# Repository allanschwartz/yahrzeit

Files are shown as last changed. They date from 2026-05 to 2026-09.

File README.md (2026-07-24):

# Yahrzeit Project Introduction

<a href="docs/images/yahrzeit-project-overview.png">
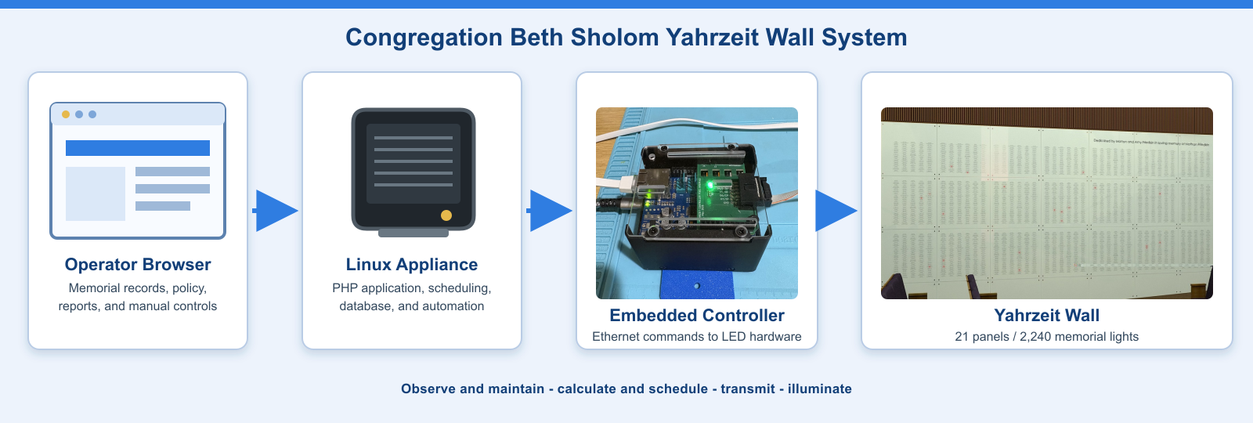
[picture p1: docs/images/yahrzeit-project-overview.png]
Congregation Beth Sholom Yahrzeit Wall system overview
  
</a>

*The operator interface and Linux appliance calculate and schedule memorial
lighting, while the embedded controller drives the physical Yahrzeit Wall.*

This repository contains the full Yahrzeit Wall system for Congregation Beth Sholom: the web appliance, scheduling logic, embedded controller firmware, LED hardware designs, and supporting documentation.

## What the project does

The system tracks memorial (Yahrzeit) records, determines when lights should be on, and sends commands to the physical wall so that the correct LEDs illuminate at the correct times.

## Repository layout

- `yahrzeit_site-v3/` — current PHP web application for viewing and editing memorial records, configuring synagogue policy, and running reports.
- `yahrzeit_site-v2/` — earlier web site implementation.
- `embedded/` — firmware and controller software for the embedded wall controller.
  - `yahrzeit_v1/` — original controller implementation.
  - `yahrzeit_v2/` — Arduino-based development work.
  - `yahrzeit_v3/` — newer controller and threading-based implementation.
- `Hardware/` — PCB and enclosure design files, schematics, and related hardware documentation.
- `panels/` — stored panel layouts and panel master assets used by the display system.
- `presentations/` — presentation materials and images related to the project.

## System overview

1. The web application stores memorial data and synagogue settings.
2. The scheduling/engine logic decides which names and panels should be lit.
3. The embedded controller receives commands and drives the LED wall.
4. The hardware layer defines the pixel boards, wiring, and panel geometry.

## Key concepts

- **Yahrzeit Wall** — the physical LED display.
- **Yahrzeit Appliance** — the software environment used by operators to manage the wall.
- **Embedded Controller** — the controller that talks to the LEDs.
- **Pixel Board / Light Engine** — the physical LED modules that make up the display.
- **Minhag / Lighting Policy** — synagogue-specific rules that determine when observances are active.

## Notes for contributors

- The current web application lives under [yahrzeit_site-v3](yahrzeit_site-v3).
- The embedded controller work is separate from the PHP appliance and should be treated as its own hardware/software subsystem.
- If you are updating documentation, prefer clear, project-level explanations that describe how the pieces fit together.

## See Also

- **Project**
  - [`./README.md`](README.md)
- **Server**
  - [`./yahrzeit_site-v3/README.md`](yahrzeit_site-v3/README.md)
  - [`./yahrzeit_site-v3/INSTALL.md`](yahrzeit_site-v3/INSTALL.md)
- **Controller**
  - [`./embedded/yahrzeit_v3/README.md`](embedded/yahrzeit_v3/README.md)
  - [`./embedded/yahrzeit_v3/INSTALL.md`](embedded/yahrzeit_v3/INSTALL.md)
- **Hardware**
  - [`./Hardware/README.md`](Hardware/README.md)

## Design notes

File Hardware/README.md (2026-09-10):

# Yahrzeit Wall Hardware

This directory contains the electrical and mechanical design files for the
Yahrzeit Wall controller, interface board, pixel boards, test fixtures, and
enclosures.

The current controller uses an Arduino Uno R4, an Arduino-compatible Ethernet
shield, and the Yahrzeit Controller Pixel Interface V3 board. The interface
board connects the controller stack to the installed chain of YYZ Pixel boards.

<a href="3D%20Printing/fixture_plate.jpg">
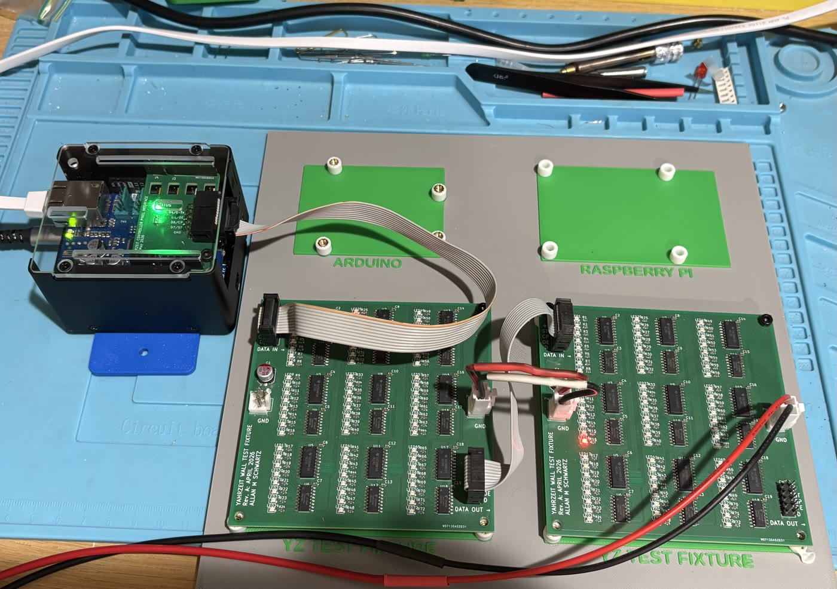
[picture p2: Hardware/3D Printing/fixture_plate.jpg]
Yahrzeit controller and YYZ Pixel bench-test fixture
  
</a>

*The bench-test fixture brings together the controller stack, Pixel Interface
board, and two nine-section YYZ Pixel boards.*

## 3D-Printed Parts

The files under [`3D Printing`](3D%20Printing/) may be browsed
online, with GitHub displaying the JPEG photographs and interactive previews of
the STL models.

### Commercial Controller Enclosure

- [arduino\_uno\_r4\_commercial\_enclosure\_vendor.jpg](3D%20Printing/arduino_uno_r4_commercial_enclosure_vendor.jpg)
  -- Vendor product photograph, saved from the Amazon listing, showing the
  commercial enclosure with an Arduino Uno R4 and an Ethernet-shield stack.

### Production Mounting Flange

The production controller uses a commercial enclosure with a custom
3D-printed flange that adapts its DIN-rail mounting feature for flat wall
mounting.

- [mount\_flange.scad](3D%20Printing/mount_flange.scad) -- Parametric OpenSCAD
  source.
- [mount\_flange.stl](3D%20Printing/mount_flange.stl) -- Printable mounting
  flange.

### Alternative Controller Enclosure

This enclosure was designed for the three-board controller stack. The
close-fitting commercial enclosure documented in the embedded-controller
installation notes is the preferred production enclosure, but this printable
design is retained as a replacement option and design reference.

- [yahrzeit\_controller\_case.scad](3D%20Printing/yahrzeit_controller_case.scad)
  -- Parametric OpenSCAD source.
- [yahrzeit\_controller\_case.stl](3D%20Printing/yahrzeit_controller_case.stl)
  -- Printable enclosure body.
- [yahrzeit\_controller\_case-cover.stl](3D%20Printing/yahrzeit_controller_case-cover.stl)
  -- enclosure cover.
- [yahrzeit\_controller\_case.jpg](3D%20Printing/yahrzeit_controller_case.jpg)
  -- Photograph of the printed enclosure body.

### Test-Fixture Plate

The fixture plate supports the small YYZ Pixel test assembly used during
controller development and bench testing.

- [fixture\_plate.scad](3D%20Printing/fixture_plate.scad) -- Parametric OpenSCAD
  source.
- [fixture\_plate.stl](3D%20Printing/fixture_plate.stl) -- Printable fixture
  plate.
- [fixture\_plate.jpg](3D%20Printing/fixture_plate.jpg) -- Photograph of the
  printed fixture plate.

## Yahrzeit Controller Pixel Interface V3

<a href="pixel_interface_v3/pixel_interface_v3-3D%20viewer.png">
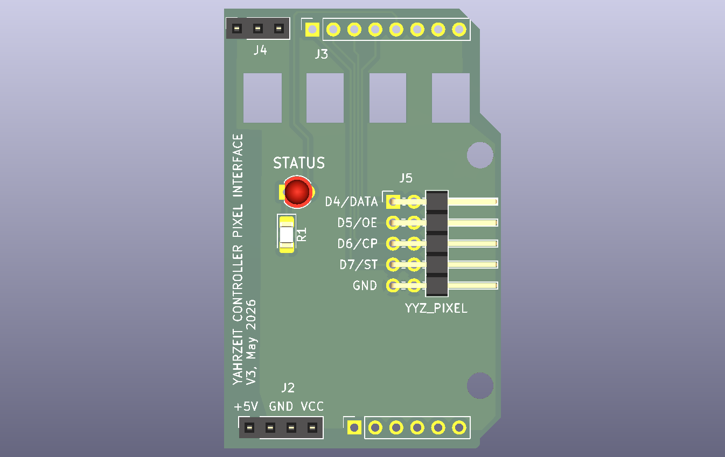
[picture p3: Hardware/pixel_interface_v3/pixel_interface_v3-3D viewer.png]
Yahrzeit Controller Pixel Interface V3 board
  
</a>

*KiCad rendering of the Yahrzeit Controller Pixel Interface V3 board.*

The current interface board adapts the Arduino controller stack to the
five-signal YYZ Pixel ribbon cable and provides the green ALIVE status LED.

- [pixel\_interface\_v3.kicad\_pro](pixel_interface_v3/pixel_interface_v3.kicad_pro)
  -- Open this project file in KiCad.
- [pixel\_interface\_v3.kicad\_sch](pixel_interface_v3/pixel_interface_v3.kicad_sch)
  -- KiCad schematic.
- [pixel\_interface\_v3.kicad\_pcb](pixel_interface_v3/pixel_interface_v3.kicad_pcb)
  -- KiCad PCB layout.
- [pixel\_interface\_v3-3D viewer.png](pixel_interface_v3/pixel_interface_v3-3D%20viewer.png)
  -- KiCad 3D rendering.
- [pixel\_interface\_v3-schematic.png](pixel_interface_v3/pixel_interface_v3-schematic.png)
  -- Schematic preview.
- [pixel\_interface\_v3\_D1\_polarity\_note.pdf](pixel_interface_v3/pixel_interface_v3_D1_polarity_note.pdf)
  -- Status-LED polarity and assembly note.

## Nine-Section YYZ Pixel Board

<a href="yahrzeit_pixel9/yahrzeit_pixel9.png">
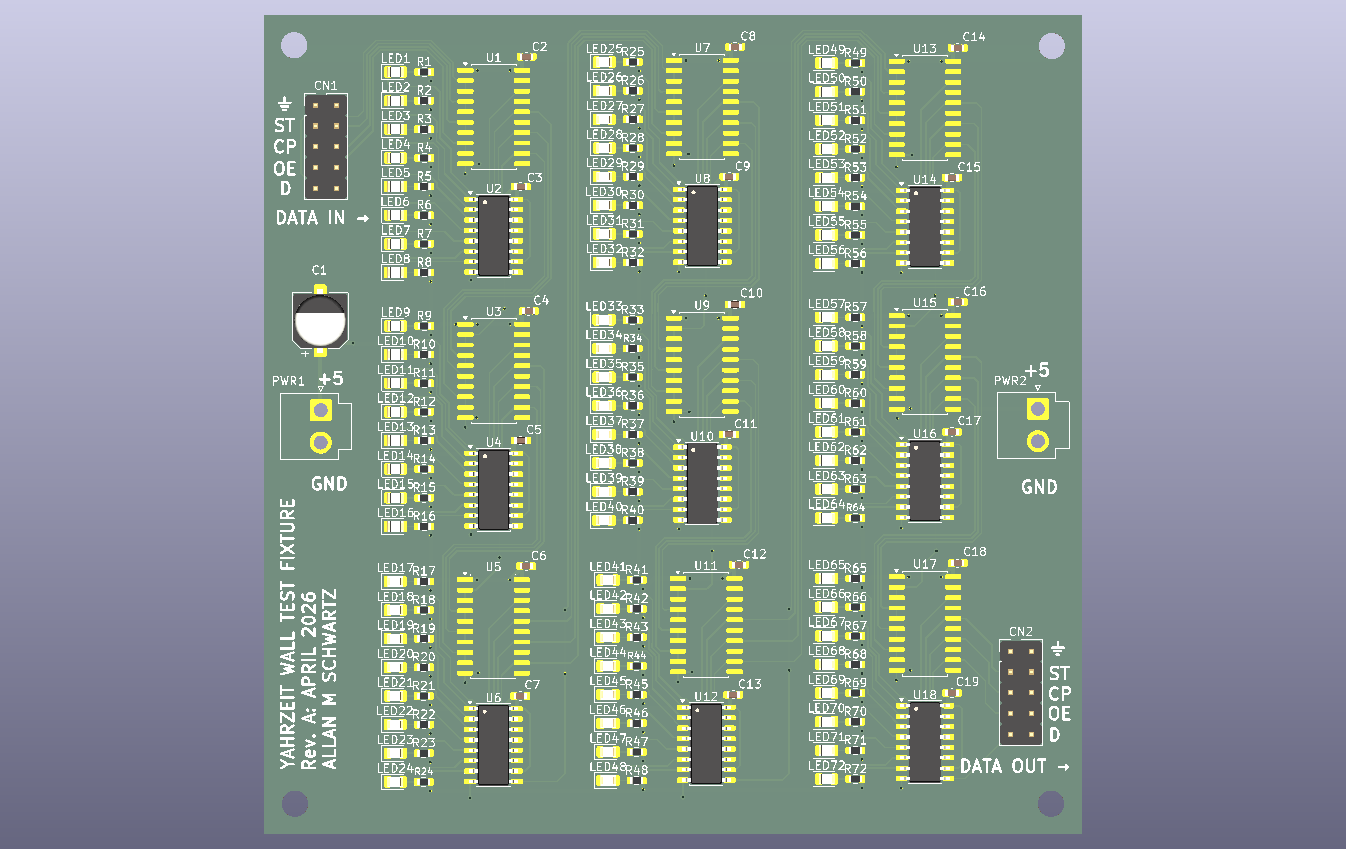
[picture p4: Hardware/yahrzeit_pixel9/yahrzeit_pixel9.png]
Nine-section YYZ Pixel board
  
</a>

*KiCad rendering of the nine-section YYZ Pixel board.*

The `yahrzeit_pixel9` board combines nine complete YYZ Pixel circuits on one PCB, using the same octal bus transceiver and 8-bit shift register as the individual boards installed in the wall. A single `yahrzeit_pixel9` behaves as one complete Yahrzeit Wall panel, allowing a desktop test fixture to be constructed. Two or more yahrzeit_pixel9 boards may be chained together to emulate multiple panels.

<a href="schematics/yyz_pixel_8_pixel_hierarchical_sheet.png">
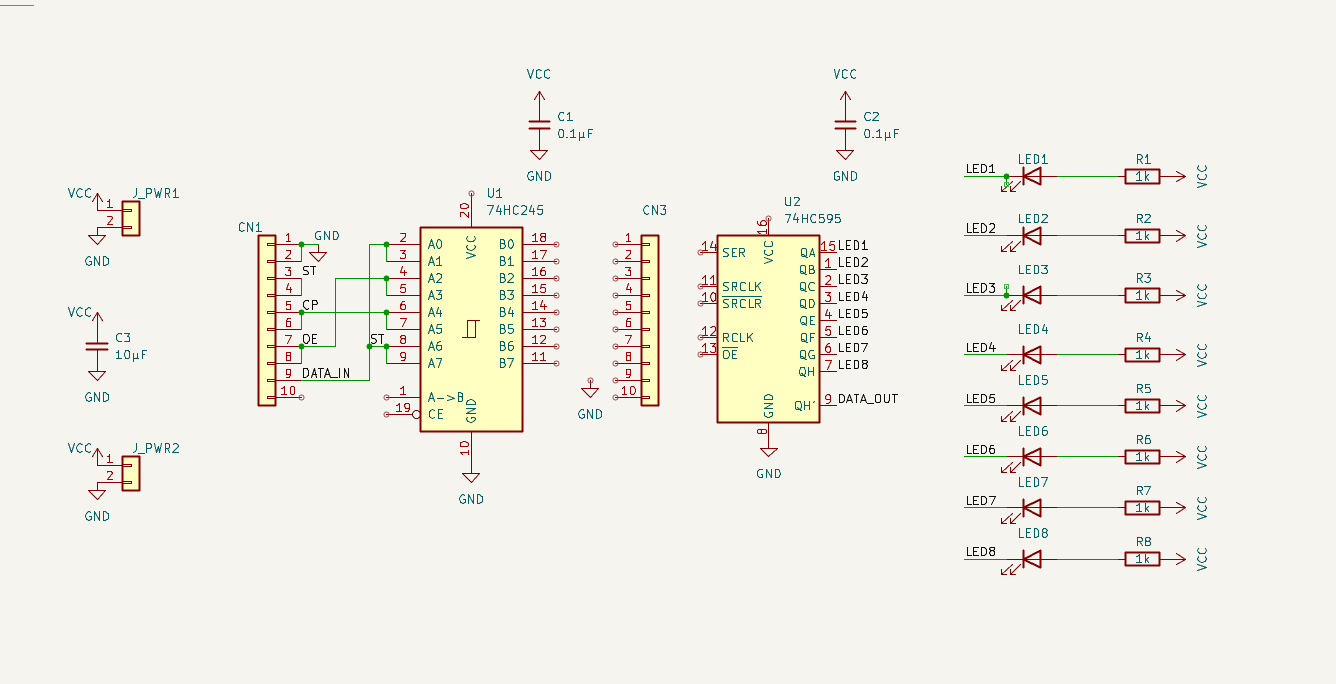
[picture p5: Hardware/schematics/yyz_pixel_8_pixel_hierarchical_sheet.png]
Reusable eight-pixel YYZ Pixel hierarchical sheet
  
</a>

*The reusable KiCad hierarchical sheet implements one eight-pixel YYZ Pixel
circuit. The `yahrzeit_pixel9` top-level schematic instantiates this sheet nine
times.*

- [yahrzeit\_pixel9.kicad\_pro](yahrzeit_pixel9/yahrzeit_pixel9.kicad_pro) --
  Open this project file in KiCad.
- [yahrzeit\_pixel9.kicad\_sch](yahrzeit_pixel9/yahrzeit_pixel9.kicad_sch) --
  KiCad top-level schematic.
- [pblock.kicad\_sch](yahrzeit_pixel9/pblock.kicad_sch) -- Reusable
  eight-pixel hierarchical sheet.
- [yahrzeit\_pixel9.kicad\_pcb](yahrzeit_pixel9/yahrzeit_pixel9.kicad_pcb) --
  KiCad PCB layout.
- [yahrzeit\_pixel9-schematic.pdf](yahrzeit_pixel9/yahrzeit_pixel9-schematic.pdf)
  -- multipage schematic.
- [yahrzeit\_pixel9.png](yahrzeit_pixel9/yahrzeit_pixel9.png) -- KiCad board
  rendering.

## YYZ Pixel Board V2

<a href="yahrzeit_yyz_pixel-v2/yyz_pixel-v2%20schematic.png">
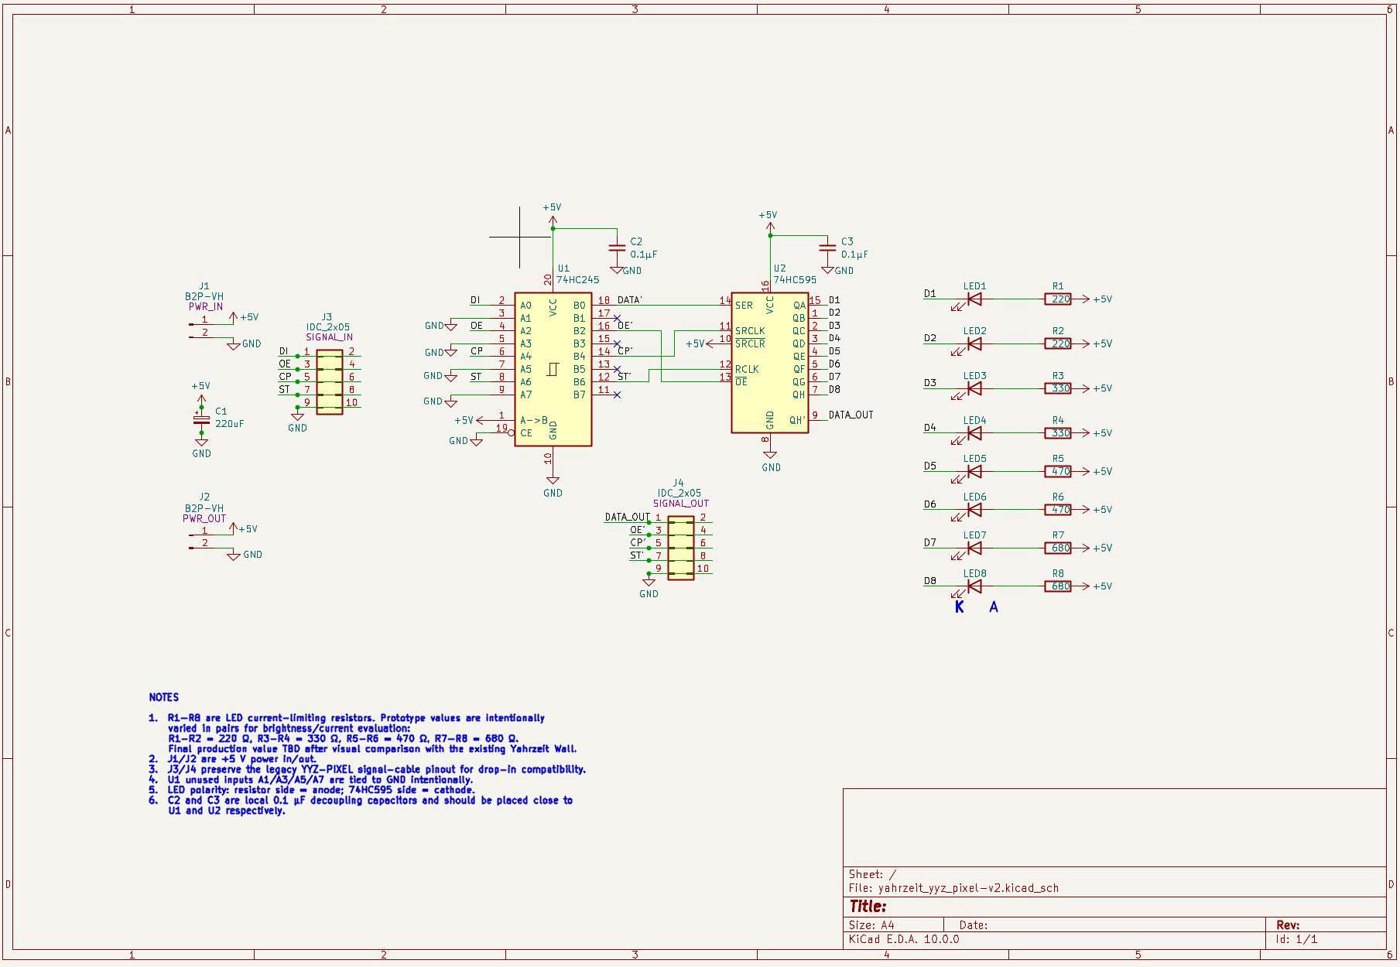
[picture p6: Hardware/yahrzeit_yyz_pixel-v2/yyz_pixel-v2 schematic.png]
YYZ Pixel Board V2 schematic
  
</a>

*Schematic of the preliminary YYZ Pixel Board V2 design.*

YYZ Pixel Board V2 is a proposed modern replacement for an individual
installed pixel board. It retains the legacy 74HC245 input buffer, 74HC595
shift register, 5 V power daisy chain, and 2x5 signal-cable interface so that
it can be evaluated with the existing wall and controller. The present
prototype provides eight LED channels. Its LED resistors intentionally use
four different values, in pairs, so brightness and current can be compared
with the original wall before a production value is selected.

This is design work in progress, not a released production board. Connector
part numbers, the final LED resistor value, cable construction, power margin,
and mechanical fit must be confirmed before fabrication or installation.

- [yahrzeit\_yyz\_pixel-v2.kicad\_pro](yahrzeit_yyz_pixel-v2/yahrzeit_yyz_pixel-v2.kicad_pro)
  -- Open this project file in KiCad.
- [yahrzeit\_yyz\_pixel-v2.kicad\_sch](yahrzeit_yyz_pixel-v2/yahrzeit_yyz_pixel-v2.kicad_sch)
  -- KiCad schematic.
- [yahrzeit\_yyz\_pixel-v2.kicad\_pcb](yahrzeit_yyz_pixel-v2/yahrzeit_yyz_pixel-v2.kicad_pcb)
  -- Preliminary KiCad PCB layout.
- [YYZ\_PIXEL\_V2\_CABLE\_AND\_POWER\_NOTES.md](YYZ_PIXEL_V2_CABLE_AND_POWER_NOTES.md)
  -- Field observations and deferred cable, signal-integrity, and power-design
  decisions.

## Column Power Distribution Board

<a href="yahrzeit_power_dist/yahrzeit_power_dist.png">
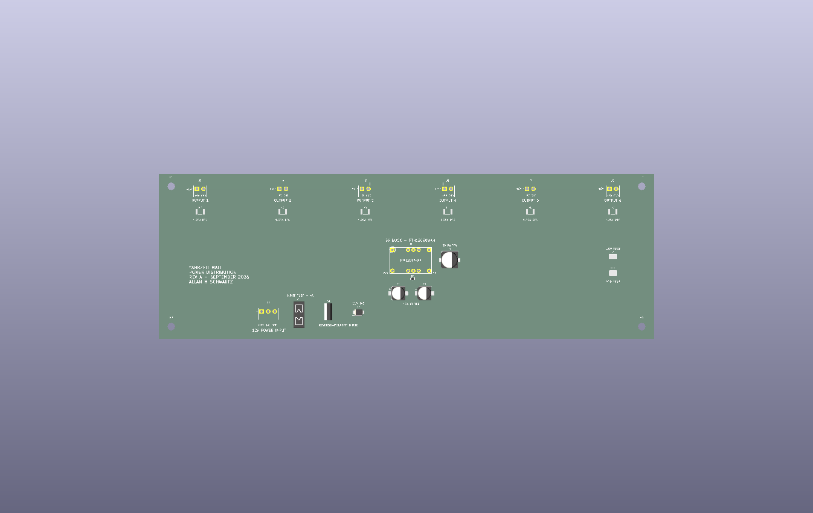
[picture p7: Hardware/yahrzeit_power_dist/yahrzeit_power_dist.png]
Yahrzeit Wall column power-distribution board
  
</a>

*Preliminary layout of the proposed column power-distribution board.*

The proposed power-distribution assembly replaces the direct 5 V supply and
wire-nut fan-out for one vertical panel column. One assembly serves six
56-LED branches. It accepts nominal 12 V input, uses a TI PTH12060WAH
through-hole module to produce regulated 5 V, and provides six individually
protected outputs. Input reverse-polarity and transient protection, local
filtering, clearly polarized connectors, and accessible 5 V/GND test points
make the assembly easier to diagnose and replace in the field.

The long-term concept uses one assembly for each of the wall's seven panel
columns, plus complete spare assemblies and purpose-built labeled cables. The
entire board-and-cable assembly is intended to be a field-replaceable unit.
The design remains preliminary: measured wall current, fuse ratings, thermal
performance, copper geometry, connector selections, cable lengths, and
installation clearances must be verified before production.

- [yahrzeit\_power\_dist.kicad\_pro](yahrzeit_power_dist/yahrzeit_power_dist.kicad_pro)
  -- Open this project file in KiCad.
- [yahrzeit\_power\_dist.kicad\_sch](yahrzeit_power_dist/yahrzeit_power_dist.kicad_sch)
  -- KiCad schematic.
- [yahrzeit\_power\_dist.kicad\_pcb](yahrzeit_power_dist/yahrzeit_power_dist.kicad_pcb)
  -- Preliminary PCB placement and routing.
- [power\_dist.schematic.pdf](yahrzeit_power_dist/power_dist.schematic.pdf) -- Current schematic
  PDF for review without KiCad.
- [yahrzeit\_power\_dist.png](yahrzeit_power_dist/yahrzeit_power_dist.png) --
  KiCad board rendering.
- [DESIGN\_TODO.md](yahrzeit_power_dist/DESIGN_TODO.md) -- Outstanding
  component-selection, indicator, layout, and pre-fabrication checks.

## Reference Schematics

Approximately 280 individual YYZ Pixel boards are installed behind the
Yahrzeit Wall's etched-glass memorial panels. Three variations support six,
eight, or ten memorial lights. Their common circuit is documented in:

- [Schematic\_yyz\_pixel.pdf](schematics/Schematic_yyz_pixel.pdf) -- Original
  installed YYZ Pixel board schematic.
- [YYZ\_PIXEL\_BOARD\_REPAIR.md](YYZ_PIXEL_BOARD_REPAIR.md) -- Customer procedure
  for replacing and verifying an installed pixel board using a tested spare.
- [YYZ\_PIXEL\_BOARD\_TESTING.md](YYZ_PIXEL_BOARD_TESTING.md) -- Optional
  engineering or electronics-technician procedure for bench-testing a removed
  board, including the special controller cable and Saleae logic-analyzer
  checks.
- [YYZ\_PIXEL\_V2\_CABLE\_AND\_POWER\_NOTES.md](YYZ_PIXEL_V2_CABLE_AND_POWER_NOTES.md)
  -- Deferred Version 2 design notes covering signal-cable construction,
  shielding and grounding alternatives, field cable-retention observations,
  and power-supply margin.
  
The nine-section board is electrically nine of these circuits condensed onto
one PCB. Both designs use the same 74HC245 octal bus transceiver and
74HC595 8-bit shift register:

- [74HC\_HCT245.pdf](schematics/74HC_HCT245.pdf) -- Bus-transceiver data sheet.
- [74HC\_HCT595.pdf](schematics/74HC_HCT595.pdf) -- Shift-register data sheet.

The [`schematics`](schematics/) directory also preserves the relevant Arduino
and Ethernet reference schematics.

## See Also

- **Project**
  - [`./README.md`](../README.md)
- **Server**
  - [`./yahrzeit_site-v3/README.md`](../yahrzeit_site-v3/README.md)
  - [`./yahrzeit_site-v3/INSTALL.md`](../yahrzeit_site-v3/INSTALL.md)
- **Controller**
  - [`./embedded/yahrzeit_v3/README.md`](../embedded/yahrzeit_v3/README.md)
  - [`./embedded/yahrzeit_v3/INSTALL.md`](../embedded/yahrzeit_v3/INSTALL.md)
- **Hardware**
  - [`./Hardware/README.md`](README.md)

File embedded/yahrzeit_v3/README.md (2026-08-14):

# Yahrzeit Embedded Controller

This directory contains the Arduino firmware for the third-generation
Yahrzeit Wall embedded controller.

This README is intended for future maintainers of the embedded controller.

The top-level repository README explains the full Yahrzeit project. The
`yahrzeit_site-v3` README explains the PHP/Linux appliance. This README is only
about the Arduino controller firmware in this directory. See `INSTALL.md` for
the production firmware build, upload, and verification procedure.

<p align="center">
  <a href="images/yahrzeit-controller-assembly.jpg">
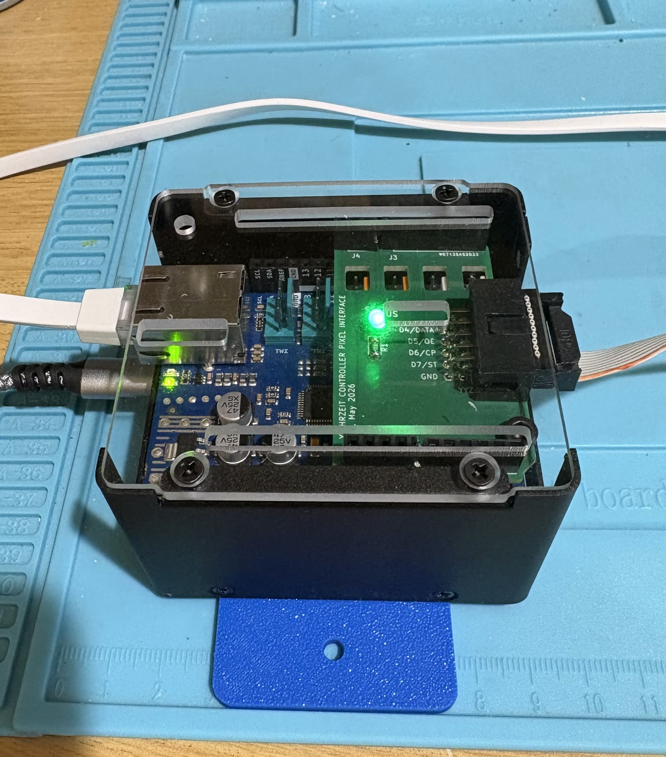
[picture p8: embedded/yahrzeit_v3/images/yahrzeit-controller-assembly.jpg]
Yahrzeit Embedded Controller V3 assembly
    
  </a>
</p>

*The assembled controller in its close-fitting enclosure. The illuminated
green LED on the Pixel Interface board is the ALIVE indicator.*

## What This Controller Does

The embedded controller:

- receives line-oriented ASCII commands over USB serial or Ethernet TCP,
- maintains the LED wall framebuffer,
- maps wall/panel coordinates to the physical pixel chain,
- refreshes the shift-register LED hardware,
- saves and loads display state through EEPROM,
- runs bring-up and self-test patterns,
- and reports status/version/network information for diagnostics.

The normal production control path is:

```text
PHP appliance bin/yahrzeit
  -> nc TCP connection
    -> Arduino Ethernet socket on port 2001
      -> socket_thread.ino
        -> CmdProc
          -> LedWall
            -> YyzPixel
```

The command line interface is normally accessed through a TCP connection,
and received in `socket_thread.ino`.  
However, USB serial uses the same command processor through `serial_thread.ino`.

## Hardware Stack

The V3 controller stack is:

```text
Arduino Uno R4 Minima
  -> Arduino Ethernet Shield 2 or compatible W5100/W5500 shield
    -> Yahrzeit Controller Pixel Interface board
      -> ribbon cable to YYZ Pixel board chain
```

### Ethernet Shield

The Ethernet shield uses the Arduino SPI interface; D10 is the chip select:

```text
D10     CS      Chip select
D11     MOSI    Master out, slave in  (aka COPI)
D12     MISO    Master in, slave out  (aka CIPO)
D13     SCK     Serial clock
```

## Pin Assignments

Pin definitions live in `yahrzeit_v3.ino`.

Names `DI`, `OE`, `CP`, `ST` match the pixel interface board silkscreen, and likewise the YYZ PIXEL boards silkscreen:

```text
STATUS LED  D3
DI          D4    data input (input to the PIXEL board)
OE          D5    output enable, active low
CP          D6    clock pulse
ST          D7    store/latch pulse
```

Do not change these casually; the shield/interface wiring depends on them.

## Source Files

- `yahrzeit_v3.ino` - setup, main loop, startup sequence, network defaults,
  pin definitions, global objects, status LED, panic handling.
- `yahrzeit_v3.h` - project-wide constants, active geometry selection,
  configuration structs, externs, assertion macros, shared declarations.
- `socket_thread.ino/.h` - Ethernet initialization and TCP command input.
- `serial_thread.ino/.h` - USB serial command input.
- `CmdProc.cpp/.h` - ASCII command parser and dispatcher.
- `LedWall.cpp/.h` - logical wall/panel abstraction and coordinate mapping.
- `YyzPixel.cpp/.h` - packed framebuffer and low-level shift-register driver.
- `selftest.ino/.h` - self-test patterns.

## Active Geometry

Select exactly one geometry in `yahrzeit_v3.h`:

```cpp
// #define CBS_56x40_WALL    1
#define TEST_FIXTURE    1
```

Current geometry definitions in `LedWall.cpp`:

```text
CBS_56x40_WALL:
  56 rows x 40 columns
  21 logical panels

TEST_FIXTURE:
  24 rows x 6 columns
  2 logical panels
  each fixture panel is 24 rows x 3 columns
```

For production installation, enable `CBS_56x40_WALL` and disable
`TEST_FIXTURE`.

## Network Defaults

Network defaults are in `yahrzeit_v3.ino`.

Production/CBS wall defaults:

```cpp
NetworkConfig networkConfig = {
    .mac = { 0x02, 0x19, 0x55, 0x11, 0x00, 0x09 },
        // Values used at Congregation Beth Sholom
        .ipAddr = IPAddress(192, 168, 13, 9),
        .dnsAddr = IPAddress(8, 8, 8, 8),
        .gateway = IPAddress(192, 168, 13, 8),
        .subnet = IPAddress(255, 255, 255, 0),
};

static constexpr uint16_t SOCKET_LISTEN_PORT = 2001;
```

There are also defaults for Allan's home-lab:

```text
IP       192.168.86.240
Gateway  192.168.86.1
Subnet   255.255.255.0
Port     2001
```

The PHP appliance reads the controller hostname/address and TCP port from
`bin/yahrzeit-controller.conf`. During installation, it offers the previously
recorded controller host as the default. The resulting appliance host and port
must match the values installed in the controller firmware.

## Ethernet Notes

`socket_thread.ino` supports W5100/W5200/W5500-class Ethernet hardware through the Arduino Ethernet library.

Startup serial output reports the detected Ethernet chip and local IP address.

The code treats only an explicit `LinkOFF` as unavailable. This matters because
some W5100-class hardware may not report link status as `LinkON` even when
socket communication works.

The `status` command reports the Arduino board model, selected display
configuration, dimensions, current brightness, configured network addresses
and TCP port, detected Ethernet hardware, link state, and whether a TCP client
is currently connected. It can be issued through USB Serial Monitor even when
TCP communication is not working, making it the primary tool for diagnosing
network problems.

The `version` command reports the Git-derived firmware release identifier and
the date and time at which the firmware was compiled. The release identifier
is generated as part of the build procedure documented in `INSTALL.md`.

## Serial Console

USB serial is initialized at:

```text
115200 baud
```

The serial path and socket path both feed the same command processor.

## Command Protocol

Commands are ASCII, line-oriented, and may usually be abbreviated to the first
two letters.

### Commands Used by the PHP Appliance

```text
All  on|off [<panel>]
BRightness <n> (1:bright, 254:dim)
PIxel on|off <row> <col> [<panel>]
REfresh
SAve
```

### Additional Controller Commands

```text
DAta <row> <col> <binary data>
LOad
```

### Maintenance and Diagnostic Commands

```text
DUmp [<panel>]
GEometry <rows> [<cols>]
HElp
STatus
TEst <testnumber> [<panel>]
TIming on|off
VErsion
```

`PANEL0` / panel `0` means the whole active display. Panels `1` through
`displayConfig.nPanels` address individual logical panels.

### Runtime test geometry

Use the `GEOMETRY` command to temporarily redefine the active display as one
continuous logical panel. The column count defaults to one:

```text
geometry 6
geometry 8
geometry 10
geometry 24 6
```

The configuration is cleared and remains active until the controller is
reset. Reset restores the geometry selected at compile time. Confirm the
runtime setting with `status`, then use the standard tests:

```text
test 2
test 3
test 4
test 5
```

For a single YYZ_PIXEL board, select its physical pixel count as the row count
and retain the default single column. The abbreviated command form, such as
`ge 8` and `te 5`, is also accepted.

## Self Tests

The `TEST` command supports:

```text
TEst 1 [<panel>]  -- 4 corners ON
TEst 2 [<panel>]  -- all pixels ON
TEst 3 [<panel>]  -- all pixels OFF
TEst 4 [<panel>]  -- checkerboard test
TEst 5 [<panel>]  -- marching row pattern
TEst 6 [<panel>]  -- marching column pattern
```

Use `*` in place of the optional panel number to repeat a test separately for
every physical panel, in panel-number order:

```text
test 1 *
test 5 *
```

An omitted panel still means the whole active display. For example, `test 1`
turns on the four corners of the complete wall, while `test 1 *` turns on the
four corners of each individual panel.

## Startup Behavior

On startup, `setup()`:

1. enables the status LED,
2. starts USB serial,
3. initializes Ethernet,
4. starts the command socket if Ethernet is available,
5. initializes the pixel driver and wall abstraction,
6. prints the version string,
7. runs a short light-test sequence,
8. loads the last saved framebuffer from EEPROM,
9. refreshes the display.

## Safe Bench Tests

Serial console:

```text
?
status
version
timing on
refresh
test 1
test 2
test 3
test 4
```

TCP socket from a machine on the same network:

```sh
nc <controller-ip> 2001
```

Then type the same line-oriented commands.

This is the direct test of TCP communication between the appliance and the
embedded controller. In particular, enter:

```text
version
status
```

For complete appliance-to-controller verification, follow the build, upload,
and commissioning procedure in [INSTALL.md](INSTALL.md).

## Building and Installing

See [INSTALL.md](INSTALL.md) for the known-working Arduino toolchain,
production geometry and network configuration, Git-derived release identifier,
firmware compilation and upload, verification tests, and installation record.

## Maintenance Warnings

- Do not change the command protocol unless the PHP appliance and embedded controller are updated at the same time.
- Do not change panel geometry without checking `LedWall.cpp` and PHP-side panel mapping.
- Do not leave home-lab IP addresses or `TEST_FIXTURE` enabled for production.
- Be careful with display refresh timing and framebuffer layout.
- Do not run live wall commands unless the physical wall can safely change state.

## See Also

- **Project**
  - [`./README.md`](../../README.md)
- **Server**
  - [`./yahrzeit_site-v3/README.md`](../../yahrzeit_site-v3/README.md)
  - [`./yahrzeit_site-v3/INSTALL.md`](../../yahrzeit_site-v3/INSTALL.md)
- **Controller**
  - [`./embedded/yahrzeit_v3/README.md`](README.md)
  - [`./embedded/yahrzeit_v3/INSTALL.md`](INSTALL.md)
- **Hardware**
  - [`./Hardware/README.md`](../../Hardware/README.md)

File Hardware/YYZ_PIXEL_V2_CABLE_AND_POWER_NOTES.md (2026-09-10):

# YYZ Pixel V2 Cable and Power Notes

**Status:** Deferred design work
**Recorded:** August 22, 2026

These notes preserve field observations and design alternatives to revisit
before releasing the YYZ Pixel V2 boards and cable assemblies for production.
They are not yet production requirements.

## Existing Wall Installation

The existing 10-conductor signal ribbon cables are routed flat and straight
against the rear of the continuous aluminum chassis. They are presently held
in place with ordinary blue painter's tape.

During the August 2026 service visit, one signal cable was found hanging loose
rather than adhered to the chassis. It was secured again. The loose cable may
have contributed to the observed intermittent signal or clock problems, but
this was not proven conclusively.

Keeping the ribbon cable flat against the aluminum may reduce movement, loop
area, and coupling from nearby wiring. Painter's tape is useful for temporary
field work, but its adhesive should not be treated as a long-term production
cable-retention method. Consider durable cable clips, tie mounts, or another
serviceable mechanical restraint for the Version 2 installation.

## Shielded Ribbon-Cable Options

Shielded cable compatible with 0.050-inch-pitch IDC mass termination is
commercially available. Candidate product families include:

- [3M 90204 Series](https://www.3m.com/3M/en_US/p/d/b00039655/) - flat,
  pleated-copper-foil shielded cable; 28 AWG; available with 10 conductors;
  intended for IDC mass termination.
- [3M 3659 Series](https://www.3m.com/3M/en_US/p/d/b00039391/) - round,
  shielded and jacketed flat cable with periodic flat sections for IDC
  termination; potentially useful for the approximately 2.8-meter long run.
- [3M 1785 Series](https://www.3m.com/3M/en_US/p/d/b00039714/) - shielded,
  twisted-pair flat cable; available as 10 conductors/five pairs; 28 AWG on
  0.050-inch centers.
- [3M HF017 Series](https://www.3m.com/3M/en_US/p/d/b10098196/) - shielded,
  IDC-compatible, low-smoke/zero-halogen cable that may be appropriate for a
  permanent installation in a public building.

A standard plastic 2x5 IDC socket does not terminate the cable shield.
Any shielded-cable specification must therefore define:

- how the shield or drain conductor exits the jacket;
- where it connects to chassis or circuit ground;
- whether it is connected at one end or both ends;
- strain relief at each jacket-to-ribbon transition; and
- the permitted length of unshielded ribbon at each connector.

Shielding alone may not correct the underlying signal-integrity problem.
Pairing each important signal, especially `CP`, with a ground conductor may be
more useful than retaining the legacy arrangement of duplicated adjacent
signals. Before completing CBL-05 and CBL-06, reconsider the signal pinout,
ground allocation, connector polarization, and whether the new system must
remain directly compatible with every legacy cable.

Current cable definitions are in [`cables/`](cables/):

- `CBL-05-idc-100mm.yml` - short board-to-board signal jumper.
- `CBL-06-idc-2800mm.yml` - provisional long signal interconnect.

Their rendered WireViz PDF drawings are working documents. Cable and connector
manufacturer part numbers still need to be selected before production.

## Power-Supply Margin

The installed supplies are nominally **5 V, 5 A**. At least one supply was
found to be bad during the August 2026 service work. The remaining design also
appears to operate close to the supplies' current limit when all LEDs are on.

The installed YYZ Pixel boards use **220-ohm LED current-limiting resistors**.
One supply powers approximately six columns by 56 rows, or 336 LEDs. Assuming
an LED forward voltage between 1.8 V and 2.2 V:

```text
Current per LED = (5 V - Vf) / 220 ohms

Vf = 1.8 V:  14.5 mA per LED; 336 LEDs = 4.89 A
Vf = 2.0 V:  13.6 mA per LED; 336 LEDs = 4.58 A
Vf = 2.2 V:  12.7 mA per LED; 336 LEDs = 4.28 A
```

This estimate covers LED current only. It leaves little or no allowance for:

- logic and controller current;
- voltage loss in connectors, cables, and distribution wiring;
- component tolerances;
- power-supply derating and aging; or
- transient behavior when the display changes.

Field testing showed that the affected sections behaved correctly with all
LEDs commanded on when output-enable PWM reduced average brightness/current.
That observation is consistent with inadequate power margin, although voltage
and current should be measured before selecting replacement supplies.

Before releasing the Version 2 design:

1. Measure actual current and voltage at the supply and at the farthest board
   with representative LEDs fully on.
2. Select the final Version 2 LED resistor value from visual and electrical
   testing.
3. Establish a continuous-current design target with suitable engineering
   margin rather than sizing the supply at the calculated maximum load.
4. Review connector, wire, fuse, and distribution-board ratings against that
   target.

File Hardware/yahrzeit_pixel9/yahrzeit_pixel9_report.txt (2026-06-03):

PCB statistics report
=====================
- Date: Wednesday, April 08, 2026 at 01:18:32 PM
- Project: yahrzeit_pixel
- Board name: yahrzeit_pixel

Board
-----
- Width: 100.0000 mm
- Height: 100.0000 mm
- Area: 10000.00 mm²
- Front copper area: 7231.295 mm²
- Back copper area: 8935.98 mm²
- Min track clearance: 0.2000 mm
- Min track width: 0.2000 mm
- Min drill diameter: 0.3000 mm
- Board stackup thickness: 1.6000 mm

- Front footprint area: 3174.604 mm²
- Back footprint area: 135.09 mm²
- Front component density: 31.75 %
- Back component density: 1.35 %
Pads
----
- Through hole: 24
- SMD: 650
- Connector: 0
- NPTH: 4
- Castellated: 0
- Press-fit: 0

Vias
----
- Through vias: 208
- Blind vias: 0
- Buried vias: 0
- Micro vias: 0

Components
----------

| | Front Side | Back Side | Total |
|---|---|---|---|
|THT: | 4 | 0 | 4 |
|SMD: | 181 | 0 | 181 |
|Unspecified:  | 4 | 0 | 4 |
|Total: | 189 | 0 | 189 |

Drill holes
-----------

| Count | Shape | X Size | Y Size | Plated | Via/Pad | Start Layer | Stop Layer |
|---|---|---|---|---|---|---|---|
| 208 | Round | 0.3000 mm | 0.3000 mm | PTH | Via | F.Cu | B.Cu |
| 20 | Round | 1.0000 mm | 1.0000 mm | PTH | Pad | F.Cu | B.Cu |
| 4 | Round | 1.7000 mm | 1.7000 mm | PTH | Pad | F.Cu | B.Cu |
| 4 | Round | 3.2000 mm | 3.2000 mm | NPTH | Pad | F.Cu | B.Cu |

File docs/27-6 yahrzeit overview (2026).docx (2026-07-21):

### 27-6 Yahrzeit Wall Overview

The Yahrzeit Panels are etched glass panels with an automated lighting mechanism. These panels memorialize the names and dates of death of members of the congregation or their families.

In observance of individual Yahrzeit and Yizkor dates, memorial LEDs are lit and extinguished according to programmed synagogue policy, typically at the start of the Shabbat preceding the Yahrzeit. Yahrzeit and Yizkor dates may be based on either the Jewish or the secular (Gregorian) calendar. The memorial LED lighting time may be scheduled automatically, triggered manually, based on sunset, or set to a fixed time.

Manufacturer: On-Site Systems Inc. http://www.on-sitesystems.com (http://osshome.com/)

Yyz Systems Inc http://www.yyzsystems.com
Allan Schwartz (server and controller)

Model Number: custom installation

Maintenance: Clean the glass monthly, with Windex wipes or equivalent

Service: Glass – On-Site Systems

Electronics – Yyz Systems

Software – Allan Schwartz

Repair/reprint panels of glass – On-Site Systems

Location: Sanctuary west wall

Installers: On-Site Systems Inc. http://www.on-sitesystems.com (http://osshome.com/)

Gary Taylor gary@on-sitesystems.com 800-838-7778

Yyz Systems Inc http://www.yyzsystems.com

Marko Hajdinovic marko@yyzsystems.com 905-795-8500

Allan Schwartz allanschwartz@sbcglobal.net 669-350-7296

## Physical Wall Overview

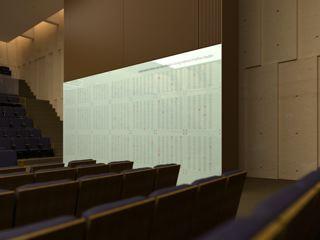
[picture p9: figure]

The Yahrzeit Wall comprises the Glass Panels (see section 27-7 Yahrzeit Panels), the embedded electronics in the wall, and the Yahrzeit Server software running on the Yahrzeit appliance or server (see section 27-8 Yahrzeit Server).

This document doesn’t discuss how the software operates, or is layered, or how the end-user interfaces with this software. See section 27-8 Yahrzeit Server.

This document doesn’t discuss the glass, or how to create or modify the panels. See section 27-7 Yahrzeit Panels.

### Purpose of the System

The Yahrzeit System provides a browser-based interface for maintaining memorial records, configuring synagogue lighting policy, checking wall status, and operating the calendar-based Yahrzeit and Yizkor lighting schedule. The user interface is a set of browser pages, such as:

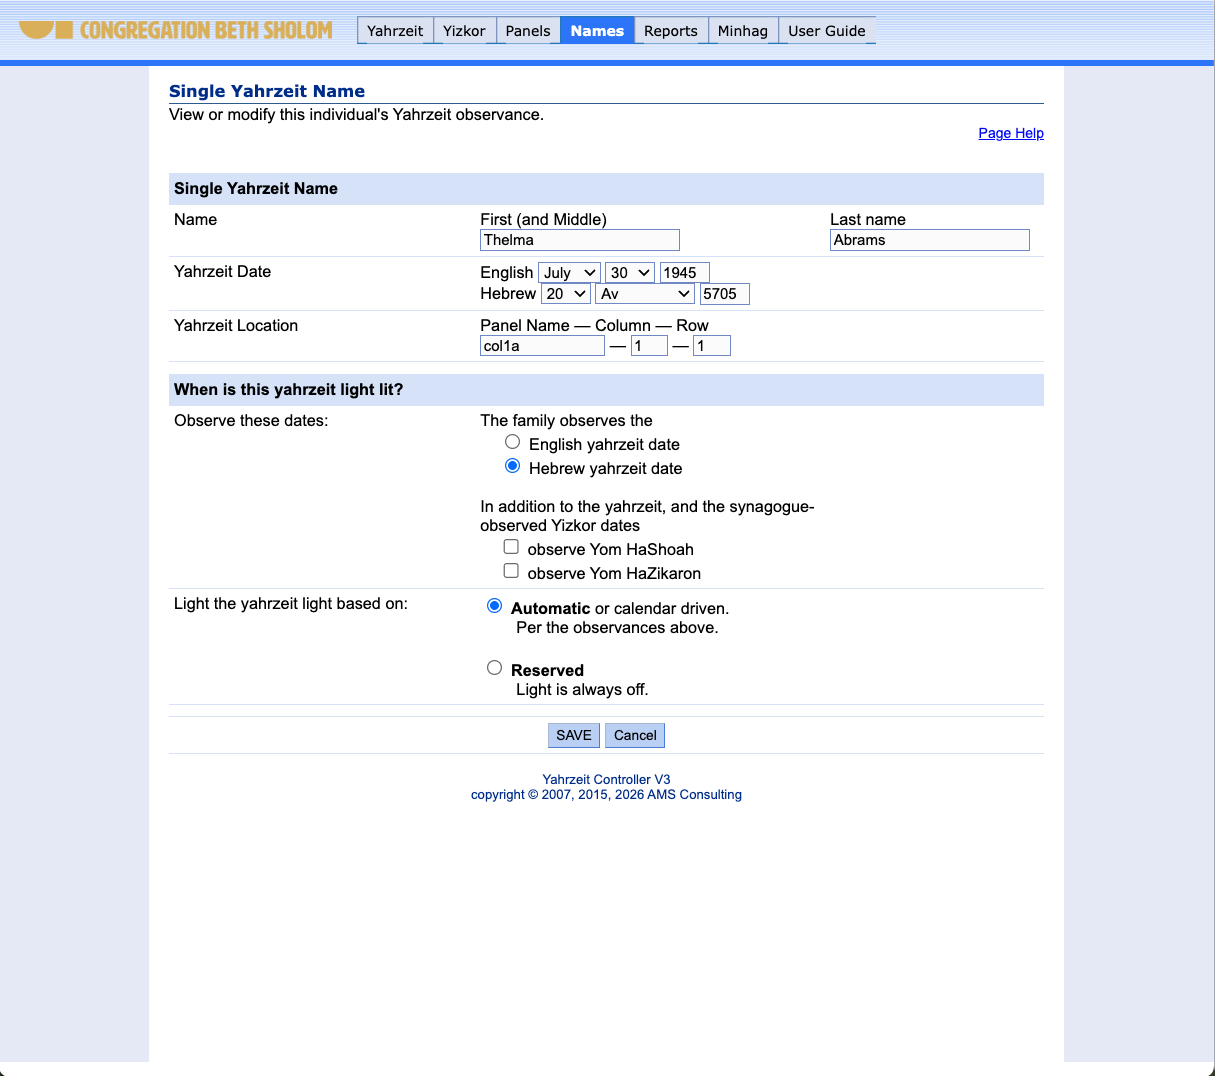
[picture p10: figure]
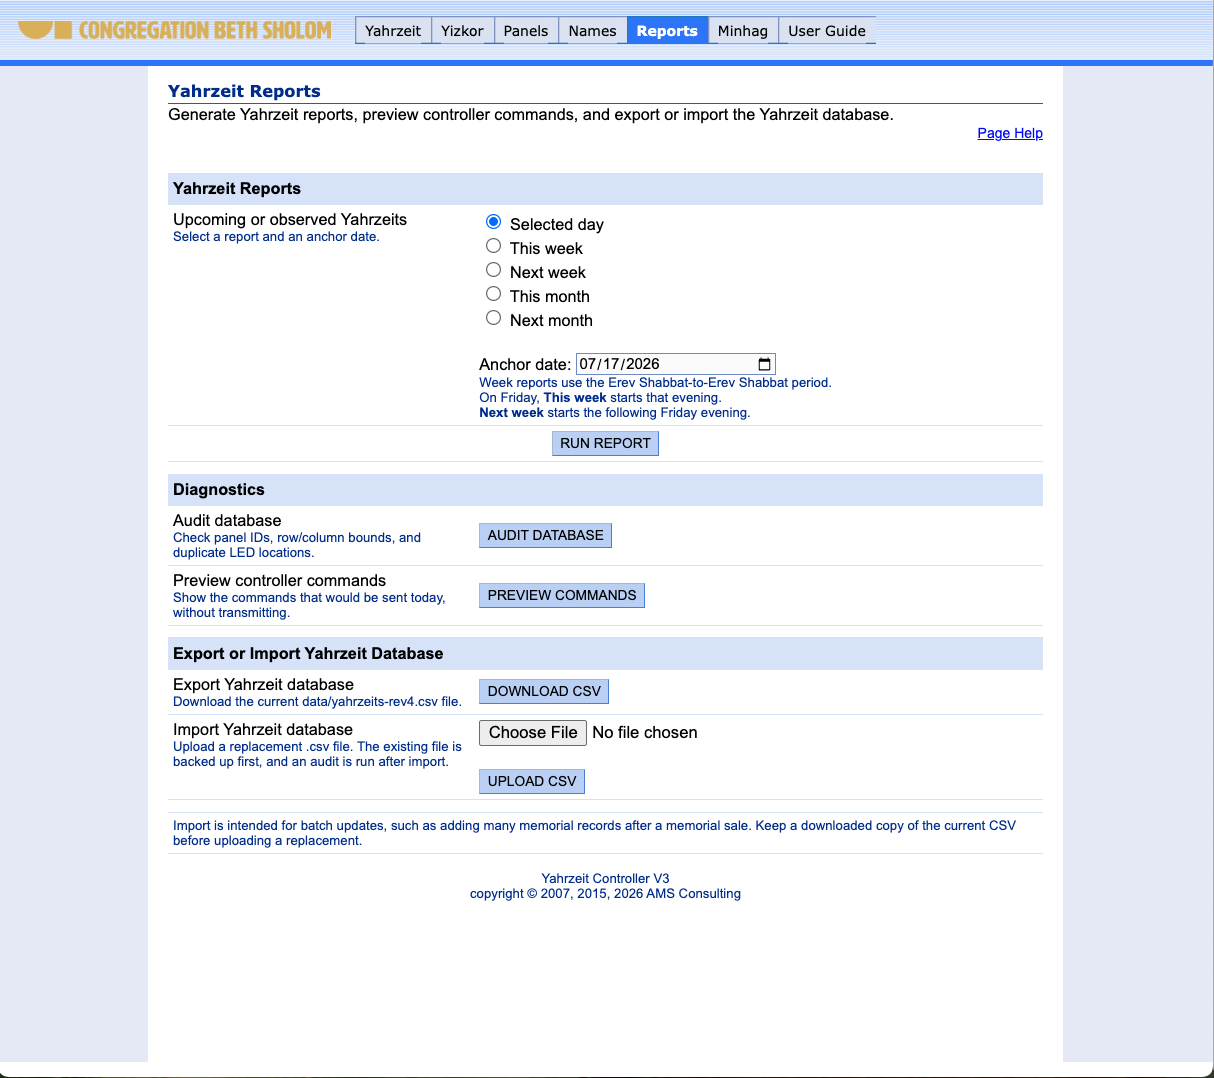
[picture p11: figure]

### The Yahrzeit Wall Structure

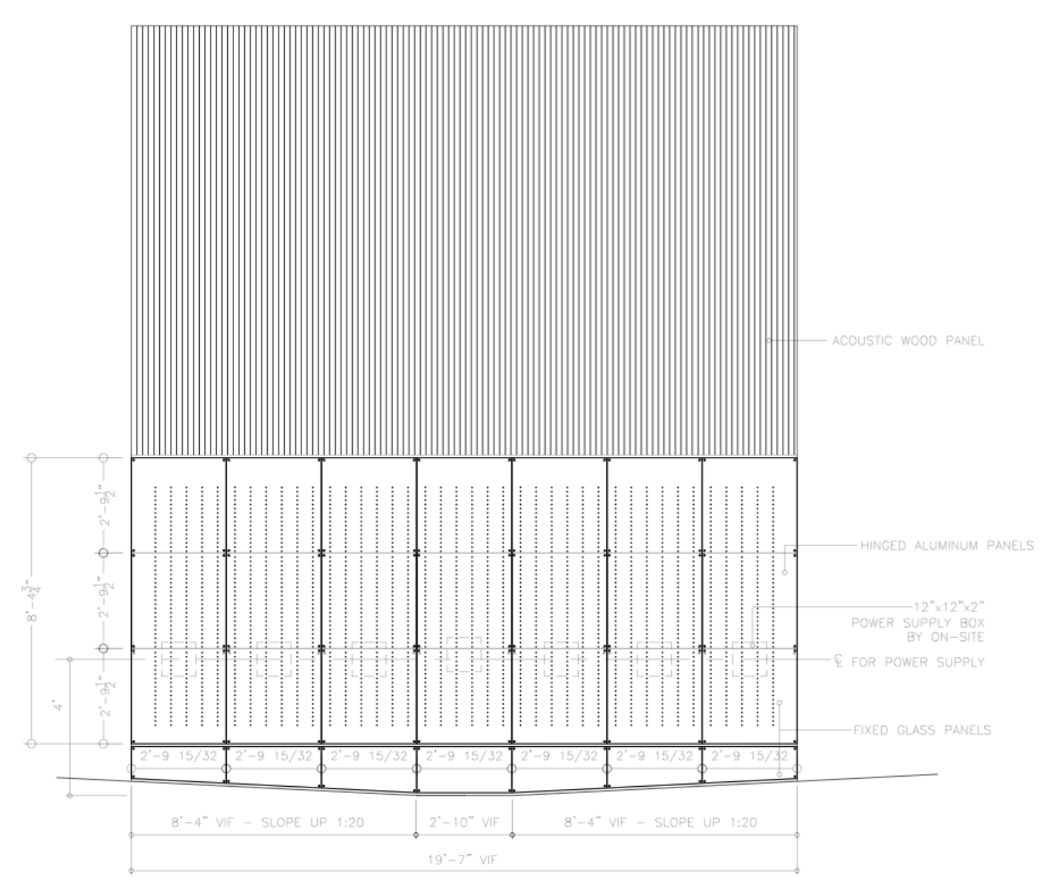
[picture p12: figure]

The Yahrzeit Wall Structure consists of seven large aluminum panels hinged at the top. Each aluminum panel supports three glass panels and has drilled openings through which the LEDs are visible. Circuit boards containing LEDs and supporting circuitry are mounted to the inside of the aluminum panels. Power supplies mounted inside the wall feed the LED circuitry.

The Yahrzeit Controller is an embedded microprocessor controller located behind the first large aluminum panel. It interfaces with the Yahrzeit LED Array and controls which memorial LEDs are lit.

The Yahrzeit Server resides in the synagogue office. It provides the browser-based user interface and runs the background processes that automate the Yahrzeit panels.

## Yahrzeit Wall Components

This section briefly defines the components that make up the integrated Yahrzeit Wall.

Yahrzeit Panels –The twenty-one etched glass panels provide space for up to 2,240 names to be remembered.

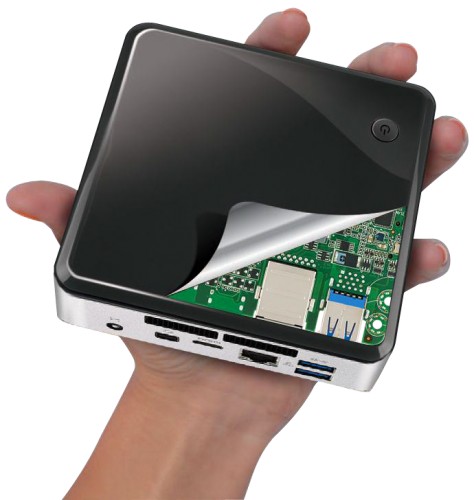
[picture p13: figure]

Yahrzeit Server – A Linux-based appliance that presents the browser user interface, runs the background processes that perform Yahrzeit and Yizkor automation, and signals the Yahrzeit Controller to change the LED display..

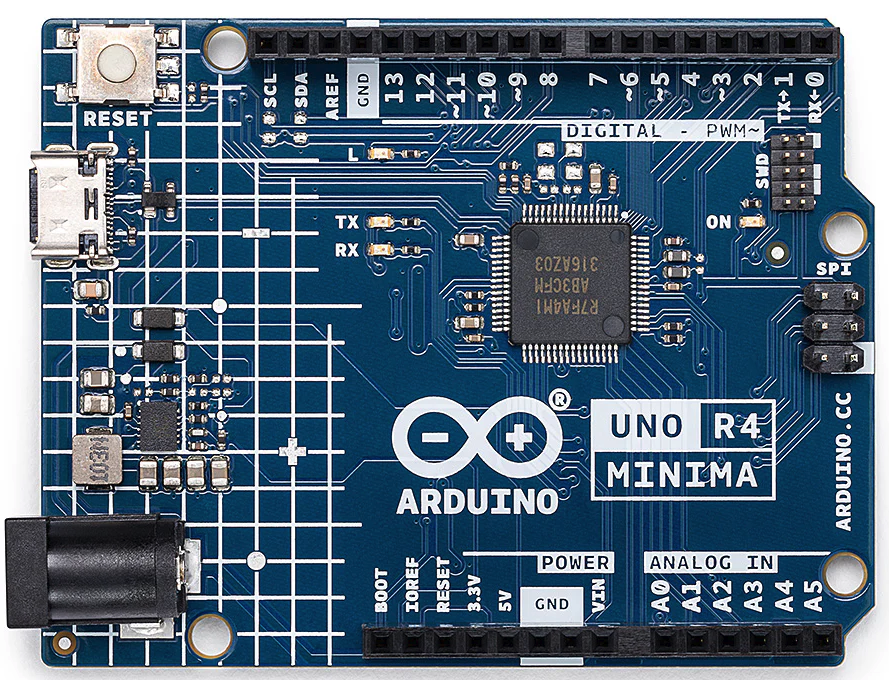
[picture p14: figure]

Yahrzeit Controller – The Arduino-based embedded controller installed behind the Yahrzeit Wall. It receives commands from the Yahrzeit Server and drives the Yahrzeit LED Array by refreshing the pixel boards with the current LED state.

Yahrzeit LED Array – The 56-row by 40-column LED array, for a total of 2,240 individual memorial LEDs.

Yahrzeit Pixel board (YPX) – The YPX board is a small number (6 or 8 or 10) of pixels or LEDs on a single printed circuit board. A string of 7 YPX boards comprise each column of 56 LEDs and 40 columns – a total of 280 YPX boards – are connected forming the entire LED array.

Interconnect cables – The Yahrzeit Pixel boards are interconnected in strings of seven YPX boards for each 56-LED column. Separate power interconnects distribute power to the pixel boards.

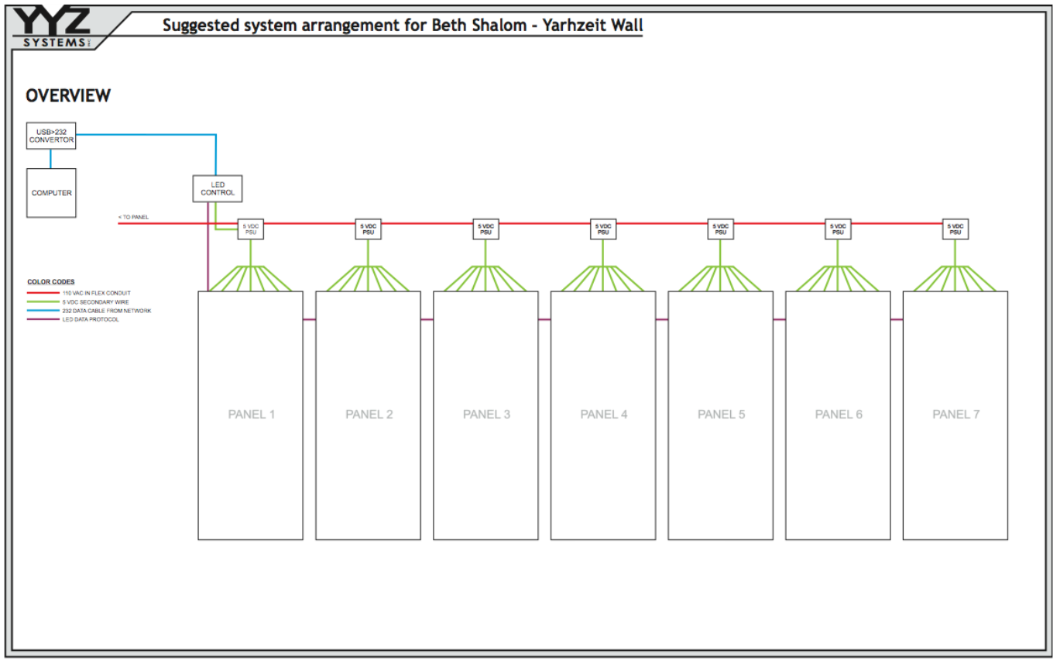
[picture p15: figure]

## Yahrzeit Controller

The current Yahrzeit Controller is an Arduino Uno R4 Minima stack with an Ethernet shield and a custom pixel-interface shield. It replaces the original v1 8051-based controller, the separate serial-to-Ethernet bridge used in the original installation, and the v2 Arduino Mega controller used in the 2015 refresh.

The Yahrzeit Server communicates with the controller over Ethernet using a simple text command protocol. The controller maintains the LED wall state, maps logical wall/panel positions to the physical pixel chain, and refreshes the LED array behind the glass panels.

During normal operation, synagogue staff do not need to interact with the controller directly. Controller diagnostics and firmware maintenance are engineering/service tasks.

## Yahrzeit Server / Appliance System

There are three layers of Yahrzeit software:

- The browser-based management software, used by synagogue staff to maintain memorial records, configure synagogue policy, view status, and run reports. This runs on the Yahrzeit Server / Appliance and is based on the standard Linux/Apache/PHP web application stack.
- The background automation software, which runs scheduled Yahrzeit and Yizkor operations and sends the required display commands to the controller. This software runs automatically during normal operation.
- The embedded controller firmware, which runs on the Arduino-based Yahrzeit Controller. This firmware maintains the LED wall state and drives the LED array at the hardware level.

The current Yahrzeit Server / Appliance is a dedicated Linux-based computer located in the synagogue office or other designated equipment location. See section 27-8 Yahrzeit Server, for the appliance address, login/service notes, backups, scheduled operation, and maintenance procedures.

### The Yahrzeit Server’s Browser User Interface

Normal operation of the Yahrzeit Server is through its browser-based user interface. Synagogue staff use these pages to view wall status, maintain memorial records, configure synagogue policy, and run reports or controlled wall operations.

The complete user interface is described in section 27-8 Yahrzeit Server. The installed browser address should be recorded there after the server/appliance is configured on the synagogue network.

The sample pages below show the wall status/controller page and the Minhag configuration page.

- Yahrzeit Controller: This page summarizes the current state of the Yahrzeit Wall and provides links to related status, configuration, and maintenance pages.

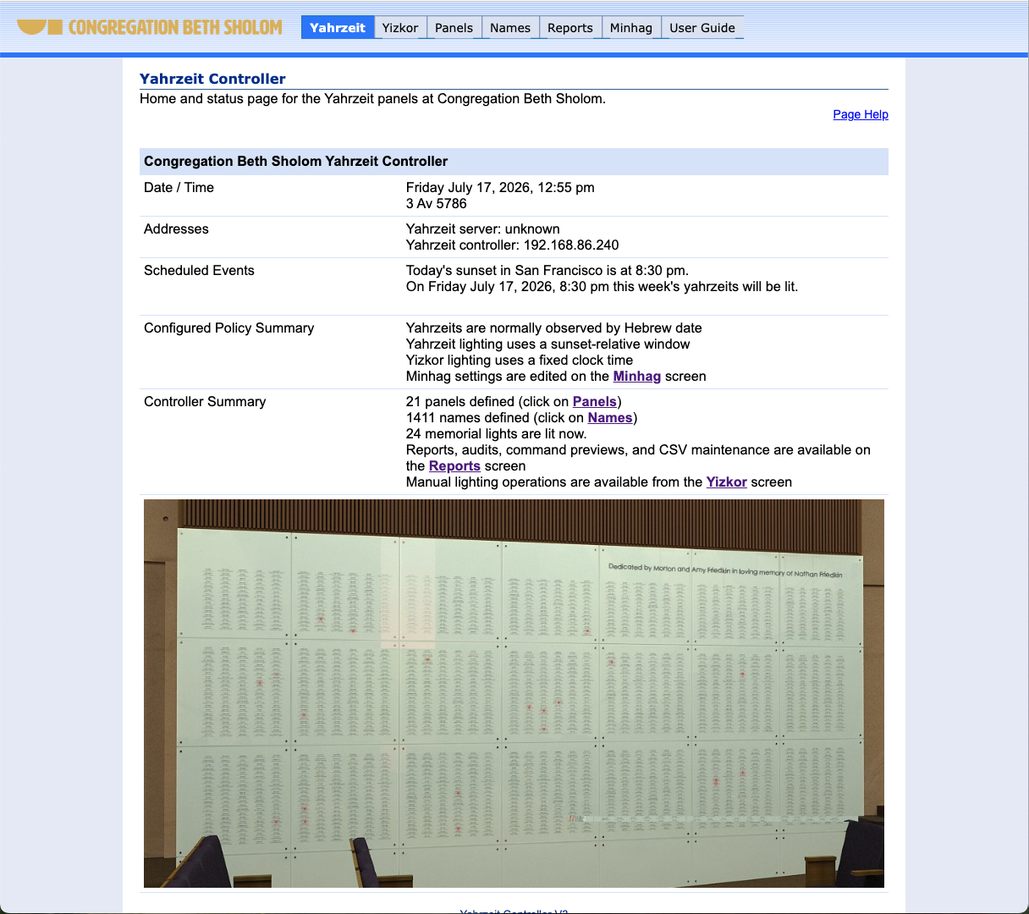
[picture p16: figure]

- Minhag: This page configures the synagogue-specific customs and observances used by the Yahrzeit and Yizkor lighting schedule.

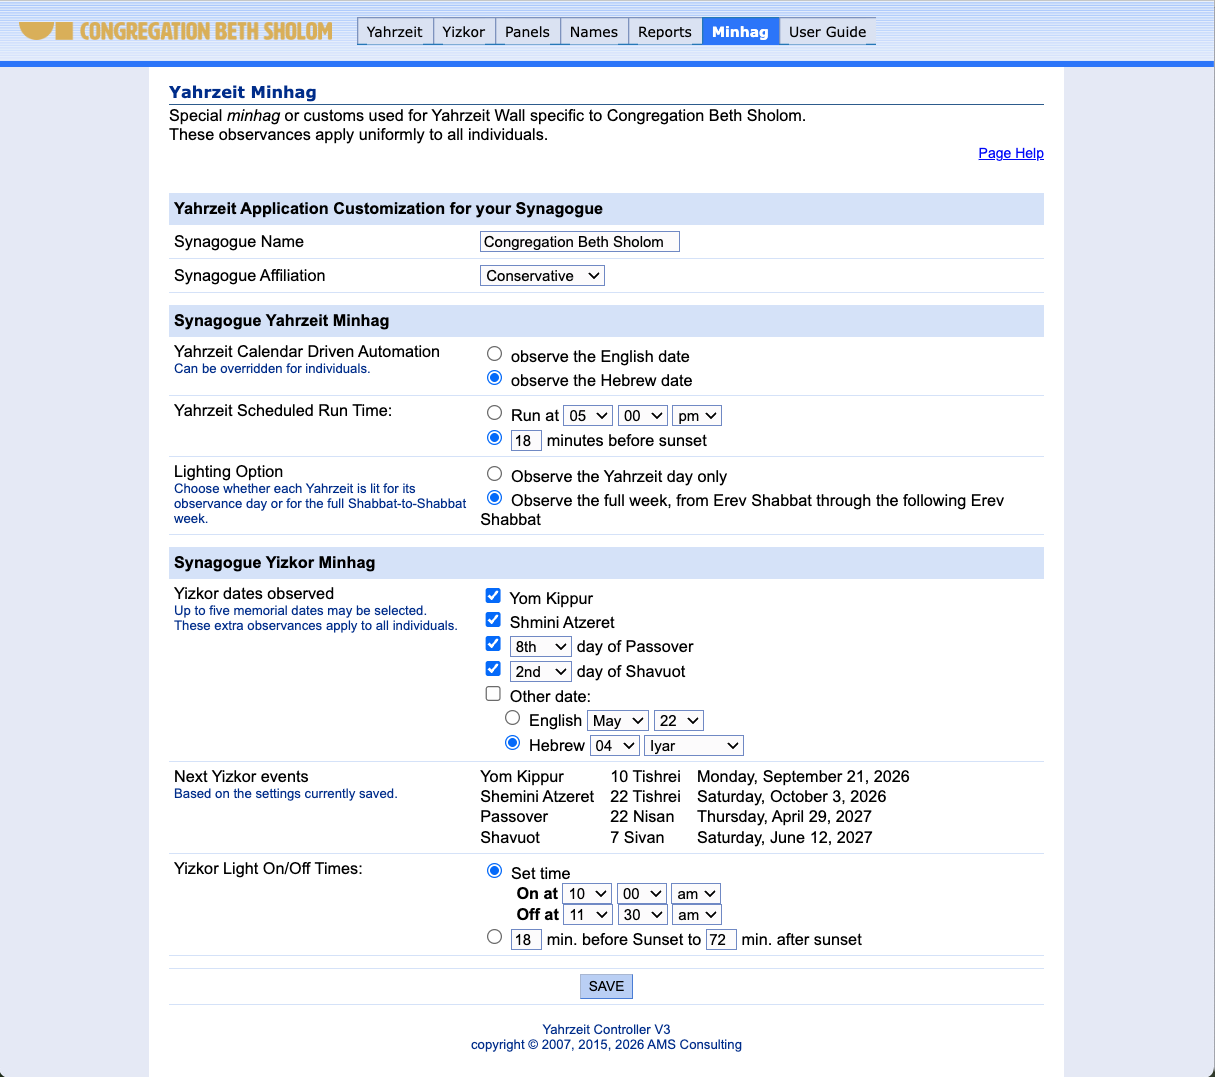
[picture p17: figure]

## Related Documentation

This overview describes the purpose and major components of the Yahrzeit Wall. More detailed information is maintained in the following House Manual sections:

- 27-7 Yahrzeit Panels – glass panels, panel layout, physical panel maintenance, and panel repair/reprint information.
- 27-8 Yahrzeit Server – server/appliance operation, browser access, scheduled operation, backups, network addresses, and maintenance procedures.
- 27-3 Low Voltage Room – building electronics location and infrastructure, where applicable.
- 27-4 Networking – building network information, where applicable.

Engineering source files, firmware, hardware drawings, and appliance software are maintained in the public Yahrzeit source repository on GitHub. The installed appliance normally contains a sparse checkout under /home/allan/src/yahrzeit, with the web appliance in /home/allan/src/yahrzeit/yahrzeit_site-v3. The full project tree is available from the public GitHub repository referenced by that checkout. These files are intended for service, repair, refresh, and future engineering work, not for normal synagogue staff operation.

27-6 Yahrzeit Wall Overview (2026) Page of

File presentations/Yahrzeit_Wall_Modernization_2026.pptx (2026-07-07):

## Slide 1

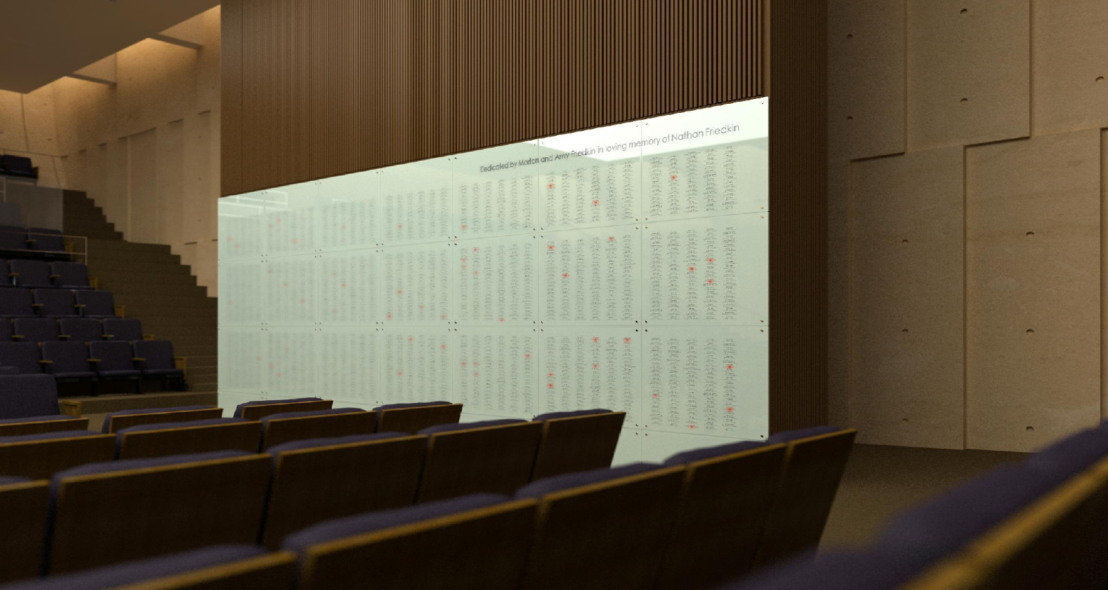
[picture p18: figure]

Yahrzeit Wall
Modernization & Maintenance Plan

Congregation Beth Sholom • 2026

Allan Schwartz

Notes: Open personally and briefly. This is a stewardship presentation, not a technical deep dive. Emphasize continuity: the wall has served the congregation, and the goal is to keep it reliable and maintainable.

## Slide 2

What the wall does

A ritual object supported by a technical system

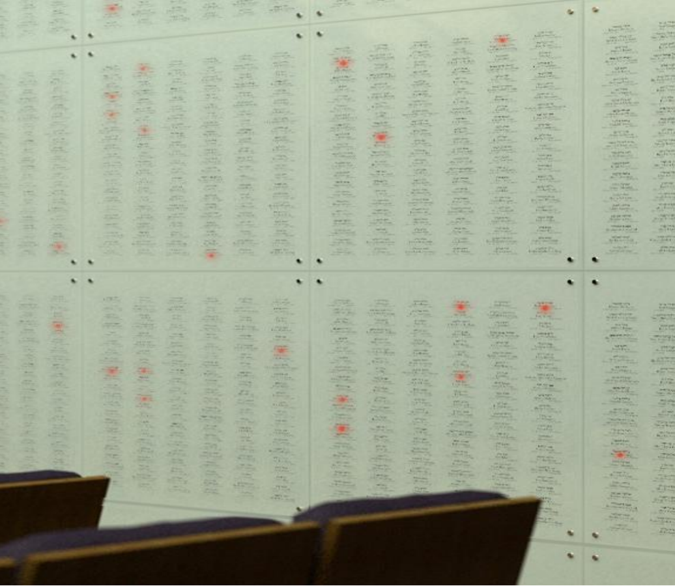
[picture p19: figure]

- Honors loved ones through etched names and lights
- Lights memorials during the appropriate Yahrzeit week
- Illuminates the wall for Yizkor observances
- Combines glass, lighting electronics, database, and automation

Congregation Beth Sholom • Yahrzeit Wall modernization

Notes: Keep this accessible. The wall is not just hardware; it is a ritual and memorial system. Avoid excess technical detail here.

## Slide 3

Why attention is needed now

The system served well; now it needs a maintainable future

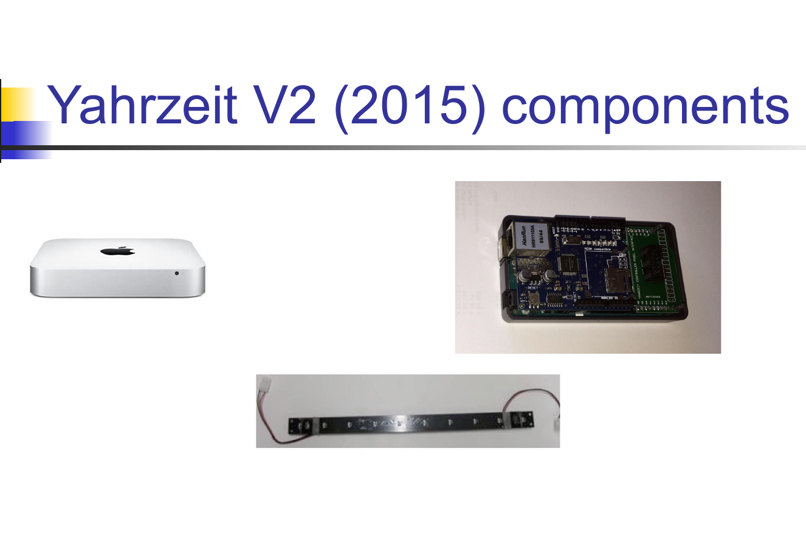
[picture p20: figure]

- Server/appliance environment and
Institutional knowledge is fragile
- Maintenance needs a small, repeatable path
- The goal is renewal, not redesign

2015: Mac Mini + Arduino-era controller + legacy PHP

Congregation Beth Sholom • Yahrzeit Wall modernization

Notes: Use careful tone: do not say the old system is bad. Say it has served the synagogue and deserves a supportable maintenance path.

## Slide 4

Design goals still hold

The 2015 goals remain the right north star

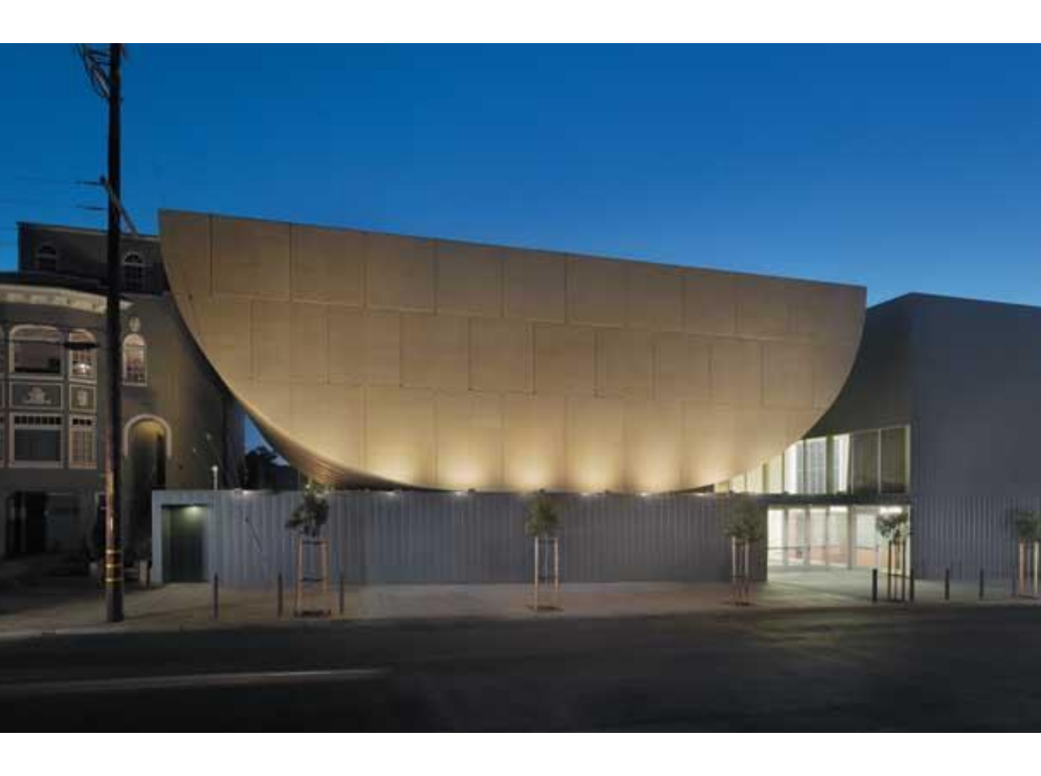
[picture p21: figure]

Simplicity, elegance, ease of use, database integration, automation — and a system that can be maintained.

- Preserve the architectural and ritual intent
- Make operation clearer for staff and facilities
- Keep technical complexity behind the scenes
- Document for future maintainers

Congregation Beth Sholom • Yahrzeit Wall modernization

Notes: Reference the 2015 deck briefly. The message: the original goals were sound; the 2026 project is to restore and protect those goals.

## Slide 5

What has already been done

Recent preparation has moved from idea to working prototype

- Reviewed and modernized server-side PHP screens
- Added shared lighting-policy logic used by UI and engine
- Improved dashboard and panel-level status visibility
- Built a Linux Ubuntu appliance install path
- Bench-tested replacement controller/interface pieces

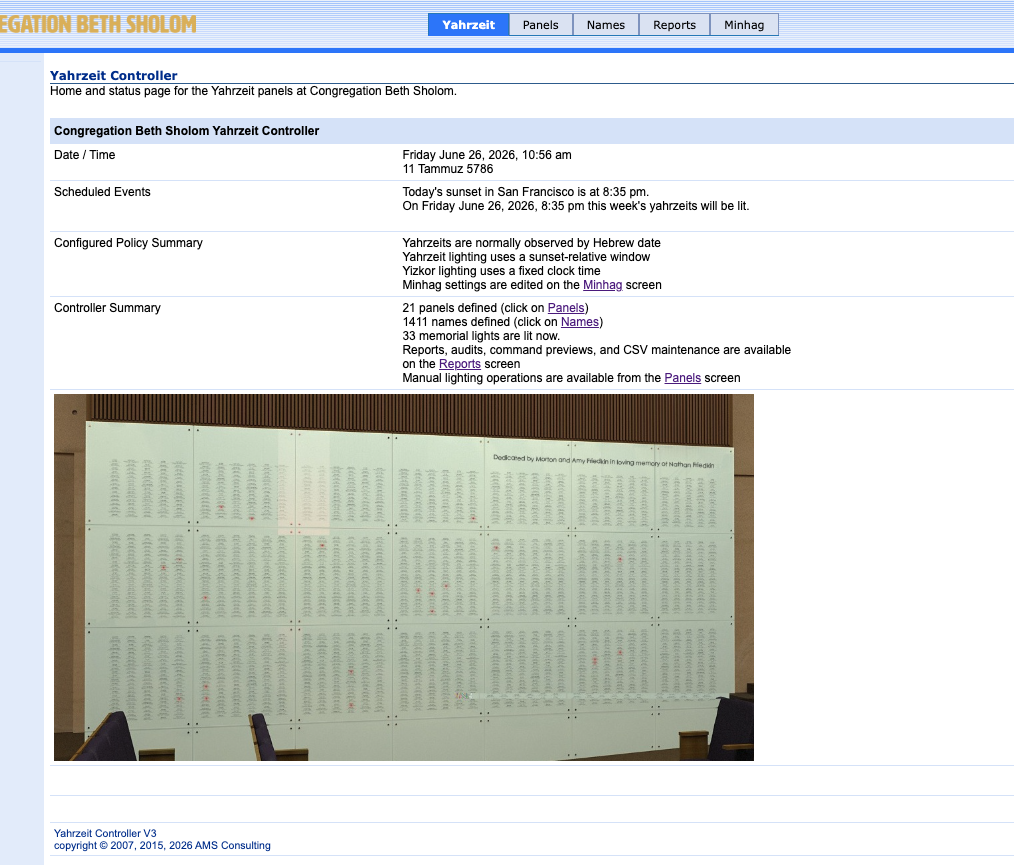
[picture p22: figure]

Congregation Beth Sholom • Yahrzeit Wall modernization

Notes: This slide is credibility. Do not dwell on code names unless asked. Mention that the work is already in a repository and tested locally.

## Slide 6

Visible improvement: wall-level view

The panel overview now gives operational context

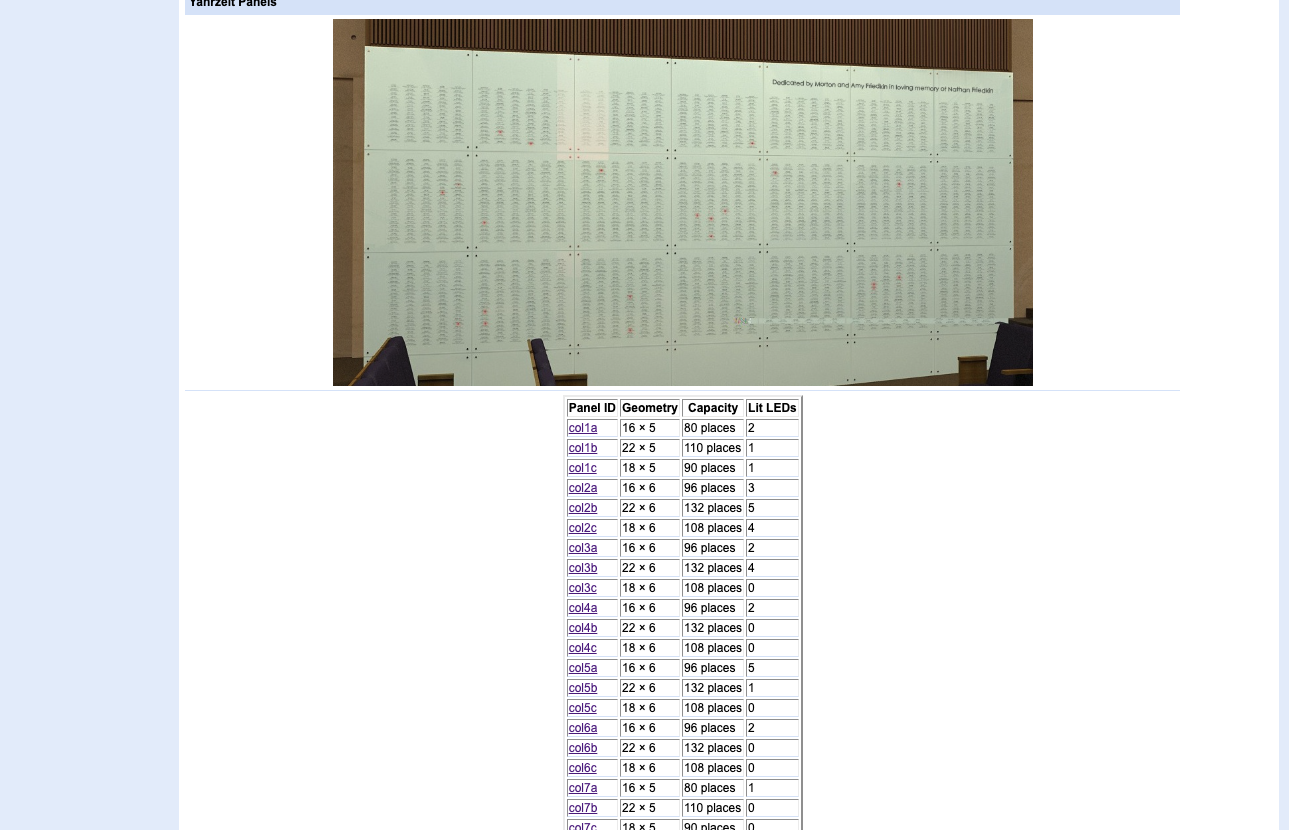
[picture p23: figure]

- Panel geometry and capacity are visible
- Lit-light counts appear by physical panel
- Manual operations are grouped and labeled
- A maintainer can orient themselves quickly

Congregation Beth Sholom • Yahrzeit Wall modernization

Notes: Preface the single-panel screen with this one. It shows the wall as a whole and introduces lit-light counts.
“This gives staff and maintainers a wall-level view, including panel-geometry and lit-light counts”

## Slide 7

Visible improvement: single-panel view

A maintainer can see which memorial lights should be lit now

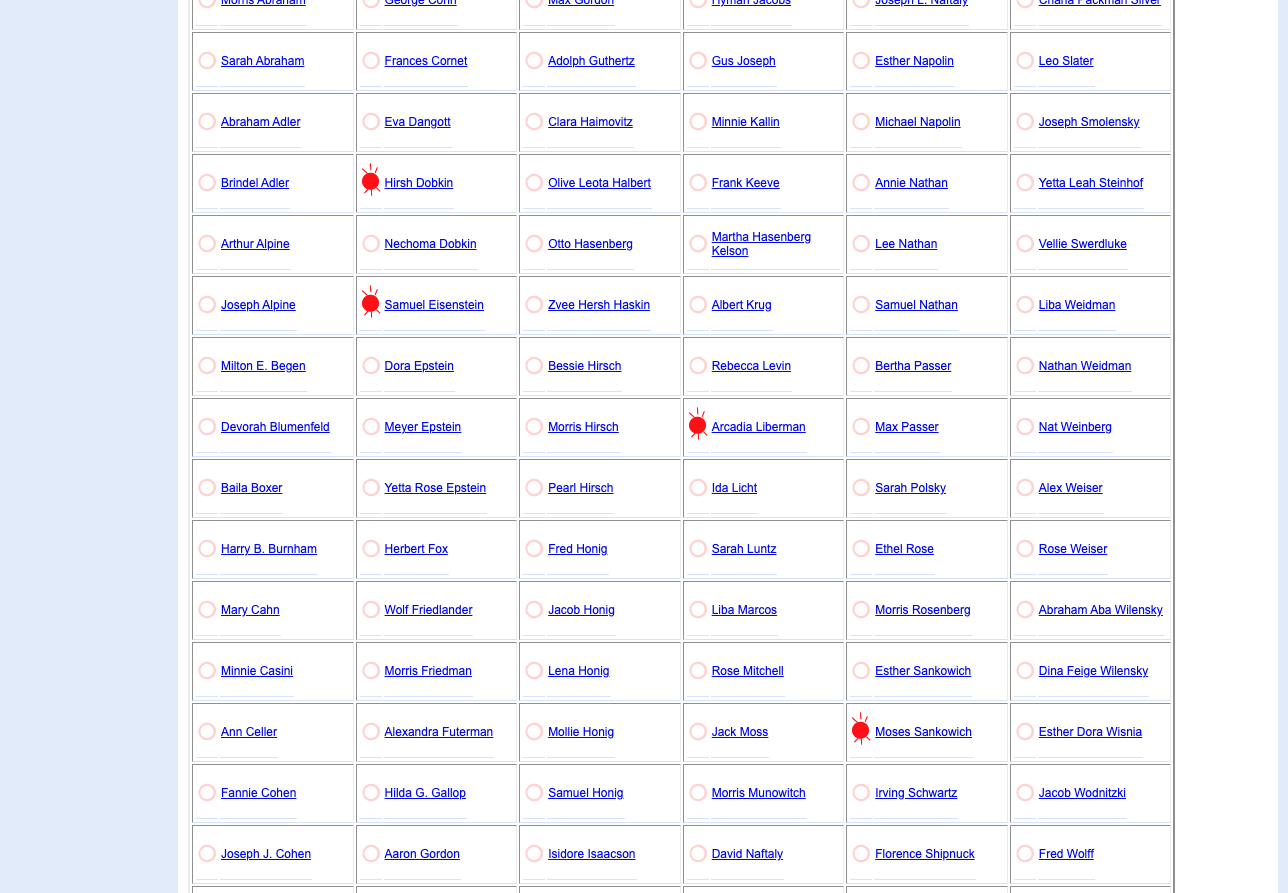
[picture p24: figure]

Congregation Beth Sholom • Yahrzeit Wall modernization

Example: col5a

- Names remain clickable
- LED icon marks a calculated lit memorial
- Summary line: “5 memorial lights should be lit now on this panel”

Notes: This is the strongest concrete example for nontechnical people. Say: This now shows exactly which memory lights should be lit today. it turns the wall from a black box into something staff and maintainers can inspect.

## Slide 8

Proposed modernization path

A staged, low-risk maintenance project

Prepare

Finalize appliance and docs

1

Assess onsite

Confirm current server, wiring, access

2

Bench test

Validate controller path safely

3

Cut over

Scheduled install with rollback

4

Handoff

Document operation and support

5

Principle: preserve the current wall; do not disturb it until the replacement path is tested.

Congregation Beth Sholom • Yahrzeit Wall modernization

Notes: This is the plan slide. Make it clear the project is staged and reversible. Facilities and leadership should hear: no surprises, no casual tinkering with the wall.

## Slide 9

Small working team

The project needs coordination, not a large committee

Engineering lead

Allan: historical knowledge, software, controller path

Engineering helper

Second technical person for review and onsite work

Facilities lead

Access, scheduling, physical installation coordination

CBS technical contact

Local knowledge of current server, IP network & passwords

Clergy / office stakeholder

Ritual policy and operational acceptance

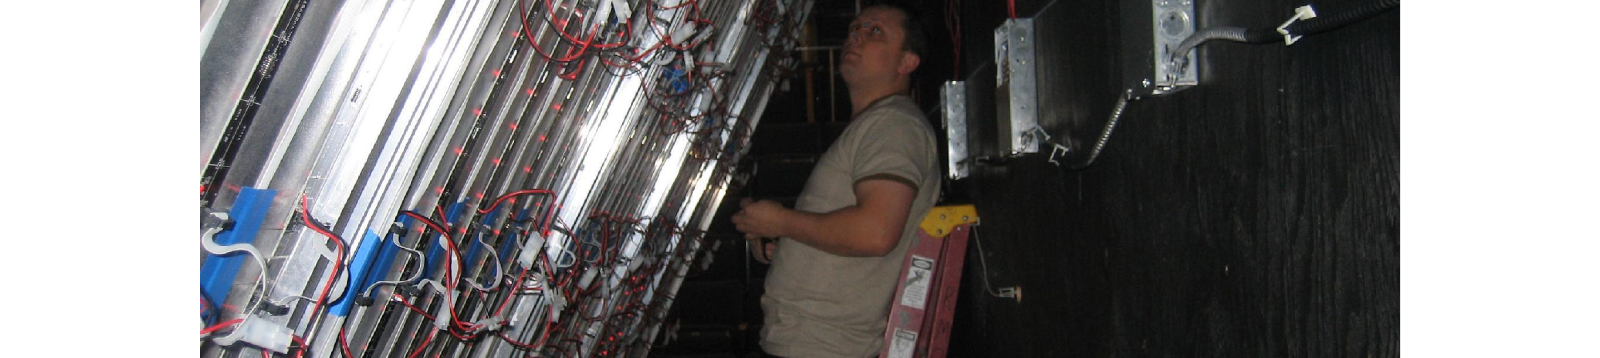
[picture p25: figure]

Congregation Beth Sholom • Yahrzeit Wall modernization

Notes: Say that the engineering work can be pro bono, but the site work needs CBS coordination.

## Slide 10

What I am asking CBS to do next

A focused first step

- Identify the current CBS point people: facilities, office, clergy, and technical contact
- Authorize this working group
- Provide access to inspect the current server, network path, and controller wiring
- Schedule a planning meeting, then a controlled onsite work window


Goal: preserve the Yahrzeit Wall as a reliable, maintainable memorial system for the congregation.

Congregation Beth Sholom • Yahrzeit Wall modernization

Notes: End the main deck with a clear ask. Avoid drifting into technical appendix unless the audience wants it.

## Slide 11


Technical Appendix

Architecture • controller • appliance • screens • deployment

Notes: Transition: the next slides are for the technical/facilities audience. They can be skipped or used as backup.

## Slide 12

System architecture

The wall is physical, electronic, and software

APPENDIX

Glass panels

Etched names + LEDs

Pixel chain

DATA • CLOCK • LATCH • OE

Controller

Arduino-class embedded logic

Appliance

Apache/PHP + database + scheduler

- The UI and reports show calculated policy state
- The controller sends only lighting commands to the wall
- The project preserves the wall and renews maintainability

Technical appendix

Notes: Use this to orient facilities and technical people. Important distinction: UI calculated status is not the same as querying the live controller.

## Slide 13

Embedded controller upgrade path

Modern controller, same hard-wired reliability principle

APPENDIX


2026 replacement path

- Ubuntu server LTS
- Arduino UNO R4 Minima -- modern, 32-bit ARM controller
- Roughly an order-of-magnitude more capable platform
- New Ethernet hardware and improved connection behavior
- New pixel interface shield and case
- Exact same “PIXEL” board interface

2015 controller path

Arduino Mega-era design
Legacy Ethernet stack
Field-proven but aging

Technical appendix

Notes: Say “roughly order of magnitude” rather than promising 12x unless someone asks. If technical audience asks, explain 16 MHz to 48 MHz plus architecture improvement as a rough estimate.

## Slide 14

Replacement appliance path

Fresh, documented, repeatable

- Fresh Ubuntu NUC appliance instead of an aging Mac Mini
- Apache + PHP runtime with documented installer
- Public source repository and project instructions
- No live controller transmission during install tests
- Cron phases documented rather than hidden

APPENDIX


Example: fresh NUC booted to Ubuntu with SSH enabled

Technical appendix

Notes: This is about deployment hygiene. Emphasize reproducibility and supportability, not just newer hardware.

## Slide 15

UI screen tour

Cleaner screens make the system easier to operate and maintain

APPENDIX


Dashboard


Names


Minhag policy

Dashboard: current policy and calculated lit count
Names: searchable, read-only memorial database view
Minhag: documented ritual policy settings

Technical appendix

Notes: Screen-by-screen tour should be short. The important point: the app now explains itself better.

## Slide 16

Reports and scheduling

Verify behavior before touching hardware

APPENDIX


- Reports show today, this week, next week, Yizkor, audits, and command previews
- Scheduler model remains simple: cron invokes short phases; no daemon or long sleeps
- Yizkor policy is explicit and testable inside the app

Technical appendix

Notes: This slide is about confidence. Reports and command previews let the team verify expected behavior before live wall operations.

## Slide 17

Safer memorial database maintenance

Single-record changes without rewriting the whole CSV

APPENDIX


- Edit path is intended for correction, especially date-of-death issues
- Only one physical CSV line is replaced
- Original line identity is checked before save
- Backup/audit path reduces maintenance risk

Technical appendix

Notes: This may be too technical for the main audience but important for engineering credibility. It addresses the risk of staff or maintainers corrupting the database.

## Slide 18

Testing and rollback plan

No live wall change until the replacement path is proven

APPENDIX


- Bench-test replacement controller and interface
- Run non-transmit server tests (--dry-run) and command previews
- Inspect current onsite server and wiring before cutover
- Preserve current working system until replacement is validated
- Maintain a cold-spare appliance/server

Technical appendix

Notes: Stress that testing precedes installation. The test fixture work is a confidence-builder, not a distraction.

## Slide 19

Known risks and mitigations

Acknowledge uncertainty; reduce it with process

APPENDIX

Single-record editing + backup/audit

Onsite assessment before changes

Risk

Mitigation

Unknown current onsite state

Fresh appliance plus documented install

Aging server or OS

Bench test + onsite non-destructive validation

Controller/network mismatch

Database maintenance error

Repository, docs, support handoff

Future loss of knowledge

Technical appendix

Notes: This is the trust slide for leadership. Be honest that onsite unknowns exist, and then show that every risk has a mitigation.

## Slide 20

A maintainable future
for a memorial wall

Next step: name the working group and schedule the onsite assessment.

Thank you

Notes: Close by returning to purpose. This is not about technology for its own sake. It is about preserving a memorial system for CBS.

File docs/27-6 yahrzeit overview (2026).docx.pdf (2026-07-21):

## 27-6 Yahrzeit Wall Overview

### The Yahrzeit Panels are etched glass panels with an automated lighting mechanism. These panels memorialize the names and dates of death of members of the congregation or their

families.

### In observance of individual Yahrzeit and Yizkor dates, memorial LEDs are lit and

extinguished according to programmed synagogue policy, typically at the start of the Shabbat preceding the Yahrzeit. Yahrzeit and Yizkor dates may be based on either the Jewish or the

### secular (Gregorian) calendar. The memorial LED lighting time may be scheduled

automatically, triggered manually, based on sunset, or set to a fixed time.

Manufacturer: | On-Site Systems Inc. | http://www.on-sitesystems.com (http://osshome.com/)
Yyz Systems Inc | http://www.yyzsystems.com
Allan Schwartz | (server and controller)
Model Number: | custom installation
Maintenance: | Clean the glass monthly, with Windex wipes or equivalent
Service: | Glass – On-Site Systems
Electronics – Yyz Systems
Software – Allan Schwartz
Repair/reprint panels of glass – On-Site Systems
Location: | Sanctuary west wall
Installers: | On-Site Systems Inc. | http://www.on-sitesystems.com (http://osshome.com/)
Gary Taylor | gary@on-sitesystems.com | 800-838-7778
Yyz Systems Inc | http://www.yyzsystems.com
Marko Hajdinovic | marko@yyzsystems.com | 905-795-8500
Allan Schwartz | allanschwartz@sbcglobal.net | 669-350-7296
27-6 Yahrzeit Wall Overview (2026) | Page 1 of 11

## Physical Wall Overview


The Yahrzeit Wall comprises the Glass Panels (see section 27-7 Yahrzeit Panels), the embedded electronics in the wall, and the Yahrzeit Server software running on the Yahrzeit appliance or server (see section 27-8 Yahrzeit Server).

This document doesn’t discuss how the software operates, or is layered, or how the end-user interfaces with this software. See section 27-8 Yahrzeit Server.

This document doesn’t discuss the glass, or how to create or modify the panels. See section 27-7 Yahrzeit Panels.

## Purpose of the System

The Yahrzeit System provides a browser-based interface for maintaining memorial records, configuring synagogue lighting policy, checking wall status, and operating the calendar-based Yahrzeit and Yizkor lighting schedule. The user interface is a set of browser pages, such as:



## The Yahrzeit Wall Structure


The Yahrzeit Wall Structure consists of seven large aluminum panels hinged at the top. Each aluminum panel supports three glass panels and has drilled openings through which the LEDs are visible. Circuit boards containing LEDs and supporting circuitry are mounted to the inside of the aluminum panels. Power supplies mounted inside the wall feed the LED circuitry.

The Yahrzeit Controller is an embedded microprocessor controller located behind the first large aluminum panel. It interfaces with the Yahrzeit LED Array and controls which memorial LEDs are lit.

The Yahrzeit Server resides in the synagogue office. It provides the browser-based user interface and runs the background processes that automate the Yahrzeit panels.

## Yahrzeit Wall Components

This section briefly defines the components that make up the integrated Yahrzeit Wall.

Yahrzeit Panels –The twenty-one etched glass panels provide space for up to 2,240 names to be remembered.


### Yahrzeit Server – A Linux-based appliance that presents the browser user interface, runs the background processes that perform Yahrzeit and Yizkor automation, and signals the Yahrzeit Controller to change the LED

display..


### Yahrzeit Controller – The Arduino-based embedded controller installed behind the Yahrzeit Wall. It receives commands from the Yahrzeit Server and drives the Yahrzeit LED Array by refreshing the pixel boards

with the current LED state.

### Yahrzeit LED Array – The 56-row by 40-column LED array, for a total of 2,240 individual


memorial LEDs.

### Yahrzeit Pixel board (YPX) – The YPX board is a small number (6 or 8 or 10) of pixels or LEDs on a single printed circuit board. A string of 7 YPX boards comprise each column of 56 LEDs and 40 columns – a total of 280 YPX boards – are connected forming the entire

LED array.

Interconnect cables – The Yahrzeit Pixel boards are interconnected in strings of seven YPX

### boards for each 56-LED column. Separate power interconnects distribute power to the pixel

boards.

## Yahrzeit Controller

The current Yahrzeit Controller is an Arduino Uno R4 Minima stack with an Ethernet shield and a custom pixel-interface shield. It replaces the original v1 8051-based controller, the separate serial-to-Ethernet bridge used in the original installation, and the v2 Arduino Mega controller used in the 2015 refresh.

The Yahrzeit Server communicates with the controller over Ethernet using a simple text command protocol. The controller maintains the LED wall state, maps logical wall/panel positions to the physical pixel chain, and refreshes the LED array behind the glass panels.

During normal operation, synagogue staff do not need to interact with the controller directly. Controller diagnostics and firmware maintenance are engineering/service tasks.

## Yahrzeit Server / Appliance System

### There are three layers of Yahrzeit software:

### - The browser-based management software, used by synagogue staff to maintain memorial records, configure synagogue policy, view status, and run reports. This runs on the Yahrzeit Server / Appliance and is based on the standard Linux/Apache/PHP

web application stack.

### - The background automation software, which runs scheduled Yahrzeit and Yizkor operations and sends the required display commands to the controller. This software

runs automatically during normal operation.

### - The embedded controller firmware, which runs on the Arduino-based Yahrzeit Controller. This firmware maintains the LED wall state and drives the LED array at

the hardware level.

The current Yahrzeit Server / Appliance is a dedicated Linux-based computer located in the synagogue office or other designated equipment location. See section 27-8 Yahrzeit Server,

### for the appliance address, login/service notes, backups, scheduled operation, and

maintenance procedures.

## The Yahrzeit Server’s Browser User Interface

Normal operation of the Yahrzeit Server is through its browser-based user interface. Synagogue staff use these pages to view wall status, maintain memorial records, configure synagogue policy, and run reports or controlled wall operations.

The complete user interface is described in section 27-8 Yahrzeit Server. The installed browser address should be recorded there after the server/appliance is configured on the synagogue network.

The sample pages below show the wall status/controller page and the Minhag configuration page.

- Yahrzeit Controller: This page summarizes the current state of the Yahrzeit Wall and provides links to related status, configuration, and maintenance pages.


- Minhag: This page configures the synagogue-specific customs and observances used by the Yahrzeit and Yizkor lighting schedule.


## Related Documentation

This overview describes the purpose and major components of the Yahrzeit Wall. More detailed information is maintained in the following House Manual sections:

- 27-7 Yahrzeit Panels – glass panels, panel layout, physical panel maintenance, and panel repair/reprint information.
- 27-8 Yahrzeit Server – server/appliance operation, browser access, scheduled operation, backups, network addresses, and maintenance procedures.
- 27-3 Low Voltage Room – building electronics location and infrastructure, where applicable.
- 27-4 Networking – building network information, where applicable.

Engineering source files, firmware, hardware drawings, and appliance software are maintained in the public Yahrzeit source repository on GitHub. The installed appliance normally contains a sparse checkout under /home/allan/src/yahrzeit, with the web

## appliance in /home/allan/src/yahrzeit/yahrzeit_site-v3. The full project tree is

available from the public GitHub repository referenced by that checkout. These files are intended for service, repair, refresh, and future engineering work, not for normal synagogue staff operation.

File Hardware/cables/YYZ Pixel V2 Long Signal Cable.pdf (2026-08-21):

# YYZ Pixel V2 Long Signal Cable

## Diagram

Provisional 2800 mm straight-through 10-conductor IDC ribbon cable for the Yahrzeit Wall signal interconnect. Keyed 2x5 IDC connectors on both ends. Final length must be confirmed by field measurement.

J1
IDC keyed 2x5 female 10-pin
DI | 1
DI | 2
OE | 3
OE | 4
CP | 5
CP | 6
ST | 7
ST | 8
GND | 9
GND | 10
SIGNAL END A

W1
10x | 28 AWG | 2800.0 mm
J1:1:DI | 1:RD | J2:1:DI
J1:2:DI | 2:WH | J2:2:DI
J1:3:OE | 3:WH | J2:3:OE
J1:4:OE | 4:WH | J2:4:OE
J1:5:CP | 5:WH | J2:5:CP
J1:6:CP | 6:WH | J2:6:CP
J1:7:ST | 7:WH | J2:7:ST
J1:8:ST | 8:WH | J2:8:ST
J1:9:GND | 9:WH | J2:9:GND
J1:10:GND | 10:WH | J2:10:GND

PROVISIONAL FINISHED LENGTH: 2800 mm.

- Final cable length must be confirmed by field measurement before production release.
- Red stripe = conductor 1 = pin 1.
- Straight-through assembly.
- Connector polarization key orientation shall follow the selected connector manufacturer's pin-1 definition.
- Test for continuity and correct pin-to-pin wiring.

J2
IDC keyed 2x5 female 10-pin
1 | DI
2 | DI
3 | OE
4 | OE
5 | CP
6 | CP
7 | ST
8 | ST
9 | GND
10 | GND
SIGNAL END B

## Bill of Materials

Id | Description | Qty | Unit | Designators
1 | Cable, 10 x 28 AWG | 2800 | mm | W1
2 | Connector, IDC, keyed 2x5 female, 10 pins | 2 | | J1, J2
8/20/26, 5:53 PM | YYZ Pixel V2 Long Signal Cable
file:///Users/allan/Desktop/GitHub/yahrzeit/Hardware/cables/CBL-06-idc-2800mm.html | 1/1

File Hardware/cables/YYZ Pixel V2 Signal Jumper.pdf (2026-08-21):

## YYZ Pixel V2 Signal Jumper

### Diagram

100 mm straight-through 10-conductor IDC ribbon cable for adjacent YYZ_PIXEL_V2 boards. Unkeyed 2x5 IDC connectors on both ends. Red stripe identifies conductor 1 and connector pin 1.

J1
IDC unkeyed 2x5 female 10-pin
DI | 1
DI | 2
OE | 3
OE | 4
CP | 5
CP | 6
ST | 7
ST | 8
GND | 9
GND | 10
YYZ_PIXEL_V2 END

W1
10x | 28 AWG | 100.0 mm
J1:1:DI | 1:RD | J2:1:DI
J1:2:DI | 2:WH | J2:2:DI
J1:3:OE | 3:WH | J2:3:OE
J1:4:OE | 4:WH | J2:4:OE
J1:5:CP | 5:WH | J2:5:CP
J1:6:CP | 6:WH | J2:6:CP
J1:7:ST | 7:WH | J2:7:ST
J1:8:ST | 8:WH | J2:8:ST
J1:9:GND | 9:WH | J2:9:GND
J1:10:GND | 10:WH | J2:10:GND

FINISHED LENGTH: 100 mm +/- 5 mm.
- Red stripe = conductor 1 = pin 1.
- Straight-through assembly.
- Test for continuity and correct pin-to-pin wiring.

J2
IDC unkeyed 2x5 female 10-pin
1 | DI
2 | DI
3 | OE
4 | OE
5 | CP
6 | CP
7 | ST
8 | ST
9 | GND
10 | GND
YYZ_PIXEL_V2 END

### Bill of Materials

Id | Description | Qty | Unit | Designators
1 | Cable, 10 x 28 AWG | 100 | mm | W1
2 | Connector, IDC, unkeyed 2x5 female, 10 pins | 2 | | J1, J2
8/20/26, 5:53 PM | YYZ Pixel V2 Signal Jumper
file:///Users/allan/Desktop/GitHub/yahrzeit/Hardware/cables/CBL-05-idc-100mm.html | 1/1

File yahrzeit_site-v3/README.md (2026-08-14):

# Yahrzeit Server Appliance — Operation and Maintenance
This directory contains the PHP web application, scheduler, command-line
engine, and installer for the Congregation Beth Sholom Yahrzeit Wall
appliance.

This README is intended for future maintainers of the appliance, including
people who did not build the original system.

<p align="center">
  <a href="images/yahrzeit-server-appliance.jpg">
    Yahrzeit Server Appliance Intel NUC
  </a>
</p>

*The Intel NUC Yahrzeit Server Appliance. Its external label records the
hostname, operating system, hardware capacity, and network information needed
for installation and recovery.*

The top-level repository README explains the whole Yahrzeit project: embedded
firmware, hardware, panel assets, and historical versions. This README is only
about the `yahrzeit_site-v3` appliance software.

## What This Appliance Does

The appliance is responsible for:

- displaying the current Yahrzeit wall status,
- rendering memorial/name views and reports,
- maintaining the memorial CSV database,
- applying synagogue lighting policy from `data/minhag.ini`,
- running scheduled Yahrzeit and Yizkor phases,
- generating controller command streams,
- and transmitting those commands to the Arduino-based wall controller.

## System Shape

The usual control path is:

```text
cron
  -> bin/yahrzeit_scheduler
    -> bin/yahrzeit
      -> bin/yahrzeit_engine.php
        -> include/yahrzeit_policy.inc.php
          -> controller command stream
          -> nc TCP connection
            -> Arduino controller
```

The web screens use the same underlying code where possible. Reports, audits,
and command previews are intended to be safe; live wall operations call
`bin/yahrzeit` and may transmit to the controller.

## Directory Layout

- `bin/` - command-line tools, scheduler, engine, and installer.
- `include/` - shared PHP helpers for dates, names, panels, LED mapping,
  lighting policy, and page layout.
- `data/` - live CSV data, `minhag.ini`, backups, and the automation log.
- `help/` - help pages shown by the web UI.
- `docs/` - project notes and generated/internal documentation.
- `css/`, `images/`, `js/` - legacy browser-side assets used by the screen
  templates.

## Important Files

- `data/yahrzeits-rev4.csv` - memorial database.
- `data/minhag.ini` - synagogue lighting policy and display settings.
- `bin/yahrzeit-controller.conf` - controller hostname/address and TCP port.
- `bin/yahrzeit` - shared scheduler/web execution stage and controller transport.
- `bin/yahrzeit_engine.php` - decides what should be lit or reported.
- `bin/yahrzeit_scheduler` - cron-facing scheduled phase runner.
- `bin/fix-up-crontab` - installs the policy-derived managed cron block.
- `include/yahrzeit_policy.inc.php` - shared day/week lighting decisions.
- `include/panels.inc.php` - static wall/panel geometry.
- `include/leds.inc.php` - maps panel/person locations to controller commands.

## Installation and Updates

The complete fresh-installation and replacement procedure is in
[`INSTALL.md`](INSTALL.md). The installer can also be rerun to update an
existing appliance:

```sh
curl -fsSL https://raw.githubusercontent.com/allanschwartz/yahrzeit/master/yahrzeit_site-v3/bin/install-yahrzeit.sh -o /tmp/install-yahrzeit.sh
bash /tmp/install-yahrzeit.sh
```

The appliance checkout is deployed code, not a development worktree. During
an update, the installer preserves `data/minhag.ini` and
`data/yahrzeits-rev4.csv`, replaces the remaining site files with the selected
remote version, and restores the live data. Source-code edits made directly on
the appliance are intentionally discarded.

## Network Configuration

There are two fixed-address concerns:

- the appliance/server address, used by operators browsing to the web UI,
- the Arduino controller address, used by `bin/yahrzeit` when transmitting
  commands.

The installer does not configure a static appliance/server IP address. On a
fresh Ubuntu appliance, configure that on-site using the local network policy,
usually in `/etc/netplan/*.yaml`.

Do not commit site-specific `/etc/netplan/*.yaml` files to this repository.

## Controller Address

The controller connection is stored as shell assignments in:

```text
bin/yahrzeit-controller.conf
```

`bin/yahrzeit` sources this file before parsing its command-line options. It
contains the controller host and port, the brightness used for normal Yahrzeit
lighting, and the brightness used for full-wall operations. Brightness values
run from 1 (brightest) through 254 (dimmest).

The installer remembers the previously recorded host and brightness values
before updating the checkout, installs the current tracked configuration, and
asks whether to keep the host or enter a replacement. The configuration file
itself is not preserved. The fixed port and transport defaults update with the
software. The Arduino controller firmware must use the matching address and
port.

For a one-command diagnostic override, use environment variables:

```sh
CONTROLLER_BRIGHTNESS=160 bin/yahrzeit --yizkor
```

## Safe Validation

From this directory, syntax-check the PHP and shell files with:

```sh
for f in $(find . -name '*.php') bin/yahrzeit_scheduler bin/fix-up-crontab; do
    php -l "$f"
done

for f in bin/yahrzeit bin/install-yahrzeit.sh; do
    bash -n "$f"
done
```

Run data/audit checks that do not transmit:

```sh
bin/yahrzeit --audit
bin/yahrzeit --dry-run
php tests/yahrzeit_engine_policy_test.php
```

## Live Controller Operations

Only run these when the controller IP is correct and it is safe to talk to the
wall:

```sh
bin/yahrzeit
bin/yahrzeit --all-off
bin/yahrzeit --all-on
bin/yahrzeit --yizkor
```

The default command applies normal Yahrzeit lighting. Use all four commands
carefully: without `--dry-run`, each transmits to the controller and changes
the wall.

## Scheduled Operation

`bin/fix-up-crontab` reads `data/minhag.ini` and manages only the marked
Yahrzeit block in the installation account's crontab. It preserves unrelated
cron jobs. Normal Yahrzeit lighting is reapplied every evening; the saved
day-only or weekly observance determines which memorial lights are selected.
Fixed times remain stable, while sunset-based times are recalculated for that
evening automatically. Yizkor on/off phases are installed only for the next
civil date of each enabled observance; the managed block is regenerated every
morning at 12:05 AM.

Every managed cron invocation appends to `data/automation.log`. Each run records
its phase, decision or action, controller transport summary, cron-repair
result, final status, and duration. Normal scheduled runs do not record the
complete controller command stream. The installer configures `logrotate` to
retain 13 compressed weekly logs without sending routine cron email.

```sh
tail -100 data/automation.log
ls -lh data/automation.log*
```

```sh
bin/fix-up-crontab --dry-run
sudo bin/fix-up-crontab
```

The installer records the intended cron account in
`/etc/yahrzeit-cron-user` and authorizes the Minhag page to invoke only this
repair helper. Rerun the installer, or the helper directly, after an operating
system upgrade or appliance migration if scheduled operation needs repair.

On hardened Ubuntu releases, Apache runs with the home directory mounted
read-only in its private service namespace and with sudoers configuration
hidden. The installer adds a systemd drop-in that makes only this site's
`data/` directory writable and permits sudo to read the single-command
authorization used by the cron-repair wrapper. The remaining Apache
filesystem protections stay enabled.

## Data Backup And Restore

The two appliance-specific live data files are:

```text
data/yahrzeits-rev4.csv
data/minhag.ini
```

The web Reports page can export and import this CSV. The upload path creates a
backup under `data/backups/` and runs an audit afterward.

Before replacing the appliance or doing major maintenance, copy:

```text
data/yahrzeits-rev4.csv
data/minhag.ini
data/backups/
bin/yahrzeit-controller.conf
```

The controller configuration is replaceable software configuration rather
than memorial data, but retaining it records the controller address selected
for that appliance.

## What Not To Change Casually

- Do not change the CSV schema without a migration plan.
- Do not change controller protocol commands unless the embedded firmware is
  updated at the same time.
- Do not edit panel geometry without running audits and checking reports.
- Do not depend on lab IP addresses in production.

## See Also

- **Project**
  - [`./README.md`](../README.md)
- **Server**
  - [`./yahrzeit_site-v3/README.md`](README.md)
  - [`./yahrzeit_site-v3/INSTALL.md`](INSTALL.md)
- **Controller**
  - [`./embedded/yahrzeit_v3/README.md`](../embedded/yahrzeit_v3/README.md)
  - [`./embedded/yahrzeit_v3/INSTALL.md`](../embedded/yahrzeit_v3/INSTALL.md)
- **Hardware**
  - [`./Hardware/README.md`](../Hardware/README.md)

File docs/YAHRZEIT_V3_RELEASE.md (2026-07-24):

# Yahrzeit Wall V3 Release Notes

**Release:** V3  
**Date:** July 2026  
**Status:** Released

<p align="center">
  <a href="images/yahrzeit-wall-in-use.jpg">
    Congregation Beth Sholom Yahrzeit Wall in the sanctuary
  </a>
</p>

*The Congregation Beth Sholom Yahrzeit Wall in the sanctuary. V3 retains the
physical memorial wall while replacing and modernizing the server appliance,
operator interface, automation, and embedded controller.*

## Overview

Yahrzeit Wall V3 modernizes the system that has served Congregation Beth
Sholom for many years. It retains the existing memorial database, panel
layout, and physical wall while replacing and improving the server appliance,
operator interface, automation, and embedded controller software.

The principal goal of V3 is dependable, unattended operation. Routine
Yahrzeit and Yizkor lighting is calculated from the memorial records and the
synagogue's saved practices, scheduled automatically, sent to the wall, and
recorded in an operational log.

## Major Improvements

### Operator Interface

- A clearer home page summarizes the appliance, controller, current lighting,
  configured practices, upcoming automation, and the next Yizkor dates.
- A dedicated Yizkor page presents the upcoming Yizkor services and provides
  the wall-wide lighting controls in a form that is also practical on a
  mobile phone.
- The Panels pages show the physical wall, panel locations, and the memorial
  lights expected to be lit.
- The Names page provides flexible searching by name, date, memorial option,
  and panel location. Existing memorial records may be reviewed and corrected
  individually.
- The Reports page produces day, week, and month reports. It also provides
  database auditing, a preview of controller commands, and CSV export and
  import for backup and batch maintenance.
- The Minhag page provides one place to configure Yahrzeit observance,
  lighting time, and Yizkor dates.

### Scheduling and Automation

- Yahrzeit lighting may be observed on the Yahrzeit date alone or for the
  full Erev Shabbat-to-Erev Shabbat week.
- Lighting may be scheduled at a fixed clock time or relative to sunset.
- The four annual Yizkor services are scheduled from their Hebrew dates. An
  optional additional full-wall memorial date may also be configured.
- The appliance creates and maintains its own managed cron schedule from the
  saved Minhag settings. Sunset-based times are refreshed automatically as
  sunset changes through the year.
- Week reports and automated weekly lighting use the same date-selection
  policy.

### Operational Reliability

- Each scheduled operation records its start, decision, action, controller
  result, completion status, and duration in `data/automation.log`.
- Controller connection failures and rejected commands are reported clearly;
  successful individual commands do not overwhelm the log.
- Standard log rotation retains a useful operating history without allowing
  the automation log to grow indefinitely.
- Dry-run, command-preview, and database-audit facilities allow important
  behavior to be checked without changing the wall.
- Updates preserve the live memorial database and congregation settings.

### Controller

- The updated controller software runs on the current Arduino-based controller
  and accepts its command language through either Ethernet or USB serial.
- It maintains the wall image in memory, refreshes the physical display,
  preserves saved state, and returns a result for each command.
- Built-in status, network, timing, and self-test facilities support bench
  testing and troubleshooting.
- Production panel geometry and network settings are selected when the
  controller is prepared for installation.

### Installation and Recovery

- A repeatable installer builds or updates the Ubuntu-based Yahrzeit
  appliance, installs the required services, configures the web server and
  automation, and asks for the controller address.
- The controller address is kept in a simple site configuration file and may
  be an IP address or a locally resolvable host name.
- The installer can be run again when repairing or replacing the appliance.
  Existing memorial and Minhag data is retained during a normal update.
- The server application has been modernized for PHP 8.

### Documentation

- Every operator page has page-specific online help.
- A complete online User Guide covers routine operation, reports, memorial
  database maintenance, backup, restoration, maintenance, and
  troubleshooting.
- The User Guide is also supplied as a PDF for inclusion in the Congregation
  Beth Sholom House Manual.
- Installer notes support future technical maintenance and recovery.

## Compatibility and Upgrade Notes

- V3 continues to use the existing `yahrzeits-rev4.csv` memorial database and
  the established panel identifiers and locations.
- A database audit should be run after importing or substantially editing the
  memorial database and before relying on scheduled lighting.
- Before installation at Congregation Beth Sholom, confirm the controller
  network address and load the production wall geometry into the controller.
- The web interface is intended for use on the synagogue's protected internal
  network. Any remote access or additional authentication must be supplied by
  the synagogue's network environment.

## Verification

V3 includes automated policy tests which compare the names selected for weekly
reports with the names selected for weekly lighting. The current regression
run performs 50,796 such comparisons across the memorial database and a range
of calendar dates. Explicit regression cases also cover leap years, the civil
December 31/January 1 boundary, and the Hebrew 29 Elul/1 Tishri boundary.

Installation, Minhag updates, managed cron replacement, logging, controller
communication, CSV preservation, and repeated installation have also been
tested on Intel NUC appliance hardware.

## See Also

- **Project**
  - [`./README.md`](../README.md)
- **Server**
  - [`./yahrzeit_site-v3/README.md`](../yahrzeit_site-v3/README.md)
  - [`./yahrzeit_site-v3/INSTALL.md`](../yahrzeit_site-v3/INSTALL.md)
- **Controller**
  - [`./embedded/yahrzeit_v3/README.md`](../embedded/yahrzeit_v3/README.md)
  - [`./embedded/yahrzeit_v3/INSTALL.md`](../embedded/yahrzeit_v3/INSTALL.md)
- **Hardware**
  - [`./Hardware/README.md`](../Hardware/README.md)

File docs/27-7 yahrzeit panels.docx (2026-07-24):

27-7 Yahrzeit Panels

The Yahrzeit Panels are etched glass panels with an automated lighting mechanism. These panels memorialize the names and dates of death of members of the congregation or their families.

Manufacturer: On-Site Systems Inc. http://www.on-sitesystems.com (http://osshome.com/)

Yyz Systems Inc http://www.yyzsystems.com

Model Number: custom

Maintenance: Clean the glass monthly, with Windex wipes or equivalent

Service: Glass – On-Site Systems

Electronics – Yyz Systems

Software – Allan Schwartz

Repair/reprint panels of glass – On-Site Systems

Location: Sanctuary west wall

Installers: On-Site Systems Inc. http://www.on-sitesystems.com (http://osshome.com/)

Gary Taylor gary@on-sitesystems.com 800-838-7778

Yyz Systems Inc http://www.yyzsystems.com

Marko Hajdinovic marko@yyzsystems.com 905-795-8500

Allan Schwartz allanschwartz@sbcglobal.net 408-829-8046


This document doesn’t discuss the software, see section 27-8 Yahrzeit Server. A broader overview of the Yahrzeit Wall can be found in section 27-6 Yahrzeit Wall Overview.

PROCEDURE: How-To Create and/or Modify A Yahrzeit Panel

It is advisable to create and/or modify one, two or three panels at one time – because we own three spare panels, and we have a shipping crate that holds exactly three panels.

Step 1: Advertise. via email or mailings to the congregation 4 months prior to the target installation, timed for a particular Yizkor observance, in order to capture the needed information in an efficient and timely manner.

It is most efficient to batch entries, additions and any necessary changes or corrections. This process has proven to be complex. In an effort to streamline this process, follow these recommendations:

Step 2: Sales. Collect ACCURATE and CENTRALIZED data for new additions (names of decreased, Hebrew and English date(s) of death, etc) and any changes or corrections to existing entries. Information should be collected on a form, then transferred to a spreadsheet with the following columns:


Step 3: Based on the number of the additional names, the designer will decide where the changes will go and which panel(s) will be modified.

Step 4: Record.
Update the spreadsheet with the purchased names, then sort (each panel is alphabetized) and add the panel locations. This is column K in the above illustration, blank at time Step 2 is done, utilized at this time.

Step 5: Update Illustrator files

Step 6: Review process involving congregants

Send email to each congregant who has purchased a name. The email should show a view of the panel and reflect the new addition or any changes. The most effective way to do this is to take a Screen Snapshot with Illustrator running, then crop so it so that a relatively small .PNG file is saved. Email just that small .PNG file to the congregant. For example:

Mailing the multi-megabyte .PDF file seemed to be problematic with more than half of the last set of congregants, but everyone should be able to receive an embedded .PNG image in an email. Allow each congregant to reply back with satisfaction or corrections, but impose a deadline. Sometimes, the congregant may have come into the office to view the paper copy, or show you a photo of the gravestone.

Print a proof copy of the finished panel (on 33.5” x 33.5” sheet of paper or vellum), and proof the corrections carefully. Tape this sheet up over the actual glass panel to be reprinted. Notify the congregation that on the upcoming Shabbat all may view a proof of the panel.

Corrections should be captured on another form, and previous documentation, i.e., the form, email, or photos of gravestones should be attached. Source documents such as these forms, emails, etc. should be carefully organized in a binder.

Step 7 / Step 8 / Step 9 / Step 10

Repeat “Record” and “Review Process” two additional times and proofread every single entry.

Step 11: Ship spare pieces of glass to On-Site

Our 3 spare pieces of glass are already packed in a crate, and the crate is currently in the large closet in Koret Hall.

Step 12: Production. Finalize files including vectorize all text, and produce PDF. Email PDF and illustrator files to On-Site .

Step 13: The yahrzeit database which the Yahrzeit Server uses needs to be updated to include all the new records. Test the yahrzeit server lights behind the new names in both yahrzeit-mode and yizkor-mode.

Step 14: On-Site Systems has their own production schedule for printing the glass. This takes approximately three weeks.

Step 15: On-Site Systems will ship the crate with the three new pieces of glass back to CBS.

Step 16: Installation. Receive new glass panels from OnSite

They will come back in the same crate. Install new pieces of glass. Call in a vendor (Allan Schwartz or someone with glass-handling experience) to swap the old panels of glass with the newly-printed panels of glass.

The old panels of glass then become our spare pieces and should be packed for shipment in the crate. The crate is stored in the Koret Hall closet, ready for the next cycle.

Step 17: Completion.

Announce the new Yahrzeit Panels in HaRuach and/or HaLuach; email all congregants who purchased a name. Re-test the yahrzeit server lights behind the new names in both yahrzeit-mode and yizkor-mode.

How long does this process take and how do we plan for the next cycle?

Duration Aug/2008 Pesach next H.H.

ADVERTISE: 1 wk May 16 jan May & June

SALES: 8 wks june&july now–Feb 17 May & June

Collect 8 wks june 1–july 31 now–feb 13 May & June

final data to designer 4 days aug 1–aug 4 feb 16–17 june 25–30

REVIEW: 4 wks Aug. Feb. July

1st draft create artwork 4 days aug 4-8 feb 17–20 july 1–3

1st review process 5 days aug 8-13 feb 20–24 july 3–8

2nd draft create artwork 2 days aug 14-15 feb 24–25 july 9–10

2nd review process 5 days aug 15-20 feb 26–mar 2 july 10–15

3rd draft create artwork 2 days aug 21-22 not needed not needed

3rd review 5 days aug 22-27

final draft create artwork 2 days aug 28-29 Mar 2–3 july 16–17

final review 5 days aug 29-sep 3 mar 4–9 july 17–24

PRODUCTION: 4 wks Sep. Mar. Aug.

finalize files, to OSS 1 days sep 4 mar 9 aug 3

fix yahrzeit database 1 wk sep 4-11 mar 9–16 aug 3–10

OSS production schedule 3 wk sep 4-19 mar 9–27 aug 3–21

ship glass back to cbs 1 wk sep 19-23 mar 30 aug 24–28

INSTALLATION: 2 days

receive & install glass 1 day Sep 23 Apr 6 mon aug 31

announce glass is up 1 day Sep 24 Apr 7 tue sep 1

test yahrzeit server 1 day Sep 24 Apr 7 tue sep 1

Although Pesach is a little tough for this year – from the standpoint of creating substantial sales then executing on-time – Shavout (May 30, 2009), is achievable:

Advertise: now

Sales: Feb & Mar

Review: Apr

Production: May

Installation wed. May 27

What are the resource requirements for a staffer and Allan Schwartz to do this work?

The following tables predicts an increase of efficiency over the first (June 2008-Sept 2008) cycle by a factor of 50%. We can do the same work in 50% of the staff time. It also assumes that between 40 and 80 names are either sold or need to be revised.

Duration Aug/2008 Pesach staff Allan

40-80 names

ADVERTISE: 1 wk May 16 jan

SALES: 8 wks june&july now–Feb 17

Collect 8 wks june 1–july 31 now–feb 13 20hr 4hr

final data to designer 4 days aug 1–aug 4 feb 16–17 4hr 4hr

REVIEW: 4 wks Aug. Feb. July

1st draft create artwork 4 days aug 4-8 feb 17–20 2hr 4hr

1st review process 5 days aug 8-13 feb 20–24 8hr

2nd draft create artwork 2 days aug 14-15 feb 24–25 2hr 4hr

2nd review process 5 days aug 15-20 feb 26–mar 2 8hr

3rd draft create artwork 2 days aug 21-22 not needed not needed

3rd review 5 days aug 22-27

final draft create artwork 2 days aug 28-29 Mar 2–3 2hr 4hr

final review 5 days aug 29-sep 3 mar 4–9 8hr 4hr

PRODUCTION: 4 wks Sep. Mar. Aug.

finalize files, to OSS 1 days sep 4 mar 9 4hr

fix yahrzeit database 1 wk sep 4-11 mar 9–16 8hr

OSS production schedule 3 wk sep 4-19 mar 9–27 2hr 4hr

ship glass back to cbs 1 wk sep 19-23 mar 30

INSTALLATION: 2 days

receive & install glass 1 day Sep 23 Apr 6 1hr 4hr

announce glass is up 1 day Sep 24 Apr 7 4hr

test yahrzeit server 1 day Sep 24 Apr 7 4hr

10 days 6 days

27-7 Yahrzeit Panels Page 5 of 5

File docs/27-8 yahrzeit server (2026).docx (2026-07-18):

### 27-8 Yahrzeit Server

The Yahrzeit Wall is an etched-glass memorial display with individually controlled LEDs. A dedicated server calculates Yahrzeit and Yizkor observances according to synagogue policy and sends the required lighting pattern to the wall controller.

Synagogue staff normally review and maintain the system through its browser interface. Lighting operates automatically, with manual controls available when needed.

Manufacturer: On-Site Systems Inc., Yyz Systems Inc, & Allan Schwartz

Model Number: custom installation

Maintenance: See the Maintenance section in the User Guide.

Service: Electronics – Yyz Systems

Software – Allan Schwartz

Repair/reprint panels of glass – On-Site Systems

Location: Sanctuary west wall

Installers: On-Site Systems Inc. http://www.on-sitesystems.com (http://osshome.com/)

Gary Taylor gary@on-sitesystems.com 800-838-7778

Yyz Systems Inc http://www.yyzsystems.com

Marko Hajdinovic marko@yyzsystems.com 905-795-8500

Allan Schwartz allanschwartz@sbcglobal.net 669-350-7296


This section describes the Yahrzeit Server and its operator interface. See section 27-6, Yahrzeit Overview, for the complete system and section 27-7, Yahrzeit Panels, for the etched-glass panels.

The Yahrzeit system has three software components:

- Web interface — maintains memorial records and synagogue policy, displays status, and runs reports.
- Automation software — schedules Yahrzeit and Yizkor operations and sends lighting commands to the controller.
- Controller firmware — receives those commands and drives the Wall’s LED array.

A dedicated Linux appliance in the synagogue office hosts the web interface and automation software. It communicates with the Arduino-based Yahrzeit Controller over the synagogue Ethernet network.

### Accessing the Yahrzeit Server’s User Interface

Synagogue staff and the Rabbi use the browser interface for routine operation. In any current web browser, open:

http://192.168.2.148/yahrzeit

Complete operating instructions are maintained in the online User Guide, available through the User Guide button in the Yahrzeit Wall interface.

Note: If the address above no longer works, contact the person responsible for the synagogue network or consult section 27-4, Networking. Record any permanent address change in this manual.

### Logging in to the Yahrzeit Server via SSH

Routine operation is performed through the browser interface. SSH access is reserved for a technical administrator performing installation, recovery, or diagnostic work.

From a terminal, enter:

ssh <administrator>@<Yahrzeit-server-address>

Use the appliance administrator’s login name and the same server address used for the browser interface. Administrator credentials and recovery information should be kept in the synagogue’s secured technical records. Do not record a password in this House Manual.

### Installing the Yahrzeit Software or Replacing the Yahrzeit Server

Replacing the Yahrzeit Server is a technical maintenance operation for a person familiar with Linux, networking, and command-line administration. The source code, installer, and current technical documentation are maintained at:

https://github.com/allanschwartz/yahrzeit

Begin with an Intel NUC or similar computer running a current Ubuntu Server LTS release. Connect it to the wired network and enable OpenSSH during Ubuntu installation.

Log in as the appliance administrator and run:

curl -fsSL \

https://raw.githubusercontent.com/allanschwartz/yahrzeit/master/yahrzeit_site-v3/bin/install-yahrzeit.sh \

-o /tmp/install-yahrzeit.sh

bash /tmp/install-yahrzeit.sh

The installer installs the required Linux packages, downloads the Yahrzeit application, configures Apache and PHP, enables SSH, and performs non-transmitting software checks. By default, it installs the application at:

~/src/yahrzeit/yahrzeit_site-v3

and makes the browser interface available at:

http://<appliance-address>/yahrzeit/

After installation, the technical administrator must:

1. Restore or verify data/yahrzeits-rev4.csv.
2. Open the Minhag page, verify the synagogue settings, and save them.
3. Verify the Yahrzeit Controller address recorded by the installer.
4. Run the database audit and command preview.
5. Verify the browser interface before performing a live lighting test.

From the application directory, the initial checks are:

bin/yahrzeit --audit

bin/yahrzeit --dry-run

Do not perform a live lighting operation until the controller address and the generated lighting pattern have been verified.

Additional technical instructions are located in:

yahrzeit_site-v3/README.md

yahrzeit_site-v3/docs/yahrzeit-installer-notes.txt

### Online User Guide

The online User Guide is reproduced after this section. The current version is also available through the User Guide button in the Yahrzeit Wall web interface.

27-8 Yahrzeit Server Page of

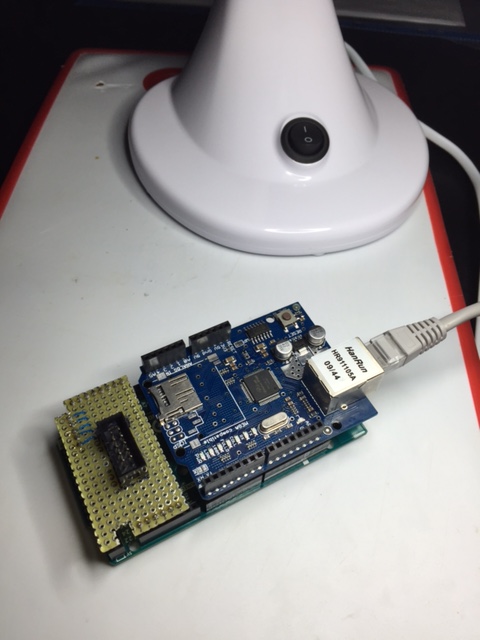
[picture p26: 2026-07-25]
Hardware/YYZ_SHIELD_v2/prototype assm1.jpg

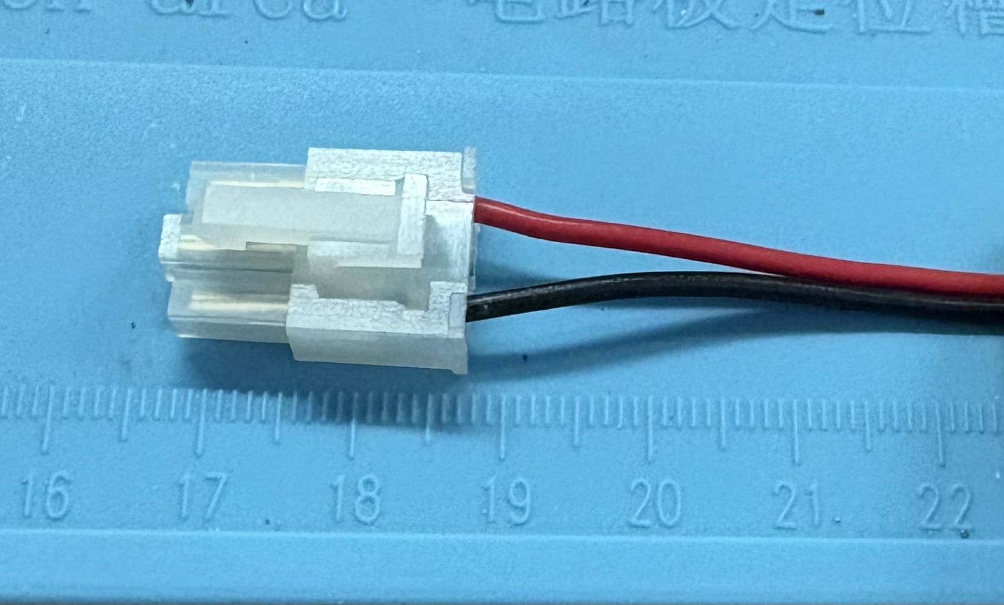
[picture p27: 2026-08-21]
Hardware/cables/molex_5557-03R.JPG

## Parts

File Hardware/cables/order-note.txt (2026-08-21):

That looks like a sensible first production request.

The quantities line up well with the installation strategy:

   • CBL-01: 25         (adapter molex-r)
   • CBL-02: 25         (adapter molex-p)
   • CBL-03: 280        (jst-vh 100mm)
   • CBL-04: 40         (jst-vh 600mm)
   • CBL-05: 280        (ribbon 100mm)
   • CBL-06: 7          (ribbon 2800mm)

For the RFQ, I’d ask for **one sample of each cable first**, then separate pricing for those production quantities. For CBL-06, I’d explicitly mark the 2800 mm length as provisional and say final production release depends on field measurement.

That gives you a clean vendor workflow: approve six first articles, then release the bulk order. Good stopping point for today.

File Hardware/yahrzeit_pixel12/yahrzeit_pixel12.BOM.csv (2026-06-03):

Reference | Qty | Value | Footprint | supplier and part number | Description
C1 | 1 | 100µF | Capacitor_SMD:CP_Elec_6.3x7.7 | KEMET A768EB107M1ELAS036 | CAP ALUM POLY 100UF 20% 25V SMD
C2,C3,C4,C5,C6,C7,C8,C9,C10,C11,C12,C13,C14,C15,C16,C17,C18,C19 | 18 | 0.1µF | Capacitor_SMD:C_0603_1608Metric | NextGen 0603B104K250SD | CAP,SMD,0603,X7R,0.1UF,10%,25V
CN1,CN2 | 2 | Conn_02x05 | Connector_PinHeader_2.54mm:PinHeader_2x05_P2.54mm_Vertical | digikey 1849-1002-ND | CONN HEADER VERT 10POS (2x5) 2.54MM
LED1,LED2,LED3,LED4,LED5,LED6,LED7,LED8,LED9,LED10,LED11,LED12,LED13,LED14,LED15,LED16,LED17,LED18,LED19,LED20,LED21,LED22,LED23,LED24,LED25,LED26,LED27,LED28,LED29,LED30,LED31,LED32,LED33,LED34,LED35,LED36,LED37,LED38,LED39,LED40,LED41,LED42,LED43,LED44,LED45,LED46,LED47,LED48,LED49,LED50,LED51,LED52,LED53,LED54,LED55,LED56,LED57,LED58,LED59,LED60,LED61,LED62,LED63,LED64,LED65,LED66,LED67,LED68,LED69,LED70,LED71,LED72 | 72 | LED | LED_SMD:LED_0805_2012Metric | YY0805RE-NN3S0-T3AR4 | LED RED CLEAR 0805 SMD
PWR1,PWR2 | 2 | JST B2P-VH | Connector_JST:JST_VH_B2P-VH_1x02_P3.96mm_Vertical | JST B2P-VH | CONN HEADER VERT 2POS 3.96MM, JST VH
R1,R2,R3,R4,R5,R6,R7,R8,R9,R10,R11,R12,R13,R14,R15,R16,R17,R18,R19,R20,R21,R22,R23,R24,R25,R26,R27,R28,R29,R30,R31,R32,R33,R34,R35,R36,R37,R38,R39,R40,R41,R42,R43,R44,R45,R46,R47,R48,R49,R50,R51,R52,R53,R54,R55,R56,R57,R58,R59,R60,R61,R62,R63,R64,R65,R66,R67,R68,R69,R70,R71,R72 | 72 | 1k | Resistor_SMD:R_0603_1608Metric | RM06F1001CT | RES 1K OHM 1% 1/16W 0603
U1,U3,U5,U7,U9,U11,U13,U15,U17 | 9 | 74HC245 | Package_SO:SO-20_5.3x12.6mm_P1.27mm | TI SN74HC245NST | IC TXRX NON-INVERT 6V 20-SO
U2,U4,U6,U8,U10,U12,U14,U16,U18 | 9 | 74HC595 | Package_SO:JEITA_SOIC-16_3.9x9.9mm_P1.27mm | Toshiba 74HC595D | IC SR TRI-STATE 8BIT 16-SOIC

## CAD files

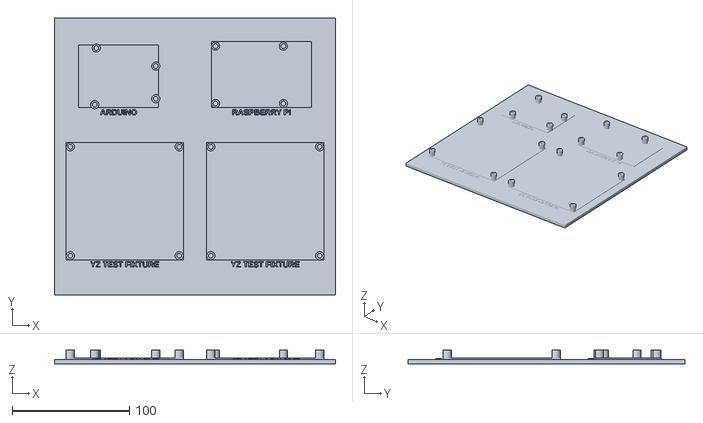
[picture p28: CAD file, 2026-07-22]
Hardware/3D Printing/fixture_plate.stl
240.0 x 236.5 x 12.0

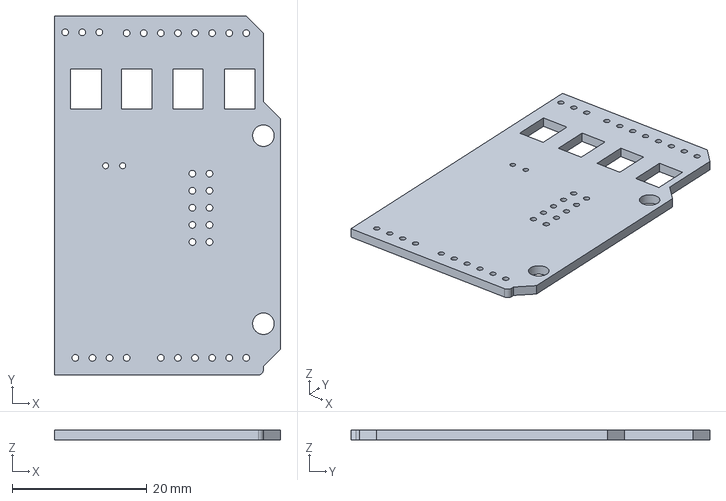
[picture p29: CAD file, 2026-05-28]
pixel_interface/test_shield/test_shield.step
33.6 x 53.3 x 1.51 mm

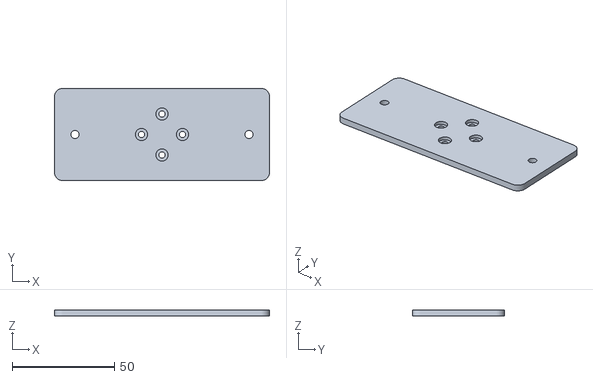
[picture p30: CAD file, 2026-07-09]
Hardware/3D Printing/mount_flange.stl
105.0 x 45.0 x 3.00

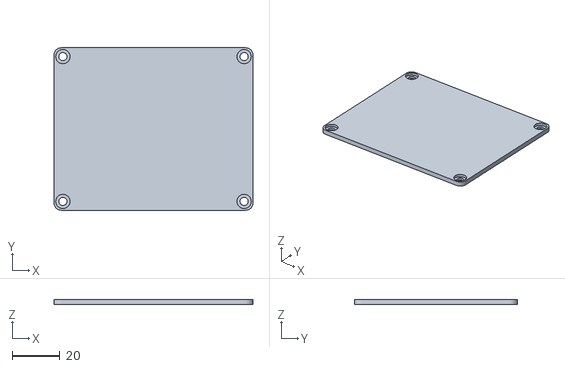
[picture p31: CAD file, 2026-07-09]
Hardware/3D Printing/yahrzeit_controller_case-cover.stl
83.0 x 67.8 x 2.20

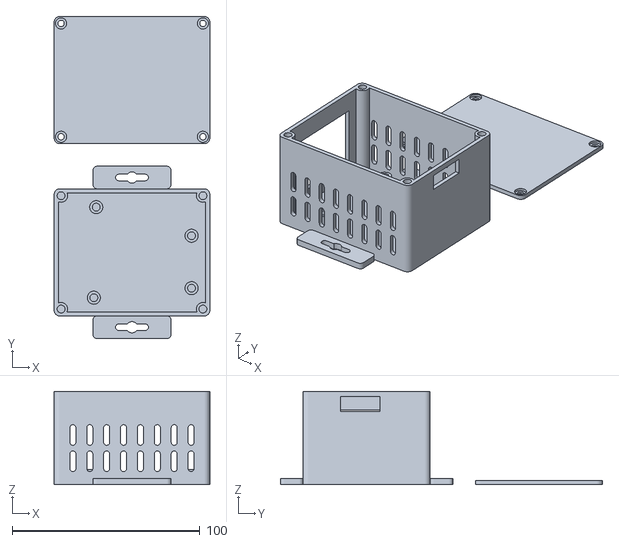
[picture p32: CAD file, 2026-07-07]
Hardware/3D Printing/yahrzeit_controller_case.stl
83.0 x 171.6 x 49.8

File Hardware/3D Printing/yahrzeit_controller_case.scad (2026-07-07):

// Arduino Uno R4 + Ethernet shield + small shield case
// Intended for a wall-mounted enclosure with keyholes and M3 brass inserts
//
// Coordinate convention:
// - Origin at the bottom of the Uno board (zero plane)
// - +Z is upward
// - "power side" is the side with barrel jack, USB-C power, and reset button
//
// This is a starting parametric model. Dimensions are chosen conservatively
// and can be refined after measuring the real hardware.

/* [Board stack] */
uno_length = 68.6;
uno_width = 53.4;
pcb_thickness = 1.6;

/* [General] */
case_wall_thickness = 2.2;
case_bottom_thickness = 2.2;
case_top_thickness = 2.2;
// Free space between the board stack footprint and the inside wall.
// 5 mm leaves room for M3 cover-insert posts merged into the case corners.
board_side_clearance = 5.0;
case_length = uno_length + 2 * board_side_clearance + 2 * case_wall_thickness;
case_width = uno_width + 2 * board_side_clearance + 2 * case_wall_thickness;


ethernet_pcb_bottom_above_uno_bottom = 17.0;
pixel_if_pcb_bottom_above_ethernet_bottom = 15.0;
top_clearance_above_stack = 8.0;

/* [Mounting hardware] */
standoff_od = 7.0;
insert_hole_d = 4.2;     // pilot hole for M3 heat-set insert; copied from fixture_plate.scad
standoff_height = 6.0;

/* [Wall mounting] */
flange_width = 12.0;
flange_corner_radius = 2;
flange_thickness = case_bottom_thickness + 1.0;
flange_length = case_length / 2;
keyhole_slot_width = 3.5;
keyhole_slot_length = 14.0;
keyhole_head_diam = 6.0;
keyhole_center_x = case_length / 2;

/* [front panel] */
front_panel_width = 42;
front_panel_height = 30;
front_panel_y0 = 13;
front_panel_z0 = case_bottom_thickness + standoff_height + pcb_thickness;

/* [rear panels] */
rear_panel_width = 21;
rear_panel_height = 8;
rear_panel_y0 = 20;
rear_panel_z0 = 39;

/* [Ventilation] */
vent_slot_width = 3.2;
vent_slot_height = 11.0;
vent_pitch_x = 9.0;
vent_pitch_z = 14.0;
vent_margin_x = 10.0;
vent_margin_z = 7.0;

/* [Cover attachment] */
cover_post_od = 7.0;
cover_post_wall_overlap = 2.0;
cover_screw_hole_diam = 3.4;
cover_screw_recess_diam = 6.0;
cover_screw_recess_depth = 1.2;

/* [Derived] */

uno_bottom_z = case_bottom_thickness + standoff_height;
ethernet_bottom_z = uno_bottom_z + ethernet_pcb_bottom_above_uno_bottom;
pixel_if_bottom_z = ethernet_bottom_z + pixel_if_pcb_bottom_above_ethernet_bottom;
stack_top_z = pixel_if_bottom_z + pcb_thickness;
case_height = max(stack_top_z + top_clearance_above_stack, 30);
cover_post_z0 = 0;
cover_post_height = case_height;
board_origin_x = case_wall_thickness + board_side_clearance;
board_origin_y = case_wall_thickness + board_side_clearance;
cover_post_offset = case_wall_thickness + cover_post_od / 2 - cover_post_wall_overlap;


// Arduino Uno R4 Minima mounting hole coordinates from ABX00080 mechanical drawing.
// Origin is lower-left of the board outline.
arduino_mount_holes = [
    [13.97,  2.54],
    [66.04,  7.62],
    [66.04, 35.56],
    [15.24, 50.80]
];

cover_screw_points = [
    [cover_post_offset, cover_post_offset],
    [case_length - cover_post_offset, cover_post_offset],
    [cover_post_offset, case_width - cover_post_offset],
    [case_length - cover_post_offset, case_width - cover_post_offset]
];

module rounded_rect(size, r) {
    hull() {
        translate([r, r, 0]) cylinder(h=size[2], r=r, $fn=48);
        translate([size[0]-r, r, 0]) cylinder(h=size[2], r=r, $fn=48);
        translate([r, size[1]-r, 0]) cylinder(h=size[2], r=r, $fn=48);
        translate([size[0]-r, size[1]-r, 0]) cylinder(h=size[2], r=r, $fn=48);
    }
}

module standoff(x, y, z0) {
    translate([x, y, z0]) {
        difference() {
            cylinder(h = standoff_height, d = standoff_od, $fn=48);
            translate([0,0,-0.1]) cylinder(h = standoff_height + 0.2, d = insert_hole_d, $fn=48);
        }
    }
}

module cover_post(x, y) {
    translate([x, y, cover_post_z0])
        cylinder(h = cover_post_height, d = cover_post_od, $fn=48);
}

module cover_insert_hole(x, y) {
    translate([x, y, case_height - standoff_height - 0.1])
        cylinder(h = standoff_height + 0.2, d = insert_hole_d, $fn=48);
}

module flange(y0) {
    translate([(case_length - flange_length) / 2, y0, 0])
        rounded_rect([flange_length, flange_width, flange_thickness], r=flange_corner_radius);
}

module keyhole_cutout(x, y) {
    translate([x, y, -1]) {
        hull() {
            translate([-keyhole_slot_length / 2, 0, 0])
                cylinder(h = flange_thickness + 2, d = keyhole_slot_width, $fn=48);
            translate([keyhole_slot_length / 2, 0, 0])
                cylinder(h = flange_thickness + 2, d = keyhole_slot_width, $fn=48);
        }

        cylinder(h = flange_thickness + 2, d = keyhole_head_diam, $fn=48);
    }
}

module side_vent_pattern() {
    for (x = [vent_margin_x : vent_pitch_x : case_length - vent_margin_x]) {
        for (z = [vent_margin_z + vent_slot_height / 2
                : vent_pitch_z
                : case_height - vent_margin_z - vent_slot_height / 2]) {
            // South/north wall ventilation. Each cutout is a rounded vertical
            // slot extruded through the wall in Y.
            vent_slot_y_wall(x, case_wall_thickness + 1, z);
            vent_slot_y_wall(x, case_width + 1, z);
        }
    }
}

module vent_slot_y_wall(x, y, z) {
    hull() {
        translate([x, y, z - vent_slot_height / 2 + vent_slot_width / 2])
            rotate([90, 0, 0])
                cylinder(h = case_wall_thickness + 2, d = vent_slot_width, $fn=24);
        translate([x, y, z + vent_slot_height / 2 - vent_slot_width / 2])
            rotate([90, 0, 0])
                cylinder(h = case_wall_thickness + 2, d = vent_slot_width, $fn=24);
    }
}

// The front panel is for the power and Ethernet connectors
module front_panel_opening() {
    translate([-1,
               front_panel_y0,
               front_panel_z0])
        cube([case_wall_thickness + 2,
              front_panel_width,
              front_panel_height]);
}

// the rear panel is for the data cable.
module rear_panel_opening() {
    translate([case_length - case_wall_thickness - 1,
               rear_panel_y0,
               rear_panel_z0])
        cube([case_wall_thickness + 2,
              rear_panel_width,
              rear_panel_height]);
}

module main_case() {
    difference() {
        union() {
            difference() {
                union() {
                    // Outer shell
                    rounded_rect([case_length, case_width, case_height], r=3);

                    // Opposing wall-mount flanges, on the north/south sides.
                    flange(-flange_width);
                    flange(case_width);
                }

                // Hollow interior
                translate([case_wall_thickness, case_wall_thickness, case_bottom_thickness])
                    rounded_rect([case_length - 2*case_wall_thickness, case_width - 2*case_wall_thickness, case_height], r=2);

                // panel openings
                front_panel_opening();
                rear_panel_opening();

                // Ventilation holes on the side walls
                side_vent_pattern();

                // Keyhole openings in the north/south flanges.
                for (y = [-flange_width / 2, case_width + flange_width / 2]) {
                    keyhole_cutout(keyhole_center_x, y);
                }
            }

            // Cover screw posts, merged into the upper half of the case.
            for (p = cover_screw_points) {
                cover_post(p[0], p[1]);
            }
        }

        // Drill the insert holes after the posts are merged into the case body.
        for (p = cover_screw_points) {
            cover_insert_hole(p[0], p[1]);
        }

    }

    // Standoffs inside the bottom shell, aligned to the Arduino Uno holes.
    for (p = arduino_mount_holes) {
        standoff(board_origin_x + p[0],
                 board_origin_y + p[1],
                 case_bottom_thickness);
    }
}

module top_cover() {
    difference() {
        rounded_rect([case_length, case_width, case_top_thickness], r=3);

        // Four mounting holes for M3 screws into the cover-post inserts.
        for (p = cover_screw_points) {
            translate([p[0], p[1], -1]) cylinder(h = case_top_thickness + 2, d = cover_screw_hole_diam, $fn=24);
            translate([p[0], p[1], case_top_thickness - cover_screw_recess_depth]) cylinder(h = cover_screw_recess_depth + 1, d = cover_screw_recess_diam, $fn=24);
        }
    }
}

main_case();
// Separate, flat-printable cover preview.
translate([0, case_width + flange_width + 12, 0])
    top_cover();

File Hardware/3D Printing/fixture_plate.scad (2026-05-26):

// Yahrzeit Wall Test Fixture Plate
// Units: mm

// -----------------------------------------------------------------------------
// Global parameters
// -----------------------------------------------------------------------------

plate_w = 240;
plate_thickness = 4.0;

edge_gap = 20;
row_gap = 20;

platform_h = 1.0;       // its easy to change filament on mm boundaries
standoff_h = 7.0;       // the screw sizes I have on hand influence this height

standoff_od = 7;
insert_hole_d = 4.2;     // pilot hole for M3 heat-set insert; verify for your insert
standoff_fn = 48;

legend_h = 0.6;
legend_size = 5;
legend_font = "Liberation Sans:style=Bold";
legend_gap = 4;        // gap between board/platform and label
legend_band = 10;      // vertical space reserved below each board row

// Visual colors for OpenSCAD preview.
// For actual tri-color printing, export/separate bodies or use slicer color changes.
base_color = "gray";
platform_color = "green";
standoff_color = "white";

// -----------------------------------------------------------------------------
// Board dimensions
// -----------------------------------------------------------------------------

yz_w = 100;
yz_h = 100;

raspi_w = 85.6;
raspi_h = 56.5;

arduino_w = 68.6;
arduino_h = 53.4;

// Horizontal spacing
top_pair_gap = 45;

yz_side_gap = 10;
yz_mid_gap = 20;

// Derived bottom row positions
yz1_x = yz_side_gap;
yz2_x = yz1_x + yz_w + yz_mid_gap;
yz_y  = edge_gap + legend_band;

// Derived top row positions
top_pair_w = arduino_w + top_pair_gap + raspi_w;
top_x = (plate_w - top_pair_w) / 2;

arduino_x = top_x;
raspi_x   = top_x + arduino_w + top_pair_gap;

top_row_h = max(arduino_h, raspi_h);
top_y = yz_y + yz_h + row_gap + legend_band;

// Plate height
plate_h = top_y + top_row_h + edge_gap;


// -----------------------------------------------------------------------------
// Basic parts
// -----------------------------------------------------------------------------

module plate()
{
    color(base_color)
        cube([plate_w, plate_h, plate_thickness]);
}

module platform(x, y, w, h)
{
    color(platform_color)
        translate([x, y, plate_thickness])
            cube([w, h, platform_h]);
}

module standoff_at(x, y)
{
    color(standoff_color)
        translate([x, y, plate_thickness])
            difference() {
                // Standoff extends from the base surface,
                // through the 1 mm platform, and 5 mm above it.
                cylinder(h=platform_h + standoff_h,
                         d=standoff_od,
                         $fn=standoff_fn);

                translate([0, 0, -0.1])
                    cylinder(h=platform_h + standoff_h + 0.2,
                             d=insert_hole_d,
                             $fn=standoff_fn);
            }
}

module raised_label(x, y, label)
{
    color(platform_color)
        translate([x, y, plate_thickness])
            linear_extrude(height=legend_h)
                text(label,
                     size=legend_size,
                     font=legend_font,
                     halign="center",
                     valign="center");
}

module board_platform(x, y, w, h, label, hole_xy)
{
    platform(x, y, w, h);

    for (p = hole_xy) {
        standoff_at(x + p[0], y + p[1]);
    }

    // Label centered below the board footprint.
    raised_label(x + w / 2, y - legend_gap, label);
}


// -----------------------------------------------------------------------------
// Board-specific platforms
// -----------------------------------------------------------------------------

module yz_test_fixture_platform(x, y)
{
    // Yahrzeit Wall Test Fixture: 100 x 100 mm, holes 3.5 mm from each corner.
    yz_holes = [
        [3.5,        3.5],
        [yz_w - 3.5, 3.5],
        [yz_w - 3.5, yz_h - 3.5],
        [3.5,        yz_h - 3.5]
    ];

    board_platform(x, y, yz_w, yz_h, "YZ TEST FIXTURE", yz_holes);
}

module raspi_board_platform(x, y)
{
    // Raspberry Pi full-size mounting holes:
    // 85.6 x 56.5 board, holes inset 3.5 mm from left/right and bottom/top.
    // Hole rectangle is therefore 58 x 49 mm.
    raspi_holes = [
        [3.5,            3.5],
        [3.5 + 58,       3.5],
        [3.5 + 58,       3.5 + 49],
        [3.5,            3.5 + 49]
    ];

    board_platform(x, y, raspi_w, raspi_h, "RASPBERRY PI", raspi_holes);
}

module arduino_board_platform(x, y)
{
    // Arduino Uno R3-ish mounting hole coordinates.
    // Origin is lower-left of the board outline in this fixture coordinate system.
    arduino_holes = [
        [14.0,  2.5],
        [66.1,  7.6],
        [66.1, 35.5],
        [15.3, 50.8]
    ];

    board_platform(x, y, arduino_w, arduino_h, "ARDUINO", arduino_holes);
}


// -----------------------------------------------------------------------------
// Assembly
// -----------------------------------------------------------------------------

plate();

arduino_board_platform(arduino_x, top_y);
raspi_board_platform(raspi_x, top_y);

yz_test_fixture_platform(yz1_x, yz_y);
yz_test_fixture_platform(yz2_x, yz_y);

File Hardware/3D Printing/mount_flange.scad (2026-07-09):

// Yahrzeit Embedded Controller
// Plywood mounting adapter for 65 mm wide enclosure
// Four-hole "+" mounting pattern
// Units: mm

$fn = 64;

// ---------- Enclosure is 65mm x 74mm, with 4 mounting threads ----------
box_w = 65;
screw_d = 3.0;          // clearance for M2.5 screw
screw_head_d = 6.0;
screw_head_depth = 1.5;
// Four enclosure mounting points
hole_spacing = 20;              // measured center-to-center
holes = [
    [-hole_spacing/2, 0],
    [ hole_spacing/2, 0],
    [0, -hole_spacing/2],
    [0,  hole_spacing/2]
];

// ---------- Adapter plate ----------
plate_w = box_w + 2 * 20;               // 20 mm flange each side
plate_h = 45;
plate_t = 3;

// ---------- Wood screw holes ----------
wood_hole_d = 4.0;
wood_head_d = 8.5;
wood_head_depth = 2.5;
wood_x = box_w/2 + 10;                // left/right screw spacing from center
wood_y = 0;

// ---------- Build ----------
adapter_plate();

module adapter_plate() {
    difference() {
        // main plate
        rounded_box([plate_w, plate_h, plate_t], 4);

        // M2.5 holes for enclosure
        // Enclosure mounting holes
        for (hole = holes) {

            // 3 mm clearance hole
            translate([hole[0], hole[1], -1])
                cylinder(d = screw_d, h = plate_t + 2);

            // Counterbore for screw head
            translate([hole[0], hole[1], plate_t - screw_head_depth])
                cylinder(d = screw_head_d, h = screw_head_depth + 1);
        }

        // wood screw holes in side flanges
        for (x = [-wood_x, wood_x]) {
            translate([x, wood_y, -1])
                cylinder(d = wood_hole_d, h = plate_t + 2);
        }
    }
}

module rounded_box(size, r) {
    x = size[0];
    y = size[1];
    z = size[2];

    hull() {
        for (ix = [-1, 1])
            for (iy = [-1, 1])
                translate([ix*(x/2-r), iy*(y/2-r), 0])
                    cylinder(r = r, h = z);
    }
}

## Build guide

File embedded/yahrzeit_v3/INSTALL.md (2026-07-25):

# Yahrzeit Embedded Controller — Installation Notes

These notes describe how to build, install, and verify the firmware for the
Arduino-based Yahrzeit Wall controller. They are intended for installation or
replacement of the controller, not for routine operation of the wall.

The firmware is not installed by a script. It is configured in the source,
compiled with the Arduino toolchain, and uploaded over USB.

<p align="center">
  <a href="images/arduino-uno-r4-minima.jpg">
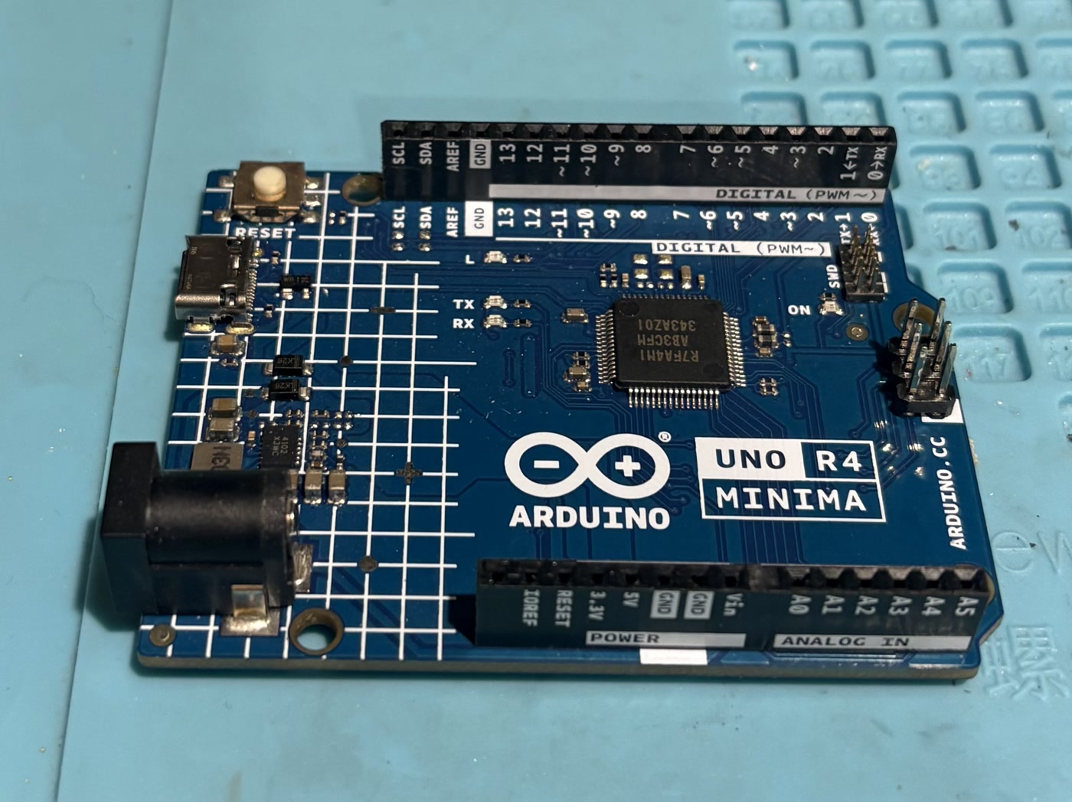
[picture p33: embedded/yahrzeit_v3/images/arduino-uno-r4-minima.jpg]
Arduino Uno R4 Minima used by the Yahrzeit controller
    
  </a>
</p>

*Arduino Uno R4 Minima used by the Yahrzeit embedded controller.*

## Hardware

The production controller stack is:

```text
Arduino Uno R4 Minima
  -> Arduino Ethernet Shield 2 or compatible W5100/W5500 shield
    -> Yahrzeit Controller Pixel Interface board
      -> ribbon cable to the YYZ Pixel board chain
```

<table>
  <tr>
    <td align="center">
      <a href="images/arduino-uno-r4-minima.jpg">
        Arduino Uno R4 Minima
      </a><br>
      <em>Arduino Uno R4 Minima</em>
    </td>
    <td align="center">
      <a href="images/arduino-ethernet-shield.jpg">
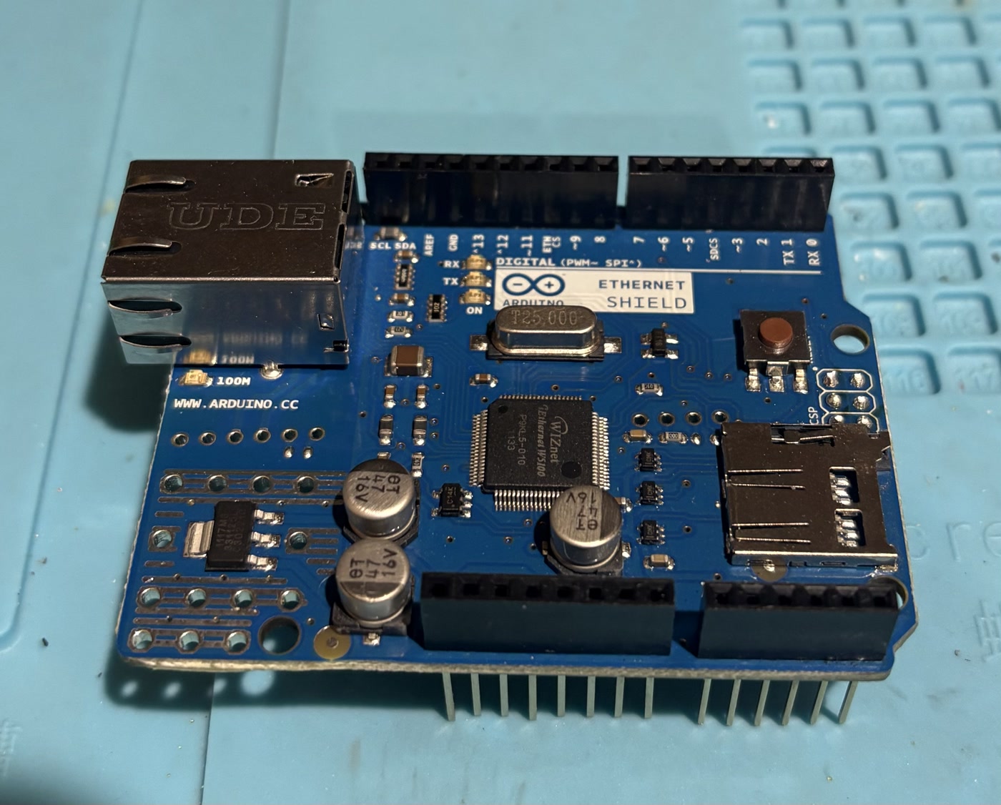
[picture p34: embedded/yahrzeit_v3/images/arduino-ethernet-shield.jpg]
Arduino Ethernet shield
        
      </a><br>
      <em>Ethernet shield</em>
    </td>
    <td align="center">
      <a href="images/yahrzeit-pixel-interface-board.jpg">
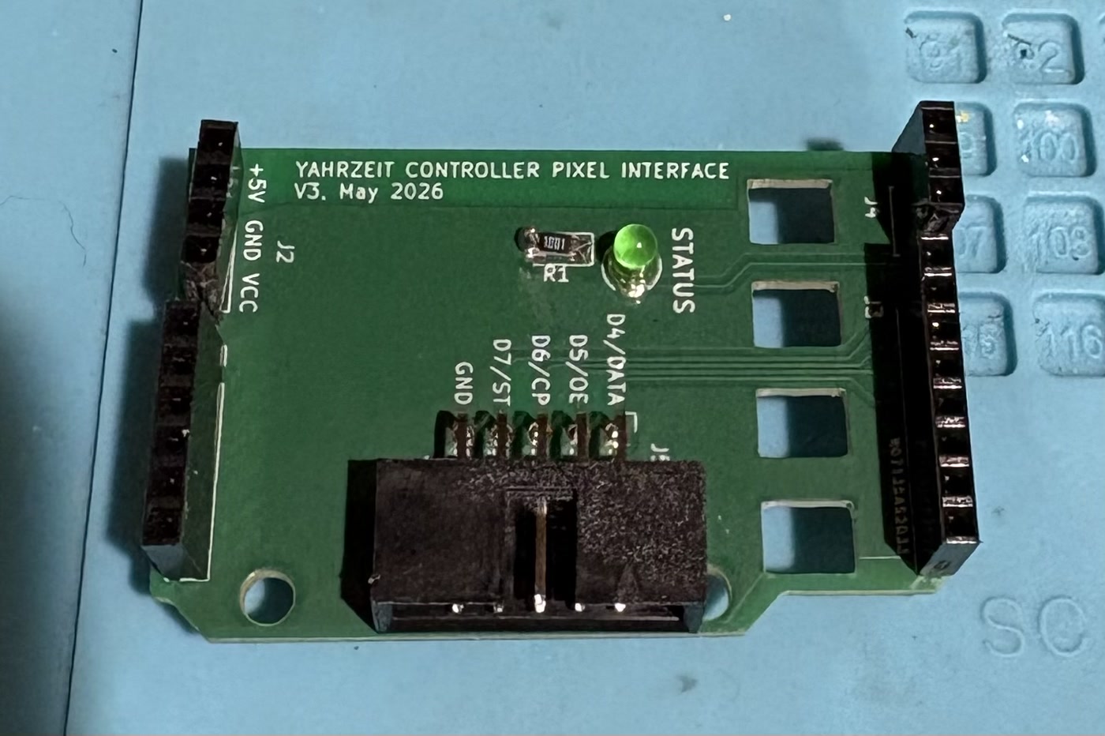
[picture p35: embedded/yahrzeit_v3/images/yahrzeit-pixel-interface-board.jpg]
Yahrzeit Controller Pixel Interface board
        
      </a><br>
      <em>Yahrzeit Controller Pixel Interface</em>
    </td>
  </tr>
</table>

The commercial enclosure has a DIN-rail attachment, but the wall installation
uses a custom 3D-printed flange for flat mounting. Remove the flange from the
wall by removing its two self-tapping wood screws. Retain those screws and use
them to reinstall the controller in the same location.

The clear cover deliberately fits snugly against the tops of the connectors.
When its screws are tightened, the cover helps keep the three stacked boards
from separating through vibration—or, this being San Francisco, an earthquake.
Do not add spacers that defeat this retaining function.

The enclosure assembly uses M2.5 x 5mm machine screws. They can be difficult
to obtain in the United States. Keep all removed screws together, and obtain
replacements before beginning installation if any are missing.

The 3D-print source and output for the mounting flange are:

- [`mount_flange.scad`](../../Hardware/3D%20Printing/mount_flange.scad)
- [`mount_flange.stl`](../../Hardware/3D%20Printing/mount_flange.stl)

The same repository directory contains the OpenSCAD and STL files for an
alternative 3D-printable controller enclosure. However, the commercial
enclosure shown above is the preferred design.

Use the dedicated regulated Arduino power supply for production operation.
Do not depend on a computer's USB port to power the installed controller.

After startup completes, the green ALIVE LED on the Pixel Interface board
should slowly brighten and dim. This indicates that the firmware main loop is
running; it does not by itself prove that Ethernet communication is working.

Uploading or restarting the controller runs a short visible light test before
the saved display is restored. 

## Known-Working Development Toolchain

The following versions were installed on the development Mac in July 2026:

```text
Arduino IDE                       2.3.10
Arduino UNO R4 Boards core        1.6.0
Ethernet library                  2.0.2
```

Later compatible versions may also work, but have not been established by the
repository. If a different toolchain is used for a release, record its versions
with the release notes.

`EEPROM.h` is supplied by the Uno R4 board core. `Ethernet.h` is supplied by
the Arduino Ethernet library.

## Prepare the Arduino IDE

1. Install Arduino IDE 2.
2. In Boards Manager, install **Arduino UNO R4 Boards**.
3. In Library Manager, install **Ethernet** by Arduino.
4. Connect the Arduino Uno R4 Minima to the computer by USB.
5. Select **Arduino UNO R4 Minima** under **Tools > Board**.
6. Select the USB serial port for the connected controller.

Open `yahrzeit_v3.ino`. The Arduino IDE will load the other `.ino`, `.cpp`,
and `.h` files from the same sketch directory.

## Generate the Firmware Release Identifier

Immediately before compiling, run the release-header generator from a
terminal:

```sh
cd embedded/yahrzeit_v3
./generate-firmware-release.sh
```

The generated `firmware_release.h` is intentionally not committed. If the
current commit has a release tag, the firmware reports that tag, such as
`v3.0.1`. Otherwise, it reports the nearest tag followed by the commit distance
and abbreviated Git commit ID. A modified working tree also receives a
`-dirty` suffix.

## Configure the Production Build

Before compiling firmware for Congregation Beth Sholom, make both of the
following checks.

### Display geometry

In `yahrzeit_v3.h`, enable the production wall and disable the test fixture:

```cpp
#define CBS_56x40_WALL    1
// #define TEST_FIXTURE    1
```

Exactly one geometry must be enabled. The checked-in development source may
instead select `TEST_FIXTURE`; do not install that build on the full wall.

### Network configuration

<p align="center">
  <a href="images/arduino-ethernet-shield.jpg">
    Arduino Ethernet shield used by the Yahrzeit controller
  </a>
</p>

*The Ethernet shield provides the controller's wired network connection.*

In `yahrzeit_v3.ino`, confirm the production values in `networkConfig`:

```cpp
NetworkConfig networkConfig = {
    .mac = { 0x02, 0x19, 0x55, 0x11, 0x00, 0x09 },
        // Values used at Congregation Beth Sholom
        .ipAddr = IPAddress(192, 168, 13, 9),
        .dnsAddr = IPAddress(8, 8, 8, 8),
        .gateway = IPAddress(192, 168, 13, 8),
        .subnet = IPAddress(255, 255, 255, 0),
};

static constexpr uint16_t SOCKET_LISTEN_PORT = 2001;
```

These are the historical CBS values in the source. Confirm them with the
current network administrator before installation. The controller address and
port configured in the PHP appliance must agree with the firmware.

If an installed release intentionally changes the geometry or site network
values, commit and tag those source changes so the installed firmware can be
reproduced.

## Compile and Upload

1. Recheck the selected board, serial port, geometry, and network values.
2. Use **Sketch > Verify/Compile** and resolve all errors before proceeding.
3. Use **Sketch > Upload**.
4. Open Serial Monitor at **115200 baud**.
5. Select a line ending that includes newline, such as **New Line** or
   **Both NL & CR**.

On restart, the serial output should identify the controller, detected
Ethernet hardware, configured IP address, listening TCP port, and completion
of controller startup. An explicit `ethernet: no hardware`, `ethernet: link
down`, or `socket: not started` message must be resolved before installation
is considered complete.

## Initialize and Verify

Through Serial Monitor, run:

```text
version
status
test 1
```

`test 1` lights the four corners of the selected display or panel. Other test
patterns are documented in `README.md`.

For a new controller, or whenever the validity of EEPROM contents is unknown,
establish a known saved state:

```text
all off
refresh
save
```

The firmware loads its saved framebuffer from EEPROM at every startup. Firmware
upload normally does not establish or validate that saved display state.

From a machine on the controller network, verify the TCP interface:

```sh
nc <controller-address> 2001
```

Then enter:

```text
version
status
```

From the PHP appliance directory, first generate and inspect the normal command
stream without contacting the controller:

```sh
bin/yahrzeit --dry-run
```

Finally, after confirming the configured controller address and ensuring that
it is safe to change the wall, verify the complete production path:

```sh
bin/yahrzeit
```

The command computes and transmits the current normal Yahrzeit lighting,
refreshes the wall, and saves the resulting controller state. See `README.md`
for the controller command protocol and diagnostic commands.

## Installation Record

Record the following with the installation or maintenance record:

- controller network configuration,
- normal Yahrzeit and full-wall brightness values configured in the PHP
  appliance,
- selected geometry (for example, 56 rows x 40 columns),
- Arduino environment:
   - IDE version,
   - Arduino UNO R4 Boards core version,
   - Ethernet library version,
- repository commit and release tag,
- date of upload, and
- result of serial, TCP, and appliance verification.

## Recovery or Replacement

To replace the Arduino, assemble the same controller stack, build the tagged
production source with the recorded configuration, and repeat the upload and
verification procedure above.

## See Also

- **Project**
  - [`./README.md`](../../README.md)
- **Server**
  - [`./yahrzeit_site-v3/README.md`](../../yahrzeit_site-v3/README.md)
  - [`./yahrzeit_site-v3/INSTALL.md`](../../yahrzeit_site-v3/INSTALL.md)
- **Controller**
  - [`./embedded/yahrzeit_v3/README.md`](README.md)
  - [`./embedded/yahrzeit_v3/INSTALL.md`](INSTALL.md)
- **Hardware**
  - [`./Hardware/README.md`](../../Hardware/README.md)

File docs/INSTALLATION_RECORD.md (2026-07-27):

<p>
  Congregation Beth Sholom
</p>

# Yahrzeit Wall V3 Installation Record

Complete this record on site and place a printed copy in the Yahrzeit project
binder.

| Installation item | Installed value |
|---|---|
| Installation date | __________________________________________________ |
| Installed by | __________________________________________________ |
| Reviewed by | __________________________________________________ |
| Ubuntu LTS version | __________________________________________________ |
| Git tag installed | __________________________________________________ |
| Server administrator account | __________________________________________________ |
| Server hostname/IP address | __________________________________________________ |
| Primary Server URL | __________________________________________________ |
| Alternate Server URL | __________________________________________________ |
| Controller hostname | __________________________________________________ |
| Controller IP address | __________________________________________________ |
| Primary NUC location | __________________________________________________ |
| Spare NUC stored at | __________________________________________________ |
| Primary Controller location  | _Behind Yahrzeit Wall Panel 1C_ |
| Spare Controller stored at | __________________________________________________ |

## Installation and Maintenance History

Record all significant maintenance performed on this installation.

| Date | Performed By | Version | Description |
|---|---|---|---|
| 2026-07-29 | Allan Schwartz | V3.0.0 | Initial V3 installation and commissioning. |
| _____________ | | | |
| _____________ | | | |
| _____________ | | | |
| _____________ | | | |
| _____________ | | | |
| _____________ | | | |

## See Also

- **Project**
  - [`./README.md`](../README.md)
- **Server**
  - [`./yahrzeit_site-v3/README.md`](../yahrzeit_site-v3/README.md)
  - [`./yahrzeit_site-v3/INSTALL.md`](../yahrzeit_site-v3/INSTALL.md)
- **Controller**
  - [`./embedded/yahrzeit_v3/README.md`](../embedded/yahrzeit_v3/README.md)
  - [`./embedded/yahrzeit_v3/INSTALL.md`](../embedded/yahrzeit_v3/INSTALL.md)
- **Hardware**
  - [`./Hardware/README.md`](../Hardware/README.md)

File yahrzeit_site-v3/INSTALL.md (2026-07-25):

# Yahrzeit Server Appliance Installation

These notes describe how to install the Congregation Beth Sholom Yahrzeit Wall
PHP application on a fresh Ubuntu/Debian appliance.

<p align="center">
  <a href="images/intel-nuc-cutaway.jpg">
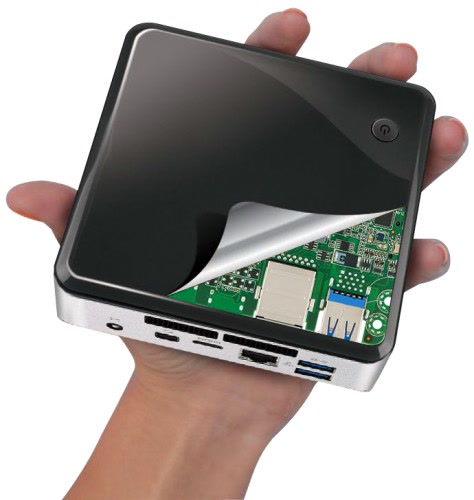
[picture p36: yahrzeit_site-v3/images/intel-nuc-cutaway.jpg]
Conceptual cutaway view of an Intel NUC
    
  </a>
</p>

*A conceptual cutaway view of an Intel NUC. The installer similarly peels back
the appliance's simple exterior and assembles the operating-system, web-server,
scheduling, and application layers inside.*

## Target Platform

- Intel NUC or similar x86-64 computer
- Fresh Ubuntu Server LTS installation
- Wired Ethernet
- Apache and PHP
- Application served at:

  ```text
  http://<appliance-ip>/yahrzeit/
  ```

## Installation Model

The installer is downloaded onto the appliance and run locally. It does not
transmit commands to the physical LED controller.

During an update, it remembers the controller address and brightness values
and preserves the two live data files:

```text
data/minhag.ini
data/yahrzeits-rev4.csv
```

It replaces the deployed code with the selected remote branch, restores the
live data, and asks whether to retain or replace the remembered controller
address. Source-code changes made directly in the appliance checkout are
discarded.

## Before Installation

1. Install Ubuntu Server LTS.
2. Enable OpenSSH during Ubuntu installation.
3. Log in as the appliance administrator.
4. Confirm the hostname, assigned address, and Internet access:

   ```sh
   hostname
   hostname -I
   ping -c 3 github.com
   ```

For production, the appliance should have a stable address. Use either a router
DHCP reservation or the site's Ubuntu network configuration, typically
`/etc/netplan/*.yaml`.

Change the production password before installing the appliance at the
synagogue.

## Run the Installer

Download and inspect the installer:

```sh
curl -fsSL -o /tmp/install-yahrzeit.sh \
  https://raw.githubusercontent.com/allanschwartz/yahrzeit/master/yahrzeit_site-v3/bin/install-yahrzeit.sh

less /tmp/install-yahrzeit.sh
```

Then run it:

```sh
bash /tmp/install-yahrzeit.sh
```

The installer is safe to rerun. It updates the deployed application and
refreshes the Apache configuration, web link, validation results, and managed
cron schedule.

## What the Installer Configures

- Git, using sparse checkout for `yahrzeit_site-v3`
- Apache
- a stable local Apache `ServerName`, avoiding warning `AH00558`
- PHP CLI and Apache PHP support
- `netcat` for controller communication
- GNU `timeout` support
- OpenSSH enabled and started
- cron enabled and started
- AppArmor disabled on this dedicated appliance
- `/var/www/html/yahrzeit` linked to the checked-out application
- a root-page redirect to `/yahrzeit/`
- PHP PCRE JIT disabled to avoid executable-memory warnings in hardened
  environments
- local syntax, audit, and policy tests
- policy-derived cron entries owned by the appliance administrator
- 13 compressed weekly automation logs under `data/`
- interactive controller-address configuration
- preservation of calibrated normal and full-wall brightness values during an
  update
- preservation of `data/minhag.ini` and `data/yahrzeits-rev4.csv` during an
  update
- a narrow Apache systemd exception allowing writes to the application data
  directory and access to the cron helper's sudoers authorization

## Installation Locations

Repository:

```text
https://github.com/allanschwartz/yahrzeit
```

Default application directory:

```text
~/src/yahrzeit/yahrzeit_site-v3
```

Apache URL path:

```text
/yahrzeit/
```

## After Installation

Open the application:

```text
http://<appliance-ip>/yahrzeit/
```

Run the non-transmitting validation:

```sh
cd ~/src/yahrzeit/yahrzeit_site-v3
bin/yahrzeit --audit
bin/yahrzeit --dry-run
php tests/yahrzeit_engine_policy_test.php
```

Confirm `bin/yahrzeit-controller.conf` before any live controller test.

Review the managed cron block printed by the installer. Saving the Minhag page
also refreshes that block. To repair it manually:

```sh
sudo bin/fix-up-crontab
```

Review scheduled-operation history when needed:

```sh
tail -100 data/automation.log
ls -lh data/automation.log*
```

## See Also

- **Project**
  - [`./README.md`](../README.md)
- **Server**
  - [`./yahrzeit_site-v3/README.md`](README.md)
  - [`./yahrzeit_site-v3/INSTALL.md`](INSTALL.md)
- **Controller**
  - [`./embedded/yahrzeit_v3/README.md`](../embedded/yahrzeit_v3/README.md)
  - [`./embedded/yahrzeit_v3/INSTALL.md`](../embedded/yahrzeit_v3/INSTALL.md)
- **Hardware**
  - [`./Hardware/README.md`](../Hardware/README.md)

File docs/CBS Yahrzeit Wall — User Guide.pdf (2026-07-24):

Yahrzeit (http://localhost:8000/0yahrzeit.php) | Yizkor (http://localhost:8000/1yizkor.php) | Panels (http://localhost:8000/2panels.php) | Names (http://localhost:8000/4names.php) | Reports (http://localhost:8000/6reports.php) | Minhag (http://localhost:8000/7minhag.php) | User Guide (http://localhost:8000/8userguide.php)

Yahrzeit Wall User Guide
Operator guide for the Congregation Beth Sholom Yahrzeit Wall application.

Yahrzeit Wall User Guide

This guide explains the Congregation Beth Sholom Yahrzeit Wall web application at an operator level. It is intended for office staff, ritual committee members, and technical volunteers who maintain the memorial database, review reports, check wall assignments, or perform occasional manual wall operations.

What This Application Does

The Yahrzeit Wall application maintains the memorial-name database, applies Congregation Beth Sholom lighting policy, generates reports, audits memorial locations, and sends command streams to the embedded wall controller.

In normal operation, no one needs to manually light the wall each day. The scheduled automation decides when lighting should change and uses the same command path available from the web application and command line.

System Overview

The system has three main parts:

Yahrzeit Wall — the physical memorial wall, panels, names, and LEDs.
Yahrzeit web application — the PHP application that maintains data, reports, settings, and operator screens.
Embedded controller — the Arduino-based controller that receives commands and drives the LED wall.

The normal scheduled-control path is:

cron
-> bin/yahrzeit_scheduler
-> bin/yahrzeit
-> bin/yahrzeit_engine.php
-> controller command stream -> nc
-> Yahrzeit controller (Arduino)
In practical terms: cron decides when scheduled phases run, | yahrzeit_scheduler | decides whether the
requested phase applies today, | yahrzeit | decides how to run and transmit the action, and
yahrzeit_engine.php | decides what names should be lit, audited, or reported.

Normal Operation

Normal yahrzeit and Yizkor lighting is automatic. Cron runs a small number of named scheduler phases at the times saved on the Minhag page. Each scheduler phase either performs one action or does nothing.

7/23/26, 10:58 AM | CBS Yahrzeit Wall — User Guide
localhost:8000/8userguide.php | 1/9

11:00 AM | yahrzeit_scheduler --phase yizkor-on If today is a configured Yizkor day, turn on Yizkor lighting.
1:00 PM | yahrzeit_scheduler --phase yizkor-off If today is a configured Yizkor day, restore normal yahrzeit lighting.

Every evening at the configured fixed or sunset-relative time:
| yahrzeit_scheduler --phase yahrzeit

The application maintains its own marked block in the appliance crontab. Normal Yahrzeit lighting is reapplied every evening. Fixed times remain stable. Sunset-based times are recalculated automatically as sunset changes through the year.

The web application is mainly used for review, maintenance, reporting, auditing, and occasional manual operation. Routine daily lighting should not require manual web-page action.

Common Tasks

To find a memorial name, use the Names page. (http://localhost:8000/4names.php) To see where a person is assigned on the wall, open the memorial record (http://localhost:8000/5singlename.php) or view the relevant panel. (http://localhost:8000/3singlepanel.php)

To review upcoming Yahrzeit observances, use the Reports page. (http://localhost:8000/6reports.php) Day, week, next-week, month, and next-month reports list names whose yahrzeits fall in the selected period. The next enabled Yizkor dates are shown on the Yizkor page (http://localhost:8000/1yizkor.php) and in the Minhag preview. (http://localhost:8000/7minhag.php)

To check the integrity of the memorial database, use the Reports page (http://localhost:8000/6reports.php) to run the audit. The audit checks for unknown panel IDs, invalid row or column values, malformed records, and duplicate assignments to the same LED location.

To preview what would be sent to the controller, use the command preview on the Reports page. (http://localhost:8000/6reports.php) Preview does not transmit commands to the wall.

To replace the memorial database, use the CSV upload tool on the Reports page. (http://localhost:8000/6reports.php) The current CSV file is backed up before replacement, and an audit is run after upload.

To change synagogue-wide lighting policy, use the Minhag page. (http://localhost:8000/7minhag.php) These settings affect the entire wall and should match Congregation Beth Sholom practice.

Page-by-Page Guide

Each page has its own help link. The descriptions below explain what each page shows and when to use it.

Yahrzeit Wall Home (http://localhost:8000/0yahrzeit.php)

The Yahrzeit Home page provides an at-a-glance summary of the appliance and its current operating context. It shows the civil and Hebrew dates, the server and controller addresses, the next scheduled lighting event, and a summary of the saved lighting policy.

It also reports the number of configured panels and memorial records, and how many Yahrzeit lights should currently be lit. Use this page as the starting point when checking the system or confirming its configuration. Links in the summary lead to the appropriate maintenance pages.

See also Yahrzeit Wall Home Help. (http://localhost:8000/help/0yahrzeit.php)

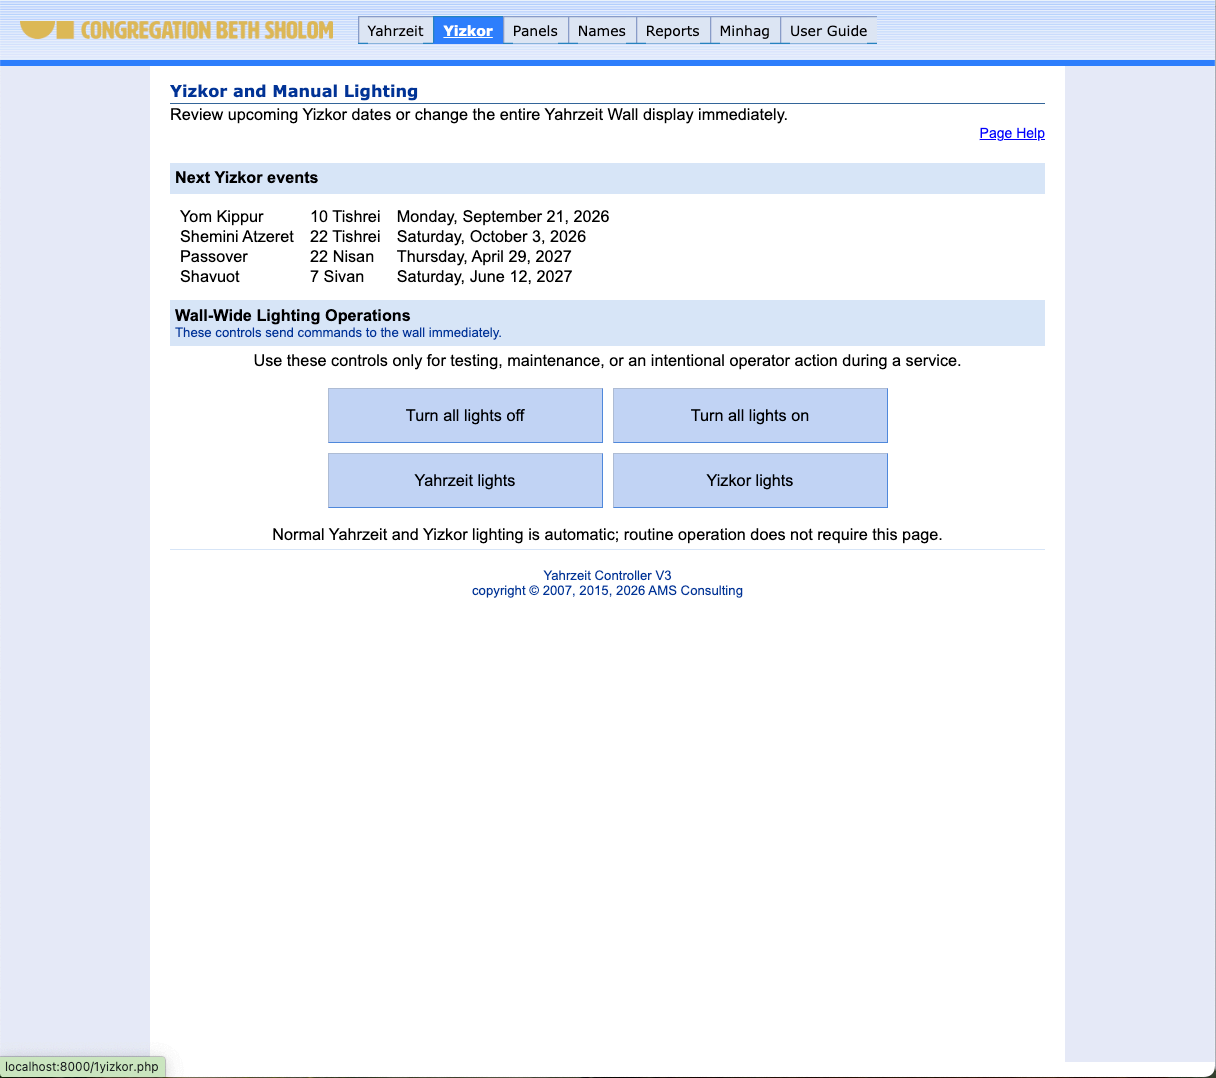
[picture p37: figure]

Yizkor and Manual Lighting (http://localhost:8000/1yizkor.php)

The Yizkor page lists the next enabled Yizkor observances, in upcoming date order. The dates reflect the Yom Kippur, Shemini Atzeret, Pesach, Shavuot, and optional additional observances selected on the Minhag page.

This page also provides immediate control of the complete Yahrzeit Wall. Turn all lights off and Turn all lights on are intended for testing and maintenance. Yahrzeit lights restores the normal date-based display, while Yizkor lights turns on the full-wall memorial display.

Normal Yahrzeit and Yizkor lighting is automatic, so these controls are not ordinarily needed. They may also be used for an intentional operator action during a service.

See also Yizkor and Manual Lighting Help. (http://localhost:8000/help/1yizkor.php)

View Yahrzeit Panels (http://localhost:8000/2panels.php)

The Panels page shows the physical layout of the Congregation Beth Sholom Yahrzeit Wall. Each glass panel in the photograph can be selected; click a panel in the photograph to open a detailed view of the memorial names assigned to it.

The table below the photograph provides another way to select a panel. It lists each panel ID, its row-and-column geometry, its total memorial capacity, and the number of LEDs that should currently be lit. Click a panel ID to open the
same detailed panel view.

Use this page to locate a panel, review the overall wall

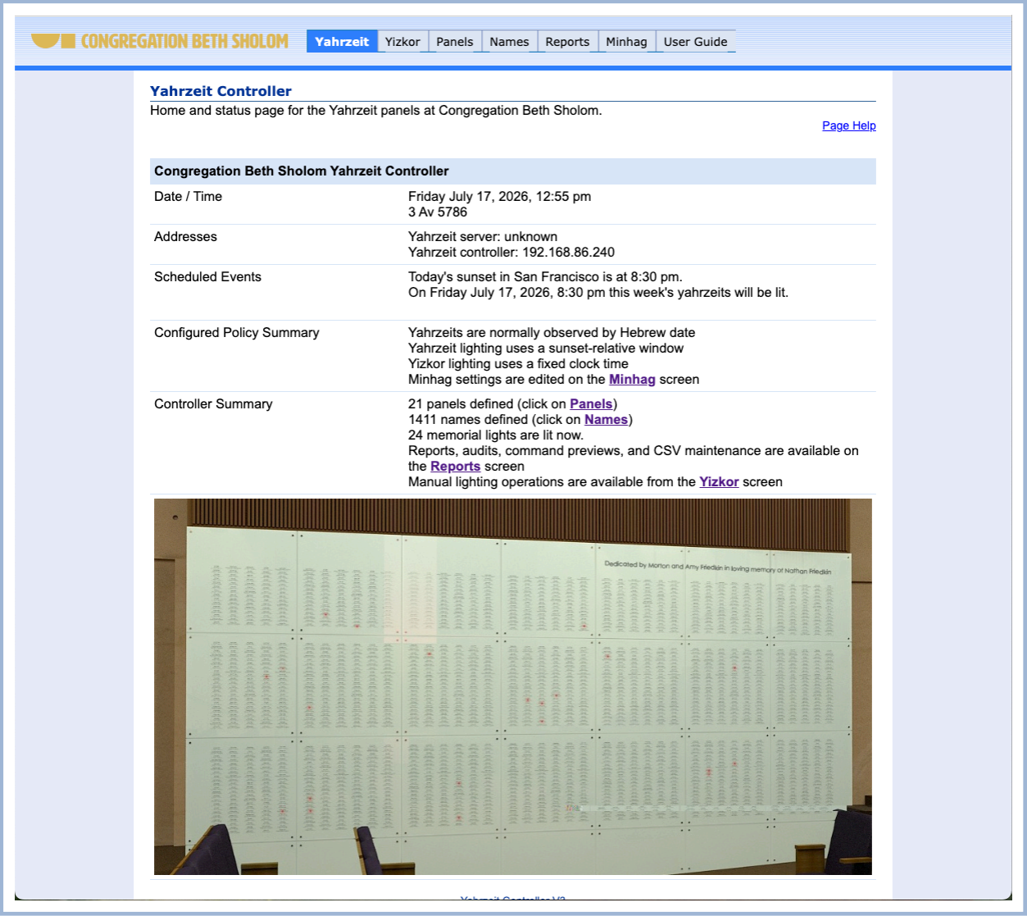
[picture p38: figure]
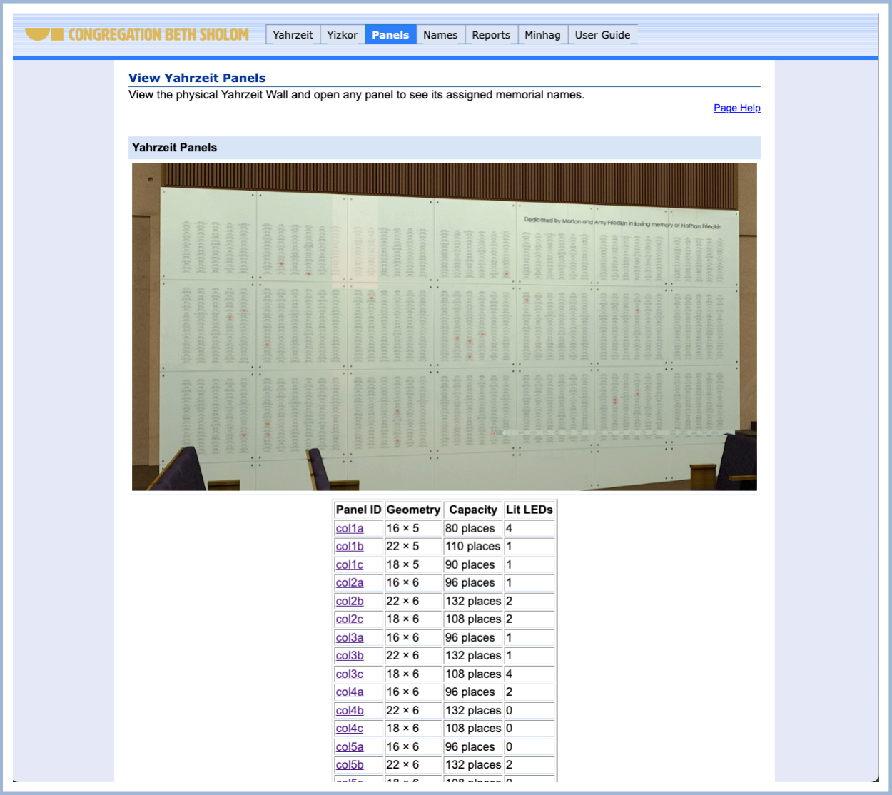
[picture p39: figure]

configuration, or begin checking database assignments against the physical wall. The panel geometry represents the installed wall and is not edited from this page.

See also View Yahrzeit Panels Help. (http://localhost:8000/help/2panels.php)

Single Yahrzeit Panel (http://localhost:8000/3singlepanel.php?panel=col1a)

The Single Panel page shows the memorial names assigned to one physical glass panel of the Congregation Beth Sholom Yahrzeit Wall. Its grid follows the installed rows and columns, so each screen position corresponds to one possible memorial-light position on the panel.

Occupied positions show the assigned memorial name and an LED symbol indicating whether that memorial light should currently be lit. Empty positions remain open. The summary below the grid gives the total number of memorial lights that
should be lit on the selected panel.

Use this view to compare database assignments with the

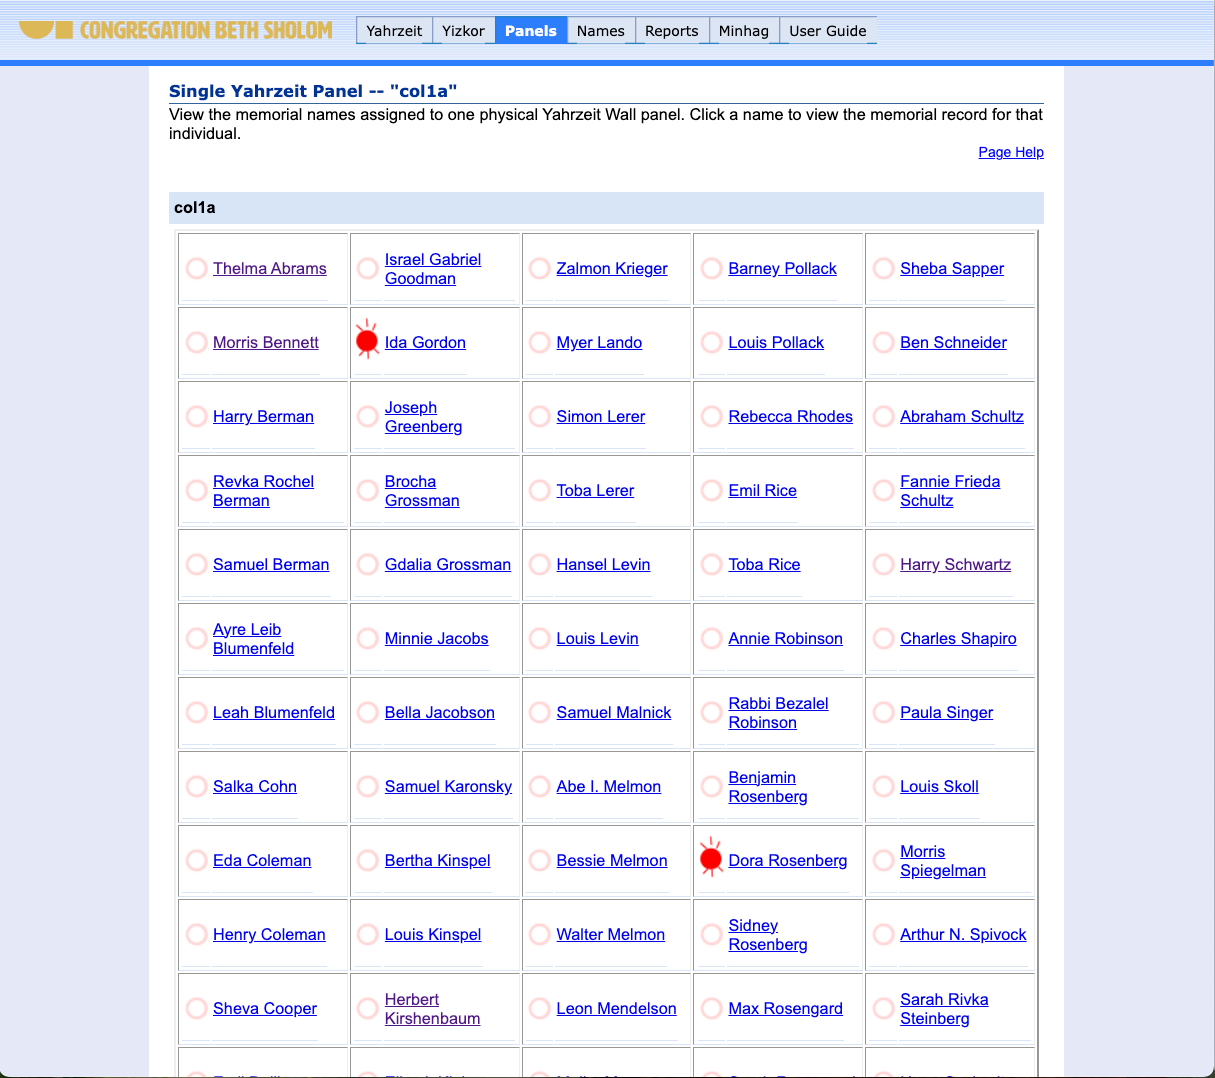
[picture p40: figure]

names etched on the physical glass panel. Click any memorial name to open that individual record for closer review or correction. If a position appears duplicated or invalid, run the database audit from the Reports page.

See also Single Panel Help. (http://localhost:8000/help/3singlepanel.php)

Yahrzeit Names (http://localhost:8000/4names.php)
The Names page is the main viewer for the memorial database. It lists all memorial records and provides a search field for finding people by name, English or Hebrew date, observance option, or panel location. Searching is not case-sensitive.

More than one search term may be entered. A record is displayed only when all the terms are found, even if they occur in different fields. For example, a surname may be combined with a year, Hebrew month, or panel ID to narrow
the results. Select Clear to display all memorial records
again.

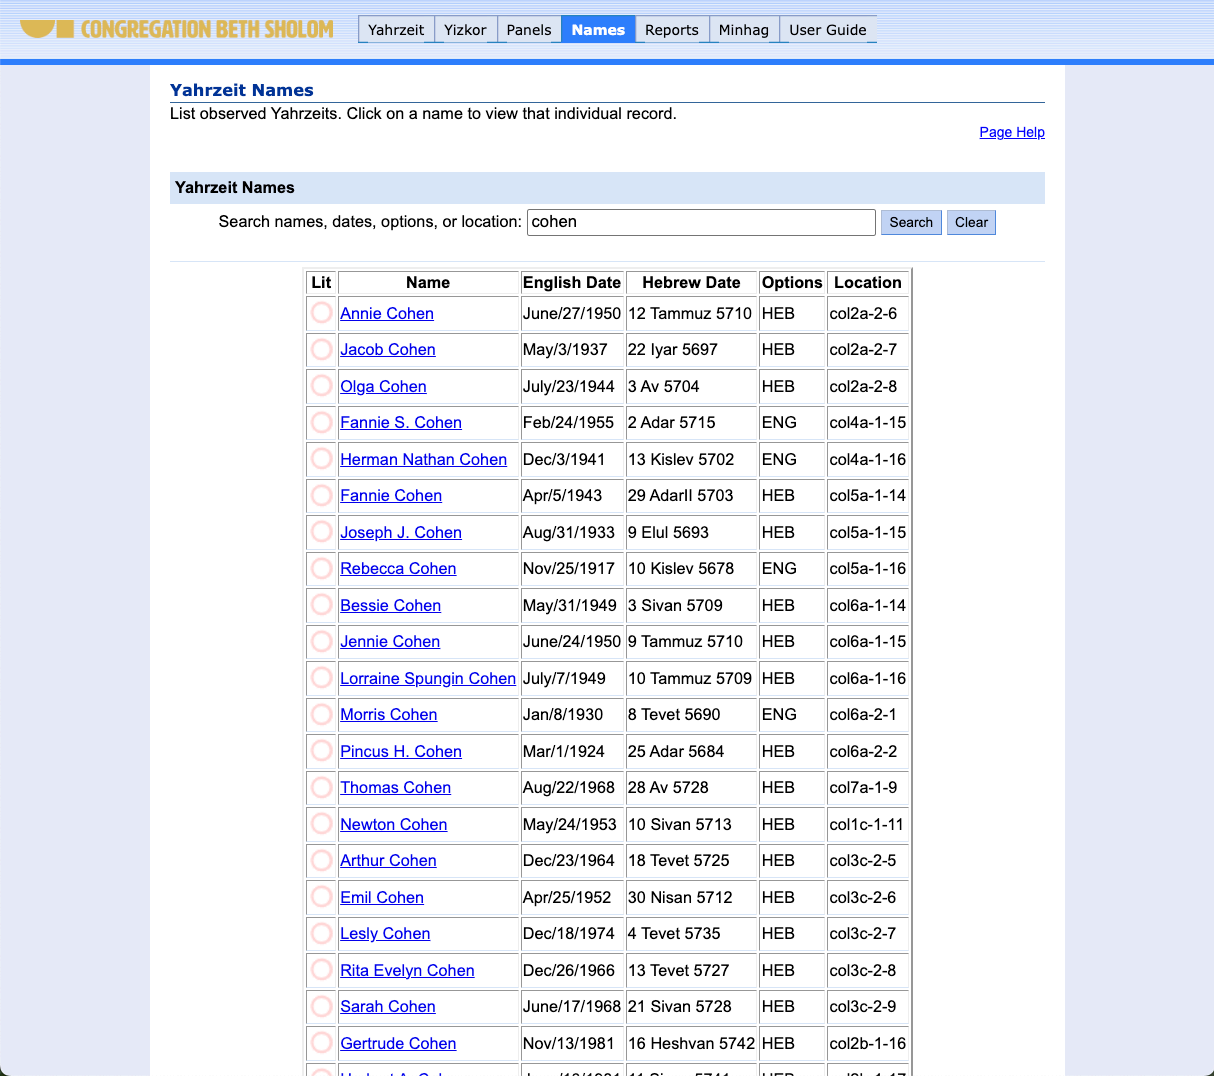
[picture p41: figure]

Each result shows the memorial name, stored English and Hebrew dates, special observance options, and assigned panel location. The Lit symbol indicates whether the memorial light should currently be lit. Click a person's name to open the individual memorial record for review or correction.

New memorial names have historically been added in batches, rather than one at a time from this page. Use the Reports page (http://localhost:8000/6reports.php) to download the current CSV database, edit the downloaded file while preserving its CSV format, and upload the replacement file. Records are removed through the same controlled CSV-replacement process. The upload operation first backs up the current database and then audits the replacement.

See also View Names Help. (http://localhost:8000/help/4names.php)

Single Yahrzeit Name (http://localhost:8000/5singlename.php?row=0)

The Single Name page displays one individual memorial record and permits careful corrections to that record. It shows the person's name, stored English and Hebrew dates, and the panel, column, and row assigned to the memorial light.

The observance choices specify whether the family follows the English or Hebrew Yahrzeit date and whether additional memorial observances apply. A normal record uses automatic, calendar-driven lighting. A location reserved for future use may instead be marked Reserved, which keeps its light off.

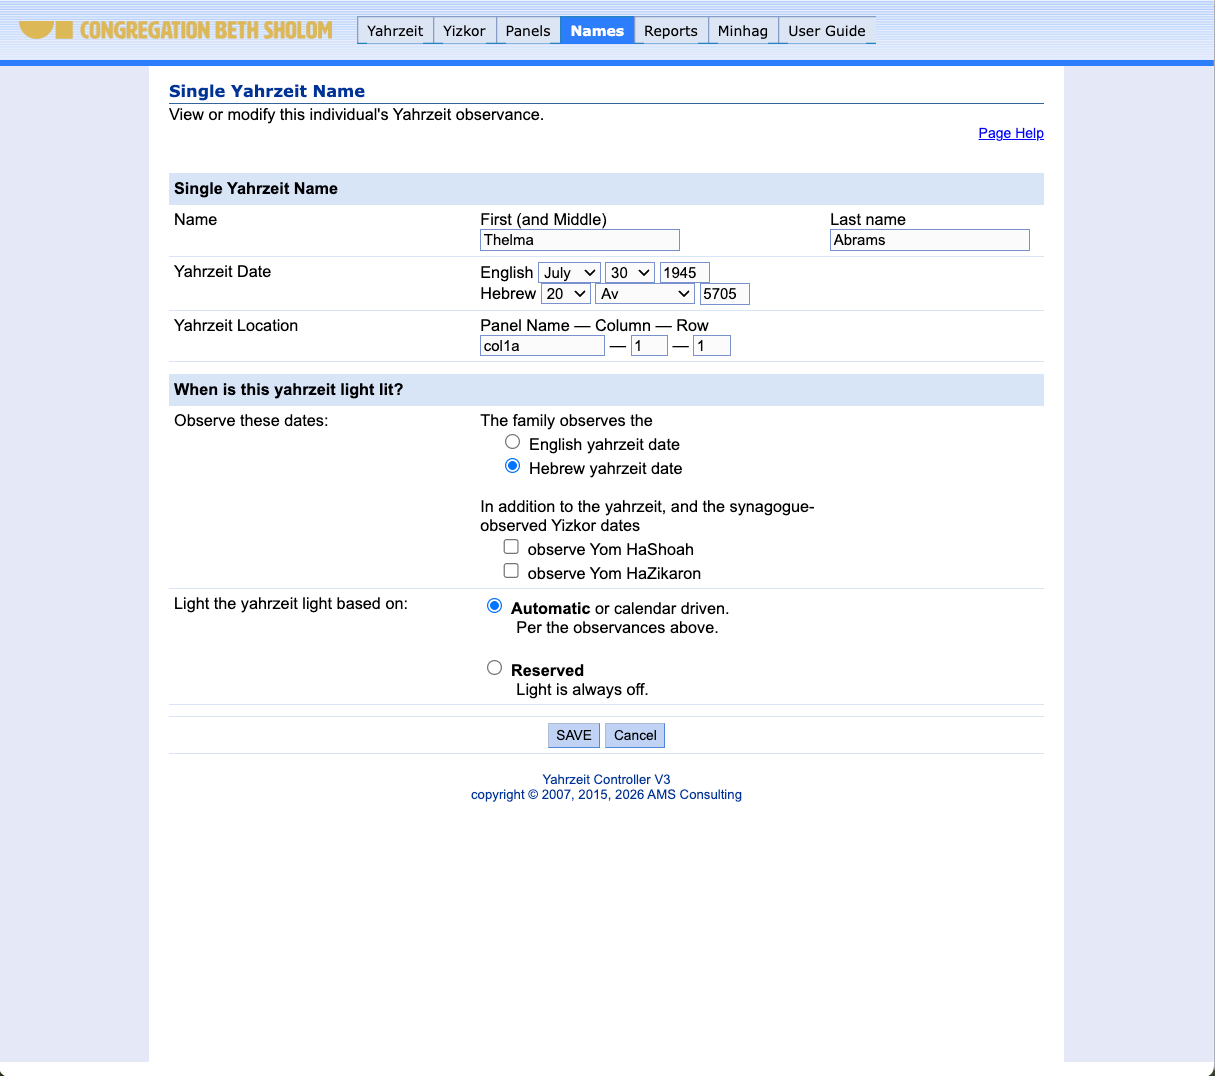
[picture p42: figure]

Use this page for individual corrections, such as fixing a name, date, or panel location. After selecting Save, the application backs up the current memorial database, replaces only the selected record, and automatically runs the database audit. Review any reported audit problem before making another change.

See also Memorial Record Help. (http://localhost:8000/help/5singlename.php)

Yahrzeit Reports (http://localhost:8000/6reports.php)
The Reports page generates lists of memorial names whose Yahrzeits fall on a selected day, during this or next week, or during this or next month. The anchor date determines which day, week, or month is selected.

Week reports use the Erev Shabbat-to-Erev Shabbat observance period. The displayed civil dates run from Saturday through Friday. When the anchor date is Friday, This week begins that evening, while Next week begins the following Friday evening.

The diagnostic tools check the relationship between the
memorial database and the physical wall. Audit Database

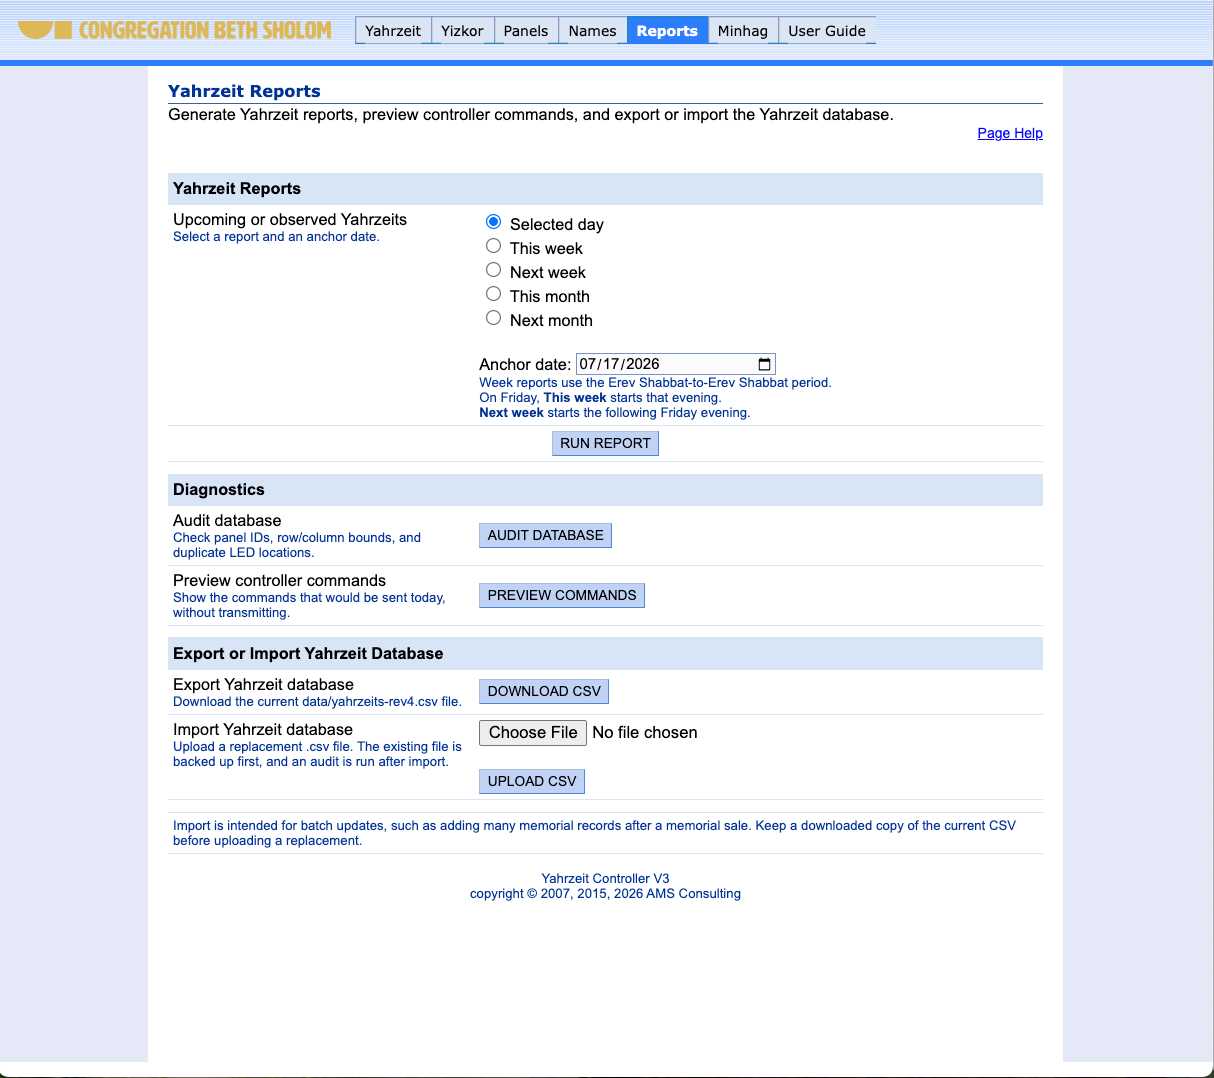
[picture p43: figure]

reports invalid panel IDs, row or column values outside the panel geometry, malformed records, and duplicate LED assignments. Preview Commands shows the controller commands that would be generated today without transmitting them to the wall.

The Reports page also maintains the complete CSV memorial database. Download CSV saves a copy outside the appliance. Upload CSV installs a replacement database for batch maintenance. Before replacement, the current database is backed up; after replacement, the new database is automatically audited.

Example — Next Week: With Friday, July 17, 2026 as the anchor date, this report selects the following observance week: Saturday, July 25 through Friday, July 31. Each row gives the observance date, memorial name, Hebrew and English dates, wall location, and date option.

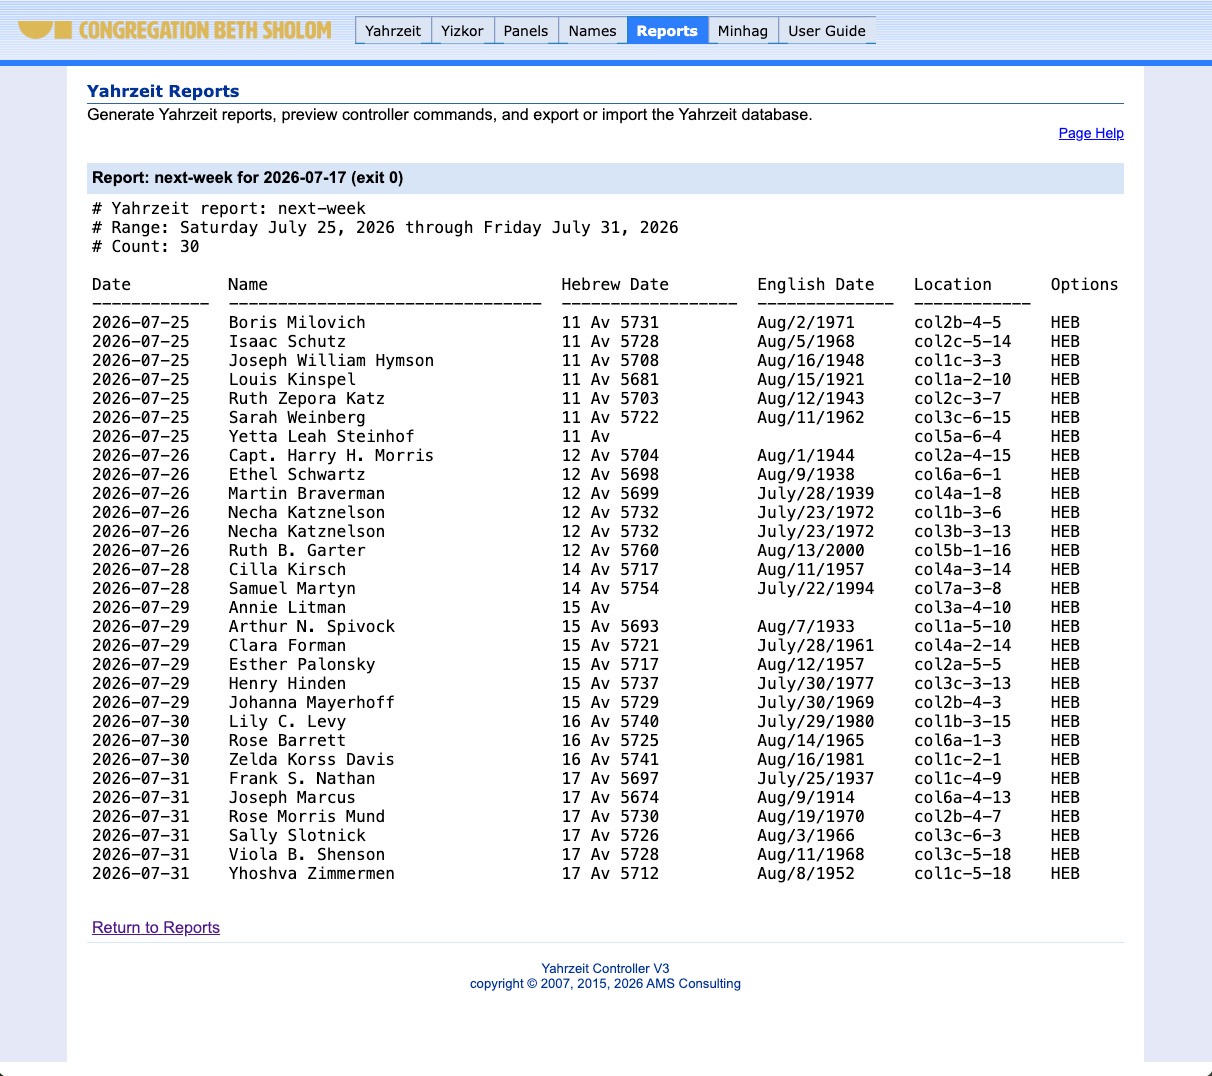
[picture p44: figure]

See also Reports Help. (http://localhost:8000/help/6reports.php)

Yahrzeit Minhag (http://localhost:8000/7minhag.php)
The Minhag page records synagogue-wide Yahrzeit and Yizkor practices. It also stores the synagogue name and affiliation displayed by the application. Because these settings affect the entire wall, they should be changed only when the intended synagogue practice is understood.

The Yahrzeit settings choose whether regular observances follow the English or Hebrew date, whether lighting changes at a fixed time or a selected number of minutes before sunset, and whether each Yahrzeit is observed for its day
only or for the full Erev Shabbat-to-Erev Shabbat week.

The Yizkor settings enable the four annual Yizkor

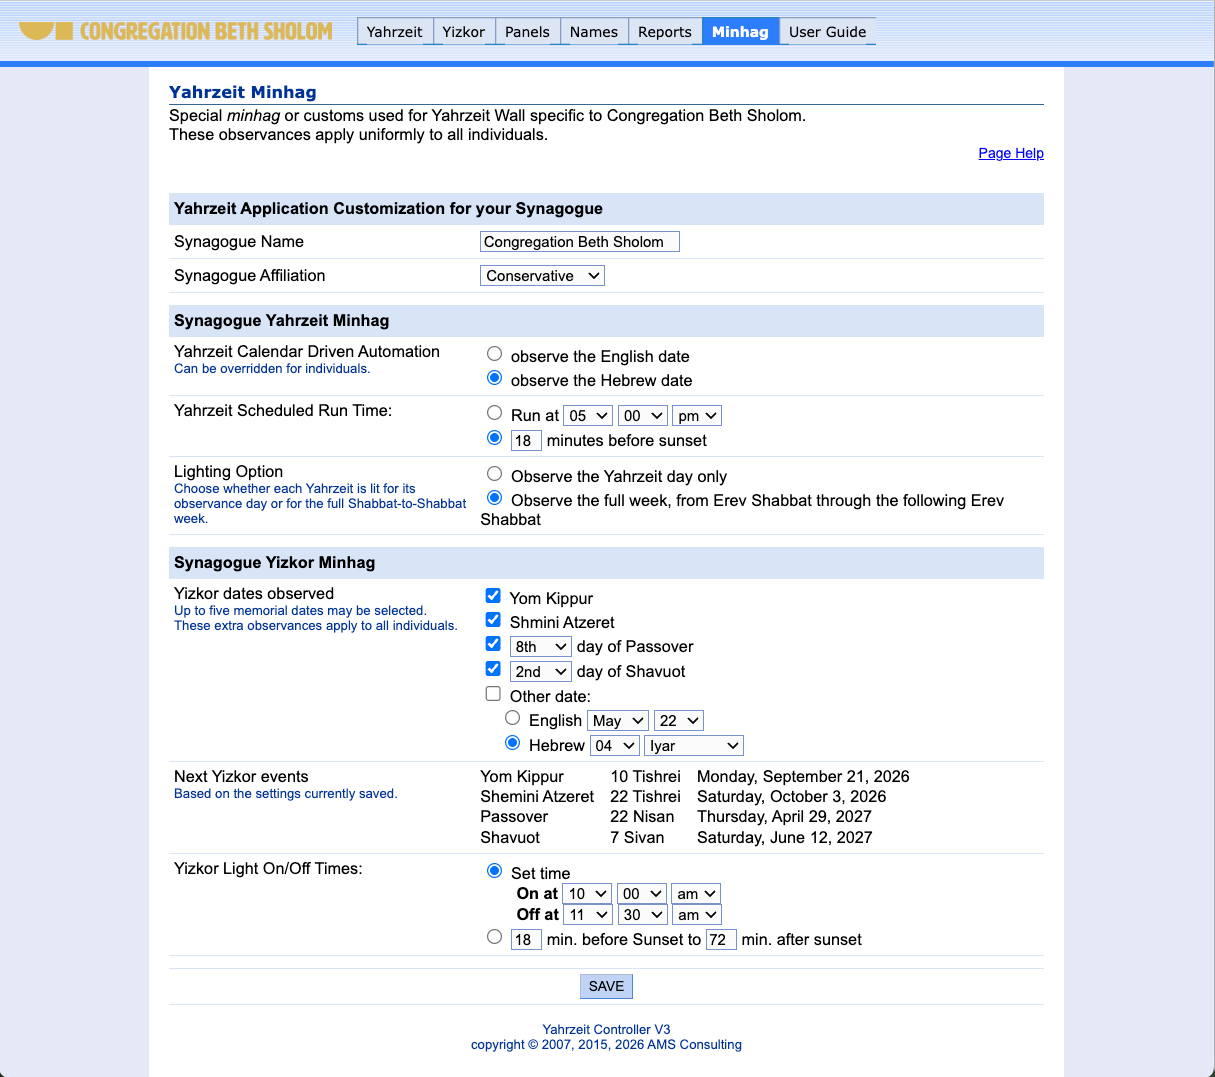
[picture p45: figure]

observances and select the appropriate Pesach and Shavuot days. An optional additional Hebrew date may be configured for another full-wall memorial observance. The preview lists the next civil date of every currently saved observance. Yizkor on/off times may use fixed clock times or a window around sunset.

Selecting Save writes the revised settings and regenerates the appliance's managed lighting schedule. The result page displays the installed schedule or reports that schedule installation failed. After changing observance dates or lighting times, review the preview and resulting schedule before relying on automatic operation.

See also Minhag Settings Help. (http://localhost:8000/help/7minhag.php)

Safety Notes

Some operations affect the live wall or the live database. Use extra care with these actions:

Manual wall-wide lighting controls send commands to the controller immediately.
CSV upload replaces the live memorial database.
Minhag changes affect scheduling and lighting policy for the whole wall.

After changing memorial data, run the audit before relying on scheduled lighting. After changing Yizkor or timing settings, review reports or previews as appropriate to confirm the intended behavior.

Manual Wall Operations

The Yizkor page provides manual wall-wide operations: all on, all off, the normal Yahrzeit display, and full-wall Yizkor lighting. These controls are useful for testing, maintenance, or special operator action. They are not normally required for daily scheduled operation.

Manual restoration may be useful after testing, maintenance, a power interruption, or an incorrect wall display. After using Turn all lights on, Turn all lights off, or Yizkor lights, select Yahrzeit lights to recalculate and restore the normal date-based lighting pattern.

Because these controls act immediately, use them only when intentionally changing the current wall display. See the Yizkor page (http://localhost:8000/1yizkor.php) for these operations.

Database and Files

The live memorial database is stored as a CSV file:

data/yahrzeits-rev4.csv

The synagogue lighting-policy settings are stored in:

data/minhag.ini

Normal web pages read these files through the application include files rather than parsing them directly. The Reports page provides the safest web path for CSV download, upload, audit, and preview.

Modifying the Memorial Database

Correcting one memorial record:

1. Open the Names page (http://localhost:8000/4names.php) and locate the memorial using the search field.
2. Select the person's name, make the required correction on the Single Yahrzeit Name page, and select Save.
3. Review the audit result shown after the record is saved. The application creates a timestamped backup before replacing the record.

4. Open the affected Single Panel page and compare the displayed name and position carefully with the actual etched-glass panel.

Adding records or making batch changes:

1. On the Reports page, (http://localhost:8000/6reports.php) select Download CSV and retain the downloaded file as a backup.
2. Make the required changes to a working copy of the CSV file. Preserve the existing columns, field meanings, and panel-location format.
3. Select Upload CSV and choose the corrected file.
4. Review the audit results displayed after the upload. If errors are reported, correct the working copy and upload it again.
5. Review every affected panel on the Single Panel page and compare it with the corresponding etched-glass panel.

The server backs up the existing live database before installing an uploaded replacement. That local backup does not replace the external downloaded copy described below.

Backup

Use Download CSV on the Reports page to save a copy of the current memorial database. Make a backup after significant database changes and before performing a batch update. Add the date to the downloaded filename and keep the copy somewhere other than on the Yahrzeit appliance.

The application also makes a timestamped local backup before replacing the database during an upload. These local copies provide protection against an incorrect upload, but they do not replace an off-appliance backup that remains available if the appliance or its storage fails.

Restore

To restore the memorial database, use Choose File on the Reports page to select a known-good backup, and then select Upload CSV. The application backs up the current database before replacing it and automatically audits the restored database.

Review the audit results before relying on reports or scheduled lighting. If the audit reports errors, correct the CSV file or restore a different backup and upload it again.

Maintenance

The Yahrzeit Wall requires little routine physical maintenance. While the wall is operating correctly, no internal maintenance of the LED boards, interconnect cables, or controller is recommended.

Routine maintenance consists primarily of:

Keeping the Yahrzeit appliance, Yahrzeit Controller, and wall power supplies continuously powered and connected to the wired network.
Maintaining a recent external copy of the memorial database.
Reviewing the Home page and | data/automation.log | after an appliance replacement, operating-
system update, network change, or power interruption.
Testing the Yizkor pattern before a Yizkor observance. Confirm that the complete wall illuminates, and then select Yahrzeit lights to restore the normal display.

The appliance calculates the Yahrzeit and Yizkor dates automatically. The schedule does not require annual entry of calendar dates.

Technical Overview

The web application and embedded controller are intentionally layered. On the site side, the scheduler decides when to act, the wrapper decides how to run and transmit, and the engine decides what names should be lit or reported.

On the embedded controller side, the network or serial input code collects command lines, the command processor parses them, the wall abstraction applies logical row/column/panel operations, and the low-level pixel driver updates the hardware.

socket_thread / serial_thread
-> CmdProc
-> LedWall
-> YyzPixel

Troubleshooting

If the wall does not display the expected pattern, check the system in this order:

1. Confirm power to the Yahrzeit appliance, Yahrzeit Controller, and wall power supplies.
2. Confirm that the appliance and controller are connected to the synagogue Ethernet network.
3. Open the browser interface. Review the Home page, the expected lighting pattern, the memorial database, and the Minhag settings.
4. Run the database audit from the Reports page and review data/automation.log .
5. Have a technical administrator verify communication between the appliance and the Yahrzeit Controller.

If only one LED or a localized group of LEDs fails while the rest of the wall operates normally, the likely cause is a physical LED, pixel-board, or interconnect-cable fault. Investigate the physical wall only after power, software, database, and controller communication have been verified.

If a report looks wrong, confirm its anchor date and check the Minhag settings that control the date method and observance period. If a name appears in the wrong wall position, run the database audit, correct the memorial record or CSV database, and audit again.

When in Doubt

For ordinary review, use Names, Panels, and Reports. For live-wall changes, CSV upload, or Minhag changes, proceed deliberately and run audit or preview checks afterward.

Yahrzeit Controller V3
copyright © 2007, 2015, 2026 AMS Consulting

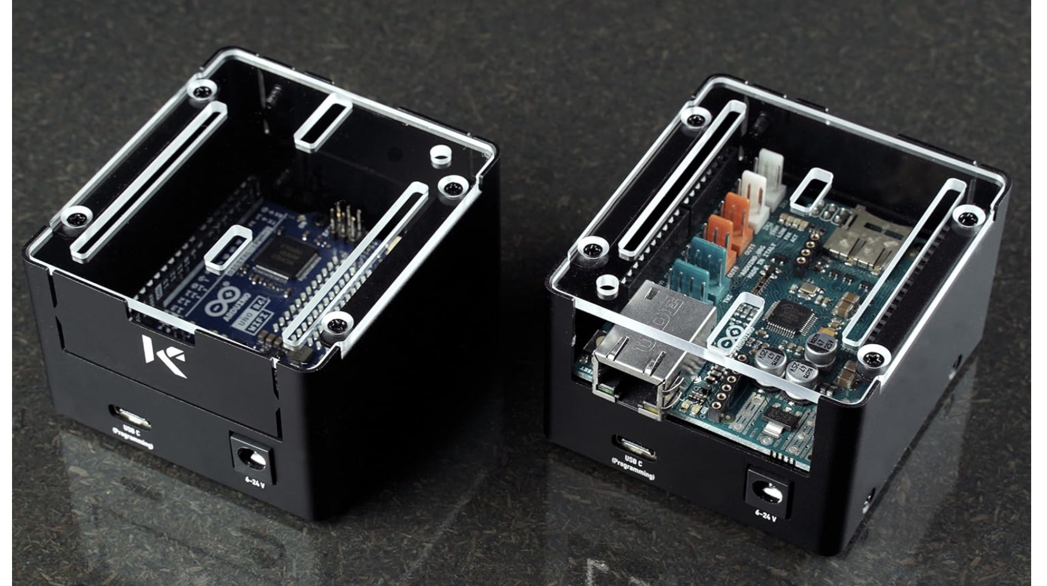
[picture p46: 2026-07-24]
Hardware/3D Printing/arduino_uno_r4_commercial_enclosure_vendor.jpg

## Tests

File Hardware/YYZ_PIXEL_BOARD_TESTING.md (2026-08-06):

# YYZ Pixel Board Bench Testing

<a href="images/yyz_pixel_bench_test_setup.jpg">
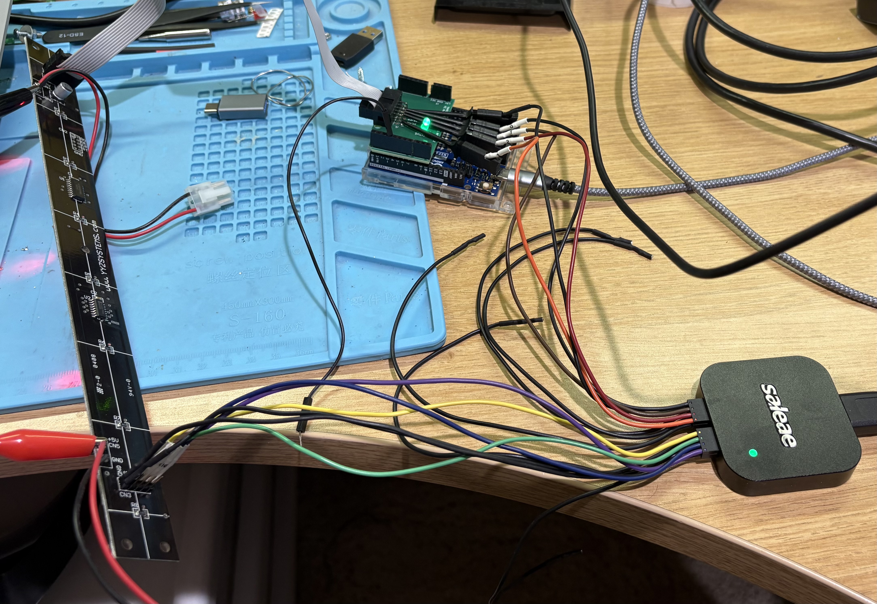
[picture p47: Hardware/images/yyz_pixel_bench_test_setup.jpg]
Complete YYZ Pixel board bench-testing setup
  
</a>

*Complete single-board test setup: YYZ Pixel board, Arduino controller with
Pixel Interface V3, current-limited bench power, and Saleae logic analyzer.*

This is the engineering procedure for testing one removed YYZ Pixel board with
the Arduino controller, Pixel Interface V3, a current-limited 5V power supply, and
optionally a Saleae logic analyzer. It complements the customer-facing
[board-replacement guide](YYZ_PIXEL_BOARD_REPAIR.md), which deliberately does
not require firmware installation, bench instrumentation, or electronic
rework skills.

YYZ Pixel boards exist in 6-, 8-, and 10-pixel versions. You will be setting the controller's runtime geometry to the exact physical size of the board-under-test.

## Essential equipment

- Arduino controller with the current `yahrzeit_v3` firmware
- Pixel Interface V3 and its controller-to-first-board ribbon cable
- Regulated, current-limited 5V bench power supply
- Known-good power and data cables
- Known-good YYZ Pixel board for comparison
- Multimeter
- Saleae Logic 8 or Logic Pro 8, (or equivalent) strongly recommended
- Insulated probes or micro-grabbers as needed

The current-limited supply is mandatory. An accidental +5V-to-ground short is
easy to make on this fixture; current limiting protects the board and test
equipment when that happens. Set 5.0 V and use a conservative current limit
for example 0.5 A.

## Critical controller-cable modification

> **The direct controller-to-first-board ribbon cable is special. One
> conductor must be cut. Do not substitute an ordinary unmodified
> board-to-board ribbon cable.**

The original YYZ Pixel design used one conductor of the nominal `DI` pair as `D*`, the serial-data return path for the original column-to-column wiring. That return scheme was later abandoned in favor of long ribbon cables. The Pixel Interface V3 drives both conductors of this pair as `DI`; consequently, an unmodified cable ties `DI` to the board’s `D*` output. Cutting the `D*` conductor removes that conflict while leaving the other `DI` conductor connected.

The original 2008 schematic records the field modification as:

> If CN1 connects to the controller's port, cut wire number 10.

There is no reliable pin-1 indicator on these cables, and some installed cables
were reversed because of connector-key orientation. Therefore, do not identify
the conductor by the red stripe, connector key, or physical left/right position
alone.

With all power disconnected, identify the two ribbon cable conductors forming the DI pair at the Pixel Interface V3 end. Cut the outside-edge member of that pair—the conductor that reaches D* at CN1. Bend the cut conductor back so that it cannot make contact, and label the cable:

```text
PIXEL I/F -> FIRST YYZ PIXEL
```

## Connect the board

<a href="images/pixel_interface_saleae_micrograbbers.jpg">
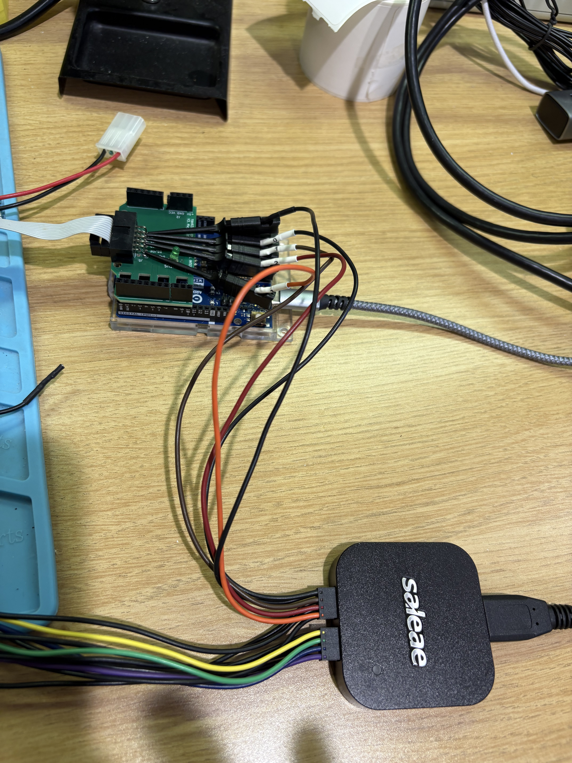
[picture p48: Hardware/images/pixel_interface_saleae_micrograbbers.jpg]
Saleae micro-grabbers connected to Pixel Interface V3
  
</a>

*Micro-grabbers provide convenient access to `DI`, `OE`, `CP`, and `ST` at the
Pixel Interface V3 90° signal connector.*

1. Turn off the bench supply and disconnect its output.
2. Set the supply to 5.0 V with current limiting enabled; for example, use a
   0.5 A current limit.
3. Prepare a keyed Molex power harness that mates with the power connector at
   the top of the board, adjacent to capacitor C3. Power this harness from the
   current-limited bench supply.
4. As you seat the connector, visually trace the harness wires and double-check that +5V aligns with +5V and GND aligns with GND on the board connector.
6. Connect Pixel Interface V3 to the board's CN1 using the specially modified
   controller cable described above.
7. Verify the orientation of the unkeyed data connector: `GND` must connect
   to `GND`, and `DATA` must connect to `DI`. Use the ribbon cable's red stripe
   only to trace the same edge from the Pixel I/F shield to the
   board-under-test; the stripe does not inherently identify either signal.
8. Inspect for adjacent pins bridged by probes or exposed conductors.
9. Enable the bench supply while watching its current indication. Switch it
   off immediately if it enters current limit unexpectedly.

## Configure the controller

At the serial console, select the board's physical size. Use exactly one of:

```text
geometry 6
geometry 8
geometry 10
```

The column count defaults to one. Confirm the result:

```text
status
```

For maximum steady brightness during basic tests:

```text
bright 0
```

Brightness is implemented through active-low OE pulse-width-modulation (PWM) brightness control, so `0` means fully enabled/bright and `255` means fully disabled.

## Functional tests

Run the tests individually and observe the board after each one:

```text
test 1
test 2
test 3
test 4
test 5
```

| Command | Expected result | Primary use |
|---|---|---|
| `test 1` | Corner/end pixels | Address-range and orientation check |
| `test 2` | All pixels on | Finds dead outputs and power faults |
| `test 3` | All pixels off | Finds stuck-on outputs and leakage |
| `test 4` | Alternating checkerboard | Finds adjacent-bit and data-order faults |
| `test 5` | One row/pixel position at a time | Identifies a particular failed channel |

Use `dump` to confirm the logical framebuffer independently of the physical
LEDs. `refresh` retransmits and latches the framebuffer without changing it.

## Expected 74HC595 timing

The board uses `DI` as 74HC595 serial data, `CP` as the shift-register clock,
`ST` as the storage-register latch clock, and active-low `OE` as output enable.

During `refresh`:

1. `OE` goes HIGH to blank the LEDs.
2. Data is made stable before each rising edge of `CP`.
3. One `CP` pulse is generated per active pixel position.
4. After the final bit, `ST` receives one rising pulse to transfer the shift
   register into the output/storage register.
5. OE returns to its configured PWM brightness behavior.

The 74HC595 samples serial data on the **rising edge of CP**. The firmware
shifts rows in descending order and electrically inverts logical pixels for
the board's active-low LED wiring. Consequently, the DI pattern observed on a
logic analyzer may look reversed and inverted relative to the row order shown
by `dump`; this is expected.

## Saleae eight-channel comparison

The accessible CN1 and CN3 connectors make it possible to compare signals on
both sides of the board without probing fine-pitch IC pins.

| Saleae channel | Test point |
|---|---|
| D0 | CN1 `ST` input |
| D1 | CN1 `CP` input |
| D2 | CN1 `OE` input |
| D3 | CN1 `DI` input |
| D4 | CN3 `ST-tick` output |
| D5 | CN3 `CP-tick` output |
| D6 | CN3 `OE-tick` output |
| D7 | CN3 `DO` serial-data output |

The `-tick` spelling is used in Saleae channel labels as a visible substitute
for the schematic's prime mark.

<a href="images/saleae_single_pixel_refresh.png">
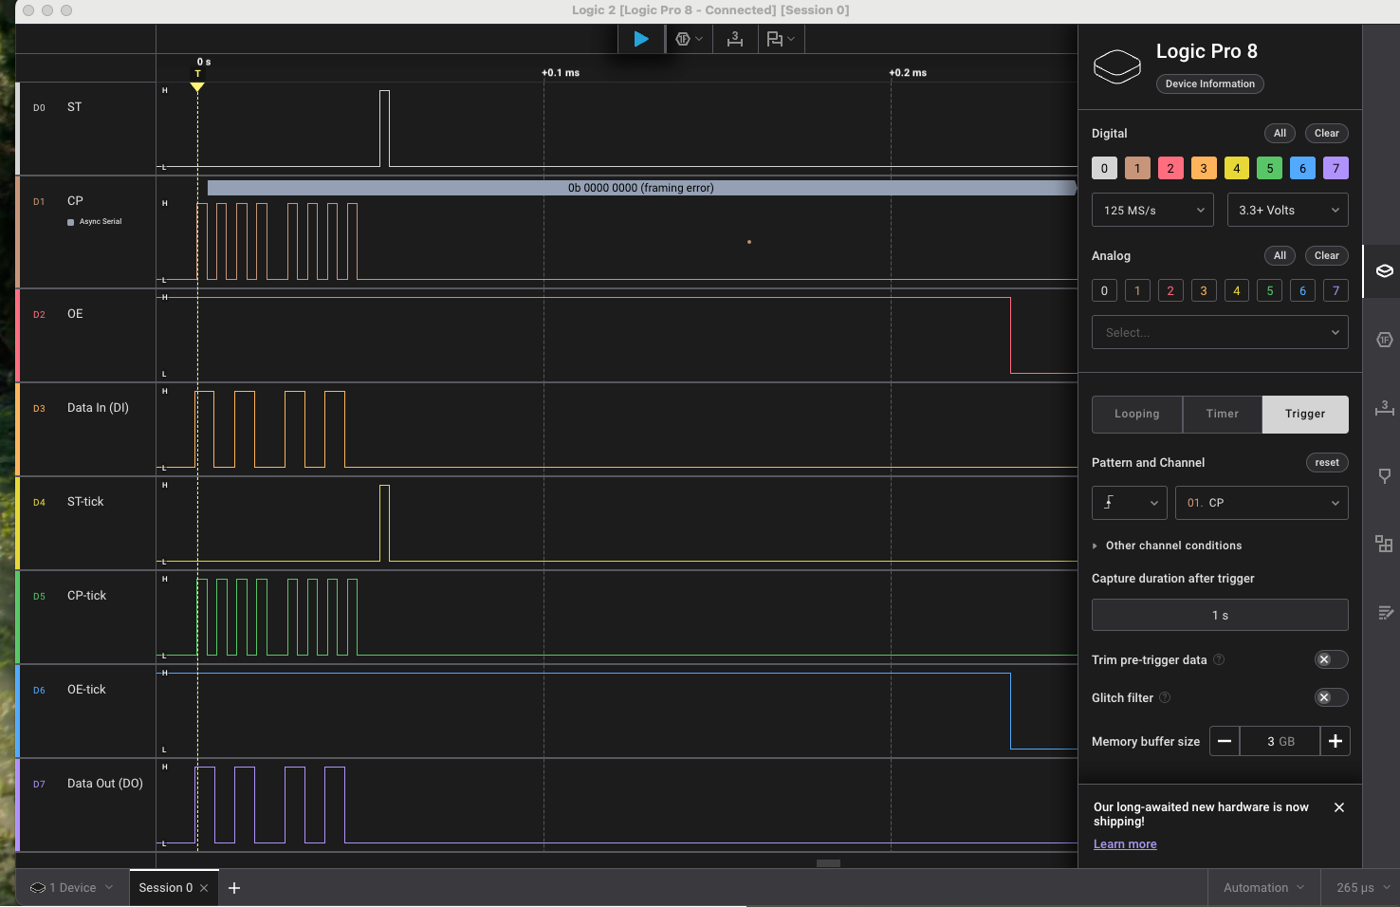
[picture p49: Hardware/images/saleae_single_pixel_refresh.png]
Saleae capture comparing CN1 and CN3 during a single-board refresh
  
</a>

*Eight-channel diagnostic capture that led to discovery of the pin-10 cable
problem. ST, CP, and OE are reproduced through the 74HC245, and DO shows serial
data leaving the 74HC595. In this capture, the extra Saleae ground connections
were temporarily altering the faulty return path; the waveforms remain a useful
timing reference.*

In Saleae Logic 2:

1. Select **Trigger** capture mode.
2. Select D1/CP as the trigger channel.
3. Select the rising-edge trigger symbol.
4. Leave other channel conditions unconstrained.
5. Start the capture, then issue `refresh` at the Arduino Monitor.

The display may stream while Saleae fills its pre-trigger buffer. It freezes
the requested capture after the trigger occurs. An accidentally installed
Async Serial analyzer on CP will report framing errors; those annotations are
irrelevant and may be ignored or the analyzer removed.

### Interpreting the paired signals

- `ST-tick`, `CP-tick`, and `OE-tick` should exactly reproduce their CN1
  inputs. Only the 74HC245 propagation delay separates them.
- DO is **not** a buffered copy of DI. It is the bit shifted out of the far end
  of the 74HC595 and therefore represents the register's previous contents.
- If the same repeating checkerboard is refreshed twice, DI and DO can appear
  identical because the old and new register contents are identical.

To demonstrate the distinction, first run `test 3`. Arm Saleae, then run
`test 4`. DI will contain the new alternating pattern while DO initially
contains the previous all-off pattern. A later unchanged `refresh` may make
them overlay again.

## Fault isolation

| Observation | Likely area |
|---|---|
| No input signals at CN1 | Controller, Pixel Interface, or controller cable |
| Input signals present but paired `-tick` signal missing | 74HC245, its power, solder joint, or PCB trace |
| CP/ST/OE reproduce correctly but DO never shifts | 74HC595 shift section, its power, solder joint, or data path |
| Correct shifting and latch, but board remains blank with OE LOW | 74HC595 output section, LED power, or output circuitry |
| Board works only when extra analyzer grounds are attached | Stop and inspect cable pin 10/`D*`, true ground continuity, and cable orientation |
| One LED alone fails | That LED, its resistor, solder joints, trace, or corresponding 74HC595 output |
| Board and downstream boards fail | Incoming cable, power/ground, buffer, or serial-chain path |

Do not infer that a board is bad until it has been tested with the correctly
modified controller cable and known-good power/data connections. The pin-10
ground conflict can imitate a board failure while all four controller-side
logic signals appear reasonable.

## Test record

| Date | Board size/ID | Cable pin 10 open | Tests 1-5 | Saleae result | Disposition |
|---|---|---|---|---|---|
|  | 6 / 8 / 10 |  |  |  |  |
|  | 6 / 8 / 10 |  |  |  |  |
|  | 6 / 8 / 10 |  |  |  |  |
|  | 6 / 8 / 10 |  |  |  |  |

## References

- [Original YYZ Pixel schematic](schematics/Schematic_yyz_pixel.pdf)
- [Pixel Interface V3 schematic](pixel_interface_v3/pixel_interface_v3-schematic.png)
- [Controller commands and firmware behavior](../embedded/yahrzeit_v3/README.md)
- [74HC/HCT245 data sheet](schematics/74HC_HCT245.pdf)
- [74HC/HCT595 data sheet](schematics/74HC_HCT595.pdf)

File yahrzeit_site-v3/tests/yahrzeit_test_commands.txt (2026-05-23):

# yahrzeit command-stream smoke test
# Purpose:
#   Short enough to inspect by eye.
#   Long enough to exercise parser, panel addressing, refresh, save, and timing echoes.
#
# Expected visible behavior on test fixture:
#   1. Clear display.
#   2. Light a small diagonal-ish pattern on panel 1.
#   3. Refresh and save.
#   4. Turn one pixel off.
#   5. Refresh and save again.
#   6. Print controller status.
#
# Safe for test fixture. For the real wall, this will modify saved display state.

version
status

all off
refresh

pixel on 1 1 1
pixel on 2 2 1
pixel on 3 3 1
pixel on 4 1 1
pixel on 5 2 1
pixel on 6 3 1
refresh
save

pixel off 3 3 1
refresh
save

status

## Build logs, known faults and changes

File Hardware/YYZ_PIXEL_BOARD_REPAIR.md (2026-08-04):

# YYZ Pixel Board Replacement Guide

<a href="images/wall_section_tilted_out.jpeg">
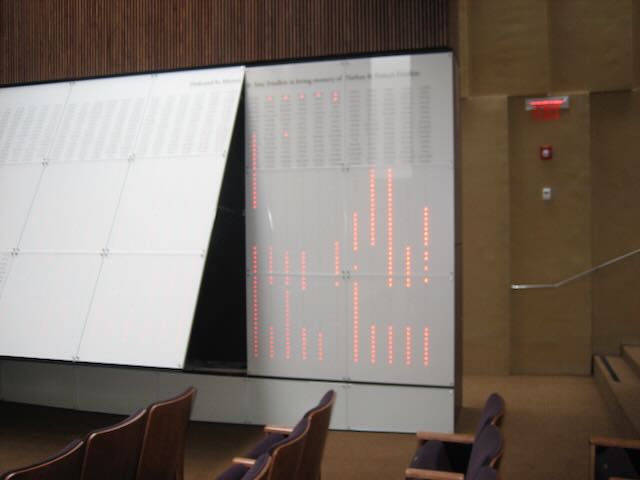
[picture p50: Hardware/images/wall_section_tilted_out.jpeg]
A Yahrzeit Wall section tilted outward for service
  
</a>

*A complete wall section tilts outward to provide access for service.*

This guide describes how the customer identifies a failed board and replaces
it with a tested spare. It does not cover component-level diagnosis or repair
of the removed board.

The wall contains approximately 280 pixel boards. Three boards have required
attention after about 20 years of service: `3 / 280 = 1.07%` of the installed
population. That is a very good service record. The 1.07% figure is the
observed fraction of boards needing attention, not an annual failure rate.

## Safety and handling

- A wall section must be tilted out to reach its rear. Secure it with the
  dedicated 3- or 4-foot wooden service prop before anyone works behind it.
  Position the prop as demonstrated and make sure that it cannot slip. Do not
  rely on a person to hold the section open. Retain the prop for future board replacements.
- Switch off the Yahrzeit Wall using the labeled power switch on the other side
  of the wall, in the synagogue book lobby, before connecting, disconnecting,
  or reseating any pixel board or ribbon cable.
- Photograph the board and both connector orientations before removal.
- Label the board with its wall location and its six-, eight-, or ten-light
  configuration. Do not rely on memory.
- Use normal antistatic precautions when handling the PCB, especially its
  surface-mount components.
- The data connectors are not keyed and can physically be inserted backward.
  They must not be reversed electrically. Confirm `GND` and
  `DI` against the board markings and the boards above and below before
  applying power. Never use the ribbon cable's red stripe alone to determine
  orientation: existing cables do not all place the stripe on the same signal
  side.
- The power connectors are keyed. Do not force them if they do not mate
  naturally. If they do not mate, recheck the board's orientation.
- If there is overheated wiring, a burnt board, damaged insulation, or an
  uncertain power connection, stop and obtain qualified assistance before
  proceeding.

## What to record before removing a board

Test the wall first and write down the exact symptom. Determine whether the
fault affects one memorial light, all lights on one board, or this board and
boards farther along the same cable path.

Record whether a light is always off, always on, incorrect only in some test
patterns, or intermittent. Also record whether supporting the cable or
connector changes the symptom; do not unplug or move a connector while power
is on.

## Access behind the wall

<a href="images/access_behind_wall.jpeg">
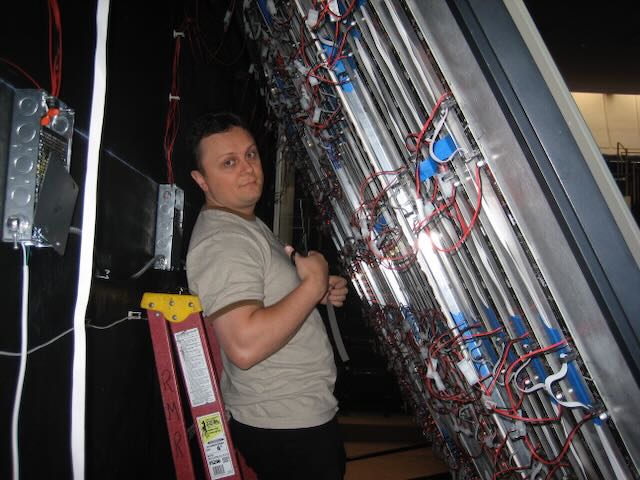
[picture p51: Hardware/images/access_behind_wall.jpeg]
Working behind a tilted Yahrzeit Wall section
  
</a>

*The YYZ Pixel boards and their wiring are reached from behind the tilted
section. Secure the section with the retained wooden service prop and make sure
the prop cannot slip before proceeding.*

## Select the replacement board

YYZ Pixel boards were made in three physical sizes: 6-pixel, 8-pixel, and
10-pixel. Tested spares are supplied in all three sizes. Select the spare that
matches the removed board; the LED locations must correspond to the
machined holes in the aluminum chassis.

<a href="images/yyz_pixel_board_closeup.jpeg">
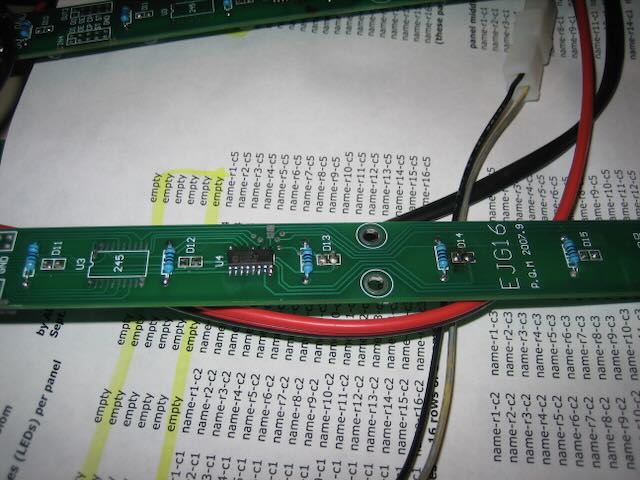
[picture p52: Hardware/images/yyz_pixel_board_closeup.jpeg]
Close-up of an installed YYZ Pixel board
  
</a>

*Close-up of an installed YYZ Pixel board. The replacement must match its
length and LED spacing so the LEDs align with the chassis openings.*

Before disconnecting anything, photograph the top and bottom of the installed
board closely enough to show every power and data connection. On the back
side of the board (the side against the aluminum chassis), The LEDs are labeled
D1 through D8, for example (or the highest numbered LED). Note that `D1` is at the top
and D8, for example, is at the bottom.

## Try the connections before replacing the board

A connection or data cable may cause symptoms that appear to come from the
pixel board. Before removing a board:

1. Switch off the Yahrzeit Wall and verify that its LEDs are dark.
2. Photograph and label the top and bottom connections.
3. Replace both data-signal cables with known-good cables. Because these
   connectors are not keyed, explicitly verify `GND` to `GND` and `DI` to `DI`
   at both ends. Do not use the red stripe to determine orientation.
4. Unplug and firmly reconnect both keyed power connectors. Do not force them, but they must be firmly mated.
5. Inspect all four connections, restore power, and check the board and the
   boards farther along both data chains.

If normal operation returns, leave the board installed and record the cable or
connection correction. Replace the pixel board only if the fault remains.

## Replace a board

1. Secure the wall section with the wooden service prop in its tilted service
   position. Switch the Yahrzeit Wall off, and
   verify that its LEDs are dark.
2. Confirm that the replacement is the same 6-, 8-, or 10-pixel size as the
   installed board.
3. Photograph and/or label all four connections. Disconnect the top and bottom
   keyed power connectors, then the top and bottom data-chain connectors. Pull
   on connector bodies, not wires.
4. Slide a putty knife carefully between the old board's adhesive and the
   aluminum chassis. The board is normally held by three pieces of double-sided
   tape. Work gradually to avoid damaging the chassis, cracking the PCB, or
   damaging wiring.
5. Remove every remnant of the old double-sided tape from the chassis. The
   mounting surface must be clean and flat before the spare is positioned.
6. Determine the spare's top and bottom **before** applying tape. The board is
   oriented with `D1` at the top and the highest numbered LED—`D6`, `D8`, or
   `D10`, depending on the board size—at the bottom. These markings are on the
   face that will be adhered to the aluminum and will no longer be visible
   afterward.
7. Insulate the solder-side pins of all four through-hole connectors—the top
   and bottom data connectors and the top and bottom power connectors—so they
   cannot short against the aluminum. Double-sided mounting tape may be placed
   over these pins, or black electrical tape may be used as insulation. Check
   that no connector pin can touch bare aluminum.
8. Apply new double-sided mounting tape. Do not remove its chassis-side release
   liner until orientation and alignment have been checked.
9. Precisely align the PCB's silkscreened alignment marks with the marks drawn
   on the aluminum chassis. This positions every LED behind its machined hole.
   Check all LED positions visually, then press the board firmly into place.
10. Reconnect both keyed power connectors. Reconnect the top and bottom data
    connectors exactly as photographed. At each data connector, trace the
    conductors and explicitly verify `GND` to `GND` and `DI` to `DI`; the red
    stripe is not a reliable polarity indicator.
11. Inspect for trapped wires, exposed connector pins touching aluminum,
    reversed data connectors, and LEDs out of alignment. Only then restore
    power and verify operation using the normally installed Wall system.

> **Critical:** A data plug can physically fit the wrong way. Correct
> orientation is established by the `GND` and `DI` signals—not by the cable's
> red stripe.

## Verify the replacement

After restoring power, use the normally installed Wall system to confirm that:

- every LED on the replacement board operates;
- the replacement board's LEDs align with the chassis openings;
- the boards farther along both data-chain connections still operate; and
- no cable is trapped, strained, or touching an unsafe location.

If the replacement or any following board does not operate correctly, switch
the Wall off again. Recheck the replacement's orientation and verify `GND` to
`GND` and `DI` to `DI` at both data connectors. Do not repeatedly apply power
while the connector orientation is uncertain.

## Replacement record

Record each replacement so the spare inventory and Wall history remain clear.

| Date | Wall location | Board size | Original symptom | Replacement result |
|---|---|---:|---|---|
|  |  | 6/8/10 |  |  |
|  |  | 6/8/10 |  |  |
|  |  | 6/8/10 |  |  |
|  |  | 6/8/10 |  |  |

## References

- [Hardware overview](README.md)
- [Original YYZ pixel-board schematic](schematics/Schematic_yyz_pixel.pdf)

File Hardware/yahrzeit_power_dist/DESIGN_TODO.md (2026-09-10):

# Yahrzeit Power Distribution Board — Design TODO

**Status:** Preliminary design; review these items before fabrication or BOM
release.

## Power-present indicator

- Add a conspicuous power-present LED near J1, with a board legend such as
  `POWER ON — 12V`.
- Connect the indicator to the protected/rectified 12 V rail, after F1 and D1,
  rather than only to the regulated 5 V output. This ensures that an energized
  board remains visibly identified even if U1 has failed or is inhibited.
- Tentative circuit: green SMD LED plus an SMD series resistor. Select the LED,
  current, resistor value, power rating, footprints, and MPNs during the BOM
  review. Approximately 2–4 mA should provide a clearly visible indicator
  without meaningful loading.
- Position the LED so it remains visible with the board installed and does not
  sit beneath a cable or the buck module.
- The indicator is advisory only. Documentation must still require power to be
  disconnected and verified with a meter before servicing.

## Component and footprint audit

### F1 — resolve part/footprint mismatch

- The present MPN, Littelfuse `0215004.MXP`, is a 4 A, 5 x 20 mm cartridge
  fuse.
- The assigned footprint, `Fuseholder_Blade_Mini_Keystone_3568`, is for a MINI
  automotive blade fuse and is not compatible with that MPN.
- Choose one implementation and make the symbol value, MPN, datasheet, holder,
  and PCB footprint agree.
- Confirm the required time-current characteristic, interrupting rating,
  voltage rating, inrush behavior, and field-replacement procedure.

### D1 — select and verify the final reverse-polarity diode

- Confirm a currently manufactured and orderable single Schottky rectifier.
- The selected part must match the two-lead TO-220 footprint and pin numbering.
- Add the manufacturer datasheet to the schematic field.
- Calculate forward loss and temperature rise at measured maximum input
  current. Reconsider an ideal-diode MOSFET solution if the Schottky loss is
  excessive.

### F2–F7 — reconcile rating and labeling

- The current MPN, Littelfuse `1812L150/16DR`, is a resettable PTC with a 1.5 A
  hold current and 2.8 A trip current at 20 degrees C; it is not a 1.25 A
  slow-blow fuse.
- Either relabel the schematic and board for the actual 1.5 A-hold PTC or
  select a genuine 1.25 A-hold device.
- Evaluate temperature derating, normal branch current, fault current, trip
  time, resistance/voltage drop, and reset behavior.
- After selection, copy the final MPN and manufacturer datasheet into F2–F7.

### Connector ordering codes

- Replace abbreviated JST values such as `B2P-VH` and `B3P-VH` with complete,
  orderable manufacturer MPNs, including the required plating/packaging
  suffixes.
- Confirm mating housings, crimp contacts, wire gauge, polarization, and cable
  drawings for J1 and J3–J8.

## Final pre-fabrication checks

- Measure actual column current and voltage at the wall under worst-case LED
  load before finalizing fuse and conductor ratings.
- Complete the high-current routing, front-side power copper, back-side GND
  plane, and ground-stitching-via design.
- Review U1 input/output capacitor loops and the local `SENSE` and `ADJ`
  routing.
- Check creepage/clearance, copper bottlenecks, thermal reliefs, connector
  access, hinge clearance, cable clearance, and mounting-hole clearance.
- Run KiCad ERC and DRC and resolve or explicitly document every exception.
- Generate and review the fabrication outputs, BOM, placement data, assembly
  drawing, and cable drawings before ordering.

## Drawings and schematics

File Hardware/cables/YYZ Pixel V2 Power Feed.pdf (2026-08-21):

# YYZ Pixel V2 Power Feed

## Diagram

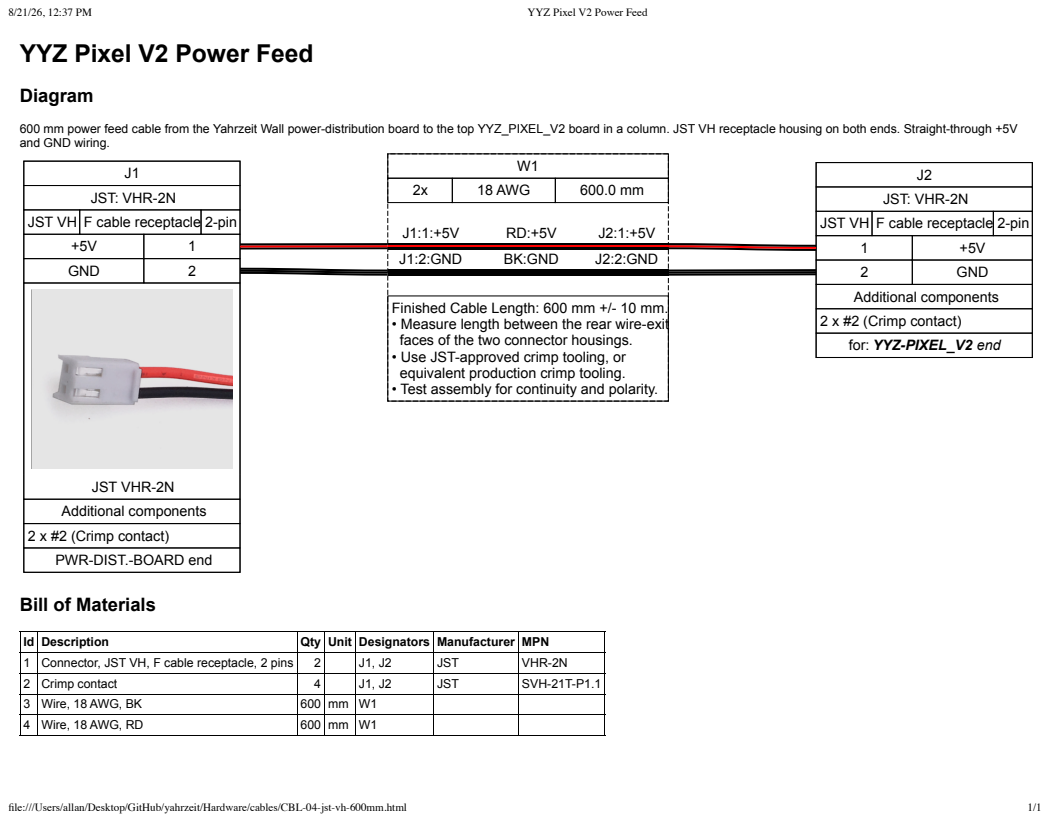
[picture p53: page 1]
JST: VHR-2N; GND; 18 AWG; J1:2:GND; BK:GND; J2:2:GND; YYZ Pixel V2 Power Feed; file:///Users/allan/Desktop/GitHub/yahrzeit/Hardware/cables/CBL-04-jst-vh-600mm.html

600 mm power feed cable from the Yahrzeit Wall power-distribution board to the top YYZ_PIXEL_V2 board in a column. JST VH receptacle housing on both ends. Straight-through +5V
and GND wiring.

JST VH F cable receptacle 2-pin

Additional components
2 x #2 (Crimp contact)
for: YYZ-PIXEL_V2 end

Finished Cable Length: 600 mm +/- 10 mm.
• Measure length between the rear wire-exit
faces of the two connector housings.
• Use JST-approved crimp tooling, or
equivalent production crimp tooling.
• Test assembly for continuity and polarity.

JST VHR-2N
PWR-DIST.-BOARD end

Bill of Materials

Id | Description | Qty | Unit | Designators | Manufacturer | MPN
1 | Connector, JST VH, F cable receptacle, 2 pins | 2 | | J1, J2 | JST | VHR-2N
2 | Crimp contact | 4 | | J1, J2 | JST | SVH-21T-P1.1
3 | Wire, 18 AWG, BK | 600 | mm | W1
4 | Wire, 18 AWG, RD | 600 | mm | W1

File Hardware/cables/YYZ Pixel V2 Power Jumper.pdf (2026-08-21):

# YYZ Pixel V2 Power Jumper

## Diagram

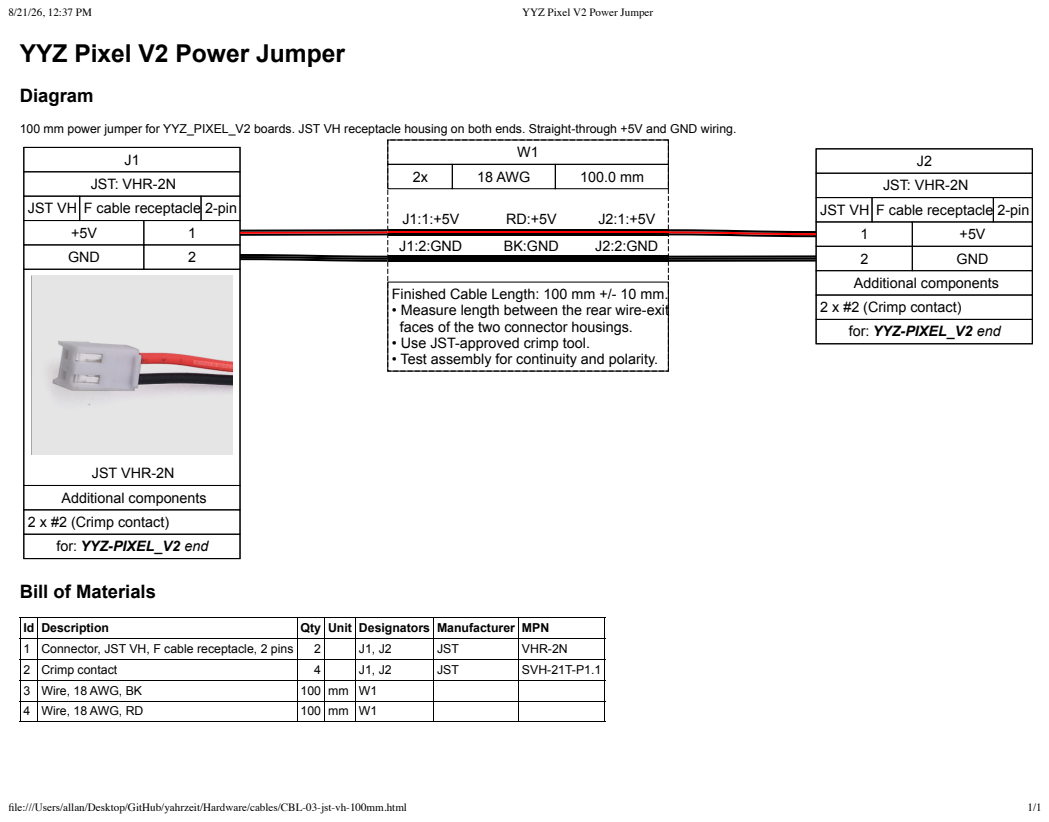
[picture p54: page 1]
JST: VHR-2N; GND; 18 AWG; J1:2:GND; BK:GND; J2:2:GND; YYZ Pixel V2 Power Jumper; file:///Users/allan/Desktop/GitHub/yahrzeit/Hardware/cables/CBL-03-jst-vh-100mm.html

100 mm power jumper for YYZ_PIXEL_V2 boards. JST VH receptacle housing on both ends. Straight-through +5V and GND wiring.

JST VH F cable receptacle 2-pin

Additional components
2 x #2 (Crimp contact)
for: YYZ-PIXEL_V2 end

Finished Cable Length: 100 mm +/- 10 mm.
• Measure length between the rear wire-exit
faces of the two connector housings.
• Use JST-approved crimp tool.
• Test assembly for continuity and polarity.

JST VHR-2N

Bill of Materials

Id | Description | Qty | Unit | Designators | Manufacturer | MPN
1 | Connector, JST VH, F cable receptacle, 2 pins | 2 | | J1, J2 | JST | VHR-2N
2 | Crimp contact | 4 | | J1, J2 | JST | SVH-21T-P1.1
3 | Wire, 18 AWG, BK | 100 | mm | W1
4 | Wire, 18 AWG, RD | 100 | mm | W1

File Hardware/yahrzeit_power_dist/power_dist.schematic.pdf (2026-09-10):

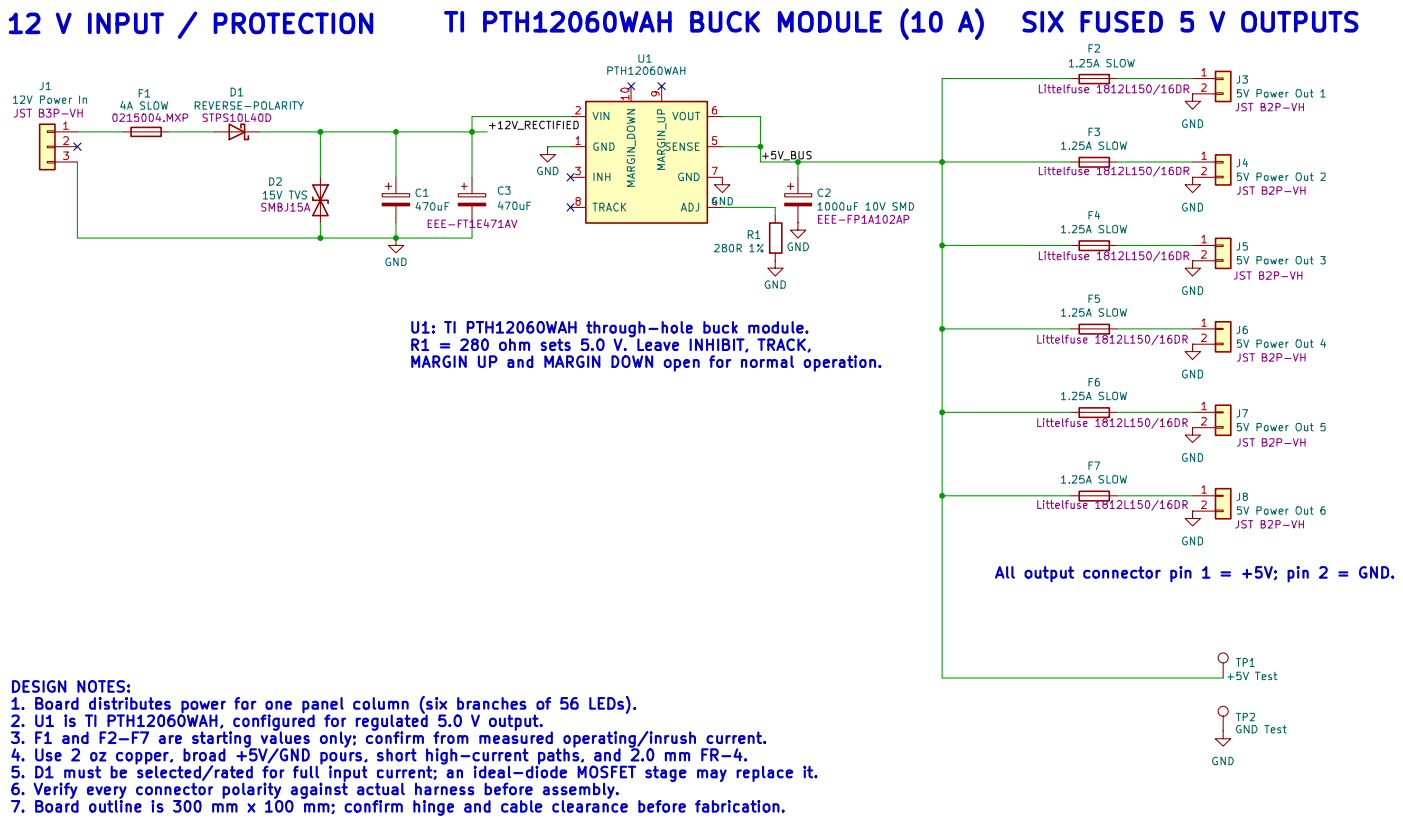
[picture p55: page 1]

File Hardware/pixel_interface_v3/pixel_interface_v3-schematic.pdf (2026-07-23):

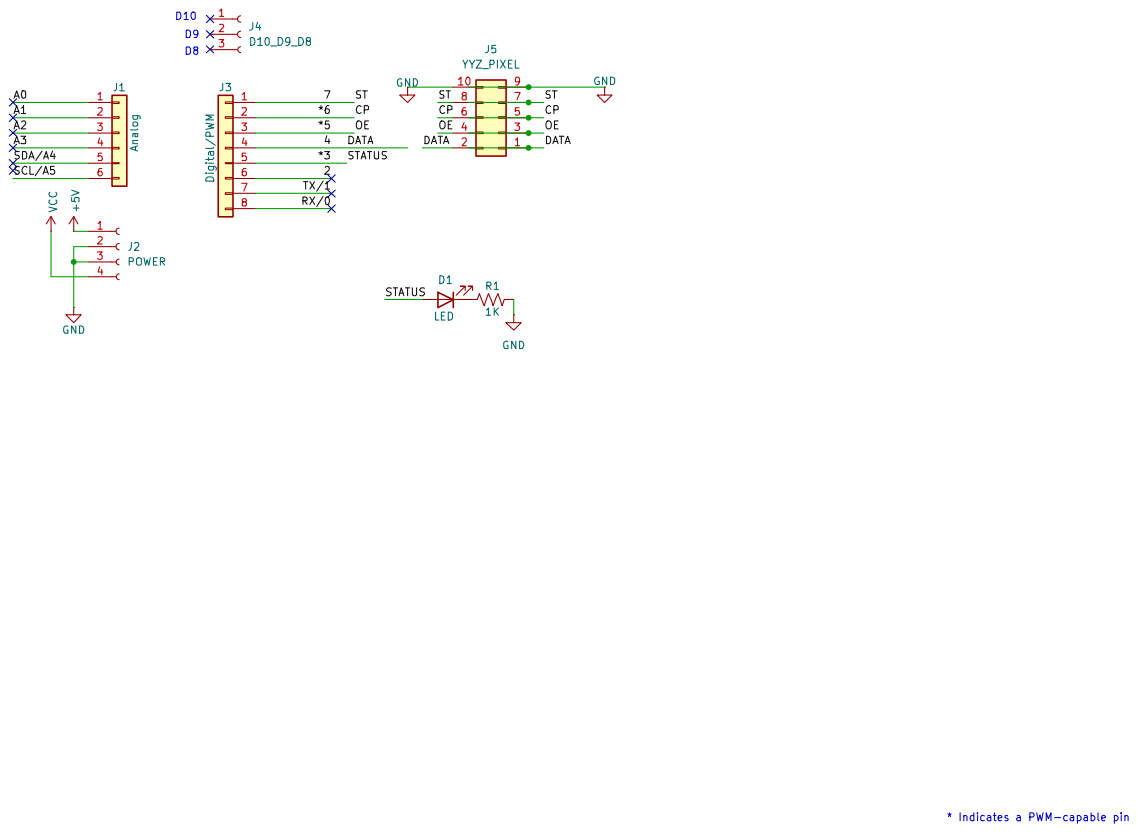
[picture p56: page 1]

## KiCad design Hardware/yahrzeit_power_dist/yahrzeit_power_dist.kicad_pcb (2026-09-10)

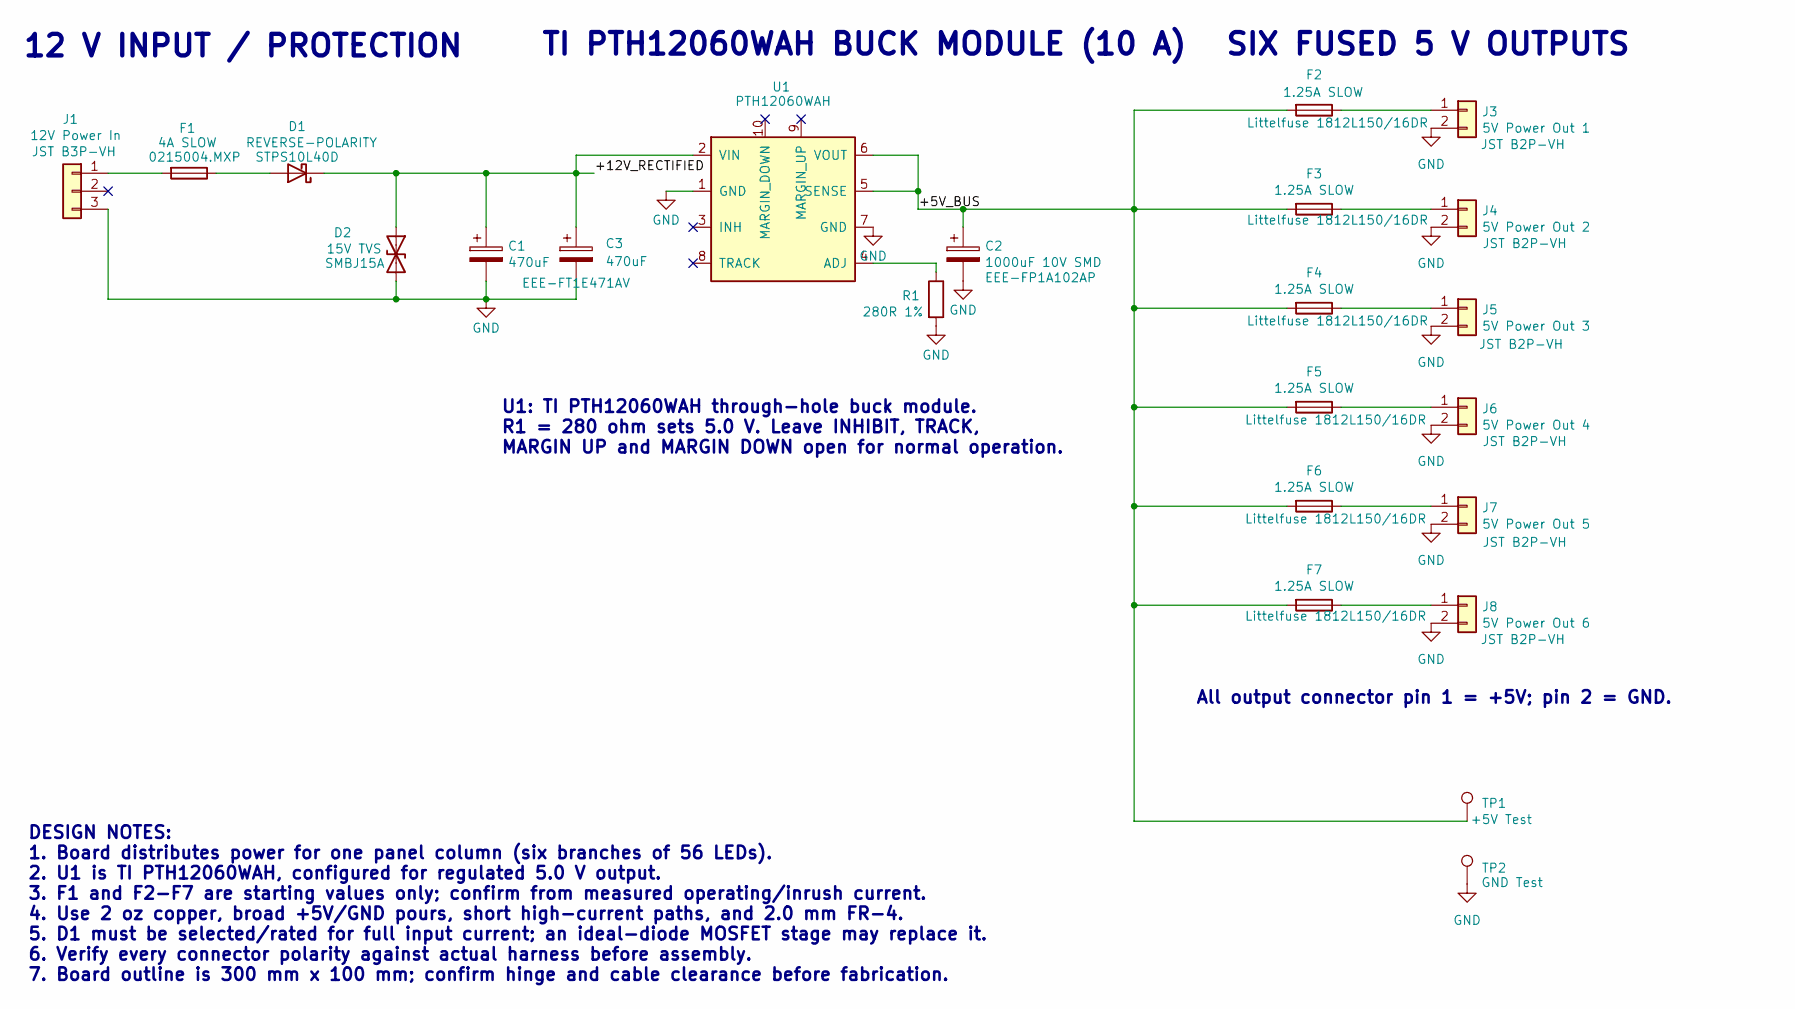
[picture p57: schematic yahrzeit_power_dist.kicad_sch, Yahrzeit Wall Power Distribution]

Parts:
C1, C3: 470uF; CP_Elec_8x10.5; MPN EEE-FT1E471AV
C2: 1000uF 10V SMD; CP_Elec_10x10.5; MPN EEE-FP1A102AP
D1: REVERSE-POLARITY; TO-220-2_Vertical; MPN STPS10L40D
D2: 15V TVS; D_SMB; MPN SMBJ15A
F1: 4A SLOW; Fuseholder_Blade_Mini_Keystone_3568; MPN 0215004.MXP
F2, F3, F4, F5, F6, F7: 1.25A SLOW; Fuse_1812_4532Metric; MPN Littelfuse 1812L150/16DR
J1: 12V Power In; JST_VH_B3P-VH-B_1x03_P3.96mm_Vertical; MPN JST B3P-VH
J3: 5V Power Out 1; JST_VH_B2P-VH-B_1x02_P3.96mm_Vertical; MPN JST B2P-VH
J4: 5V Power Out 2; JST_VH_B2P-VH-B_1x02_P3.96mm_Vertical; MPN JST B2P-VH
J5: 5V Power Out 3; JST_VH_B2P-VH-B_1x02_P3.96mm_Vertical; MPN JST B2P-VH
J6: 5V Power Out 4; JST_VH_B2P-VH-B_1x02_P3.96mm_Vertical; MPN JST B2P-VH
J7: 5V Power Out 5; JST_VH_B2P-VH-B_1x02_P3.96mm_Vertical; MPN JST B2P-VH
J8: 5V Power Out 6; JST_VH_B2P-VH-B_1x02_P3.96mm_Vertical; MPN JST B2P-VH
R1: 280R 1%; R_0805_2012Metric; MPN RC0805FR-07280RL
TP1: +5V Test; TestPoint_Keystone_5016_Compact; MPN Keystone 5016
TP2: GND Test; TestPoint_Keystone_5016_Compact; MPN Keystone 5016
U1: PTH12060WAH; TI_PTH12060WAH_EUW_THT; MPN PTH12060WAH

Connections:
/+5V_BUS: C2.1, F2.2, F3.2, F4.2, F5.2, F6.2, F7.2, TP1.1 (1_1), U1.5 (SENSE), U1.6 (VOUT)
/+12V_RECTIFIED: C1.1, C3.1, D1.1 (K), D2.1 (A1), U1.2 (VIN)
GND: C1.2, C2.2, C3.2, D2.2 (A2), J1.3, J3.2, J4.2, J5.2, J6.2, J7.2, J8.2, R1.2, TP2.1 (1_1), U1.1 (GND), U1.7 (GND)
unnamed: D1.2 (A), F1.1
unnamed: F1.2, J1.1
unnamed: F2.1, J3.1
unnamed: F3.1, J4.1
unnamed: F4.1, J5.1
unnamed: F5.1, J6.1
unnamed: F6.1, J7.1
unnamed: F7.1, J8.1
unnamed: R1.1, U1.4 (ADJ)

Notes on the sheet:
U1: TI PTH12060WAH through-hole buck module. R1 = 280 ohm sets 5.0 V. Leave INHIBIT, TRACK, MARGIN UP and MARGIN DOWN open for normal operation.
SIX FUSED 5 V OUTPUTS
TI PTH12060WAH BUCK MODULE (10 A)
12 V INPUT / PROTECTION
All output connector pin 1 = +5V; pin 2 = GND.
DESIGN NOTES: 1. Board distributes power for one panel column (six branches of 56 LEDs). 2. U1 is TI PTH12060WAH, configured for regulated 5.0 V output. 3. F1 and F2-F7 are starting values only; confirm from measured operating/inrush current. 4. Use 2 oz copper, broad +5V/GND pours, short high-curr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

Board: 2 copper layers, 27 parts (0 on the bottom side), 12 nets, no tracks yet.

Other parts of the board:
H1, H2, H3, H4: MountingHole_4.5mm

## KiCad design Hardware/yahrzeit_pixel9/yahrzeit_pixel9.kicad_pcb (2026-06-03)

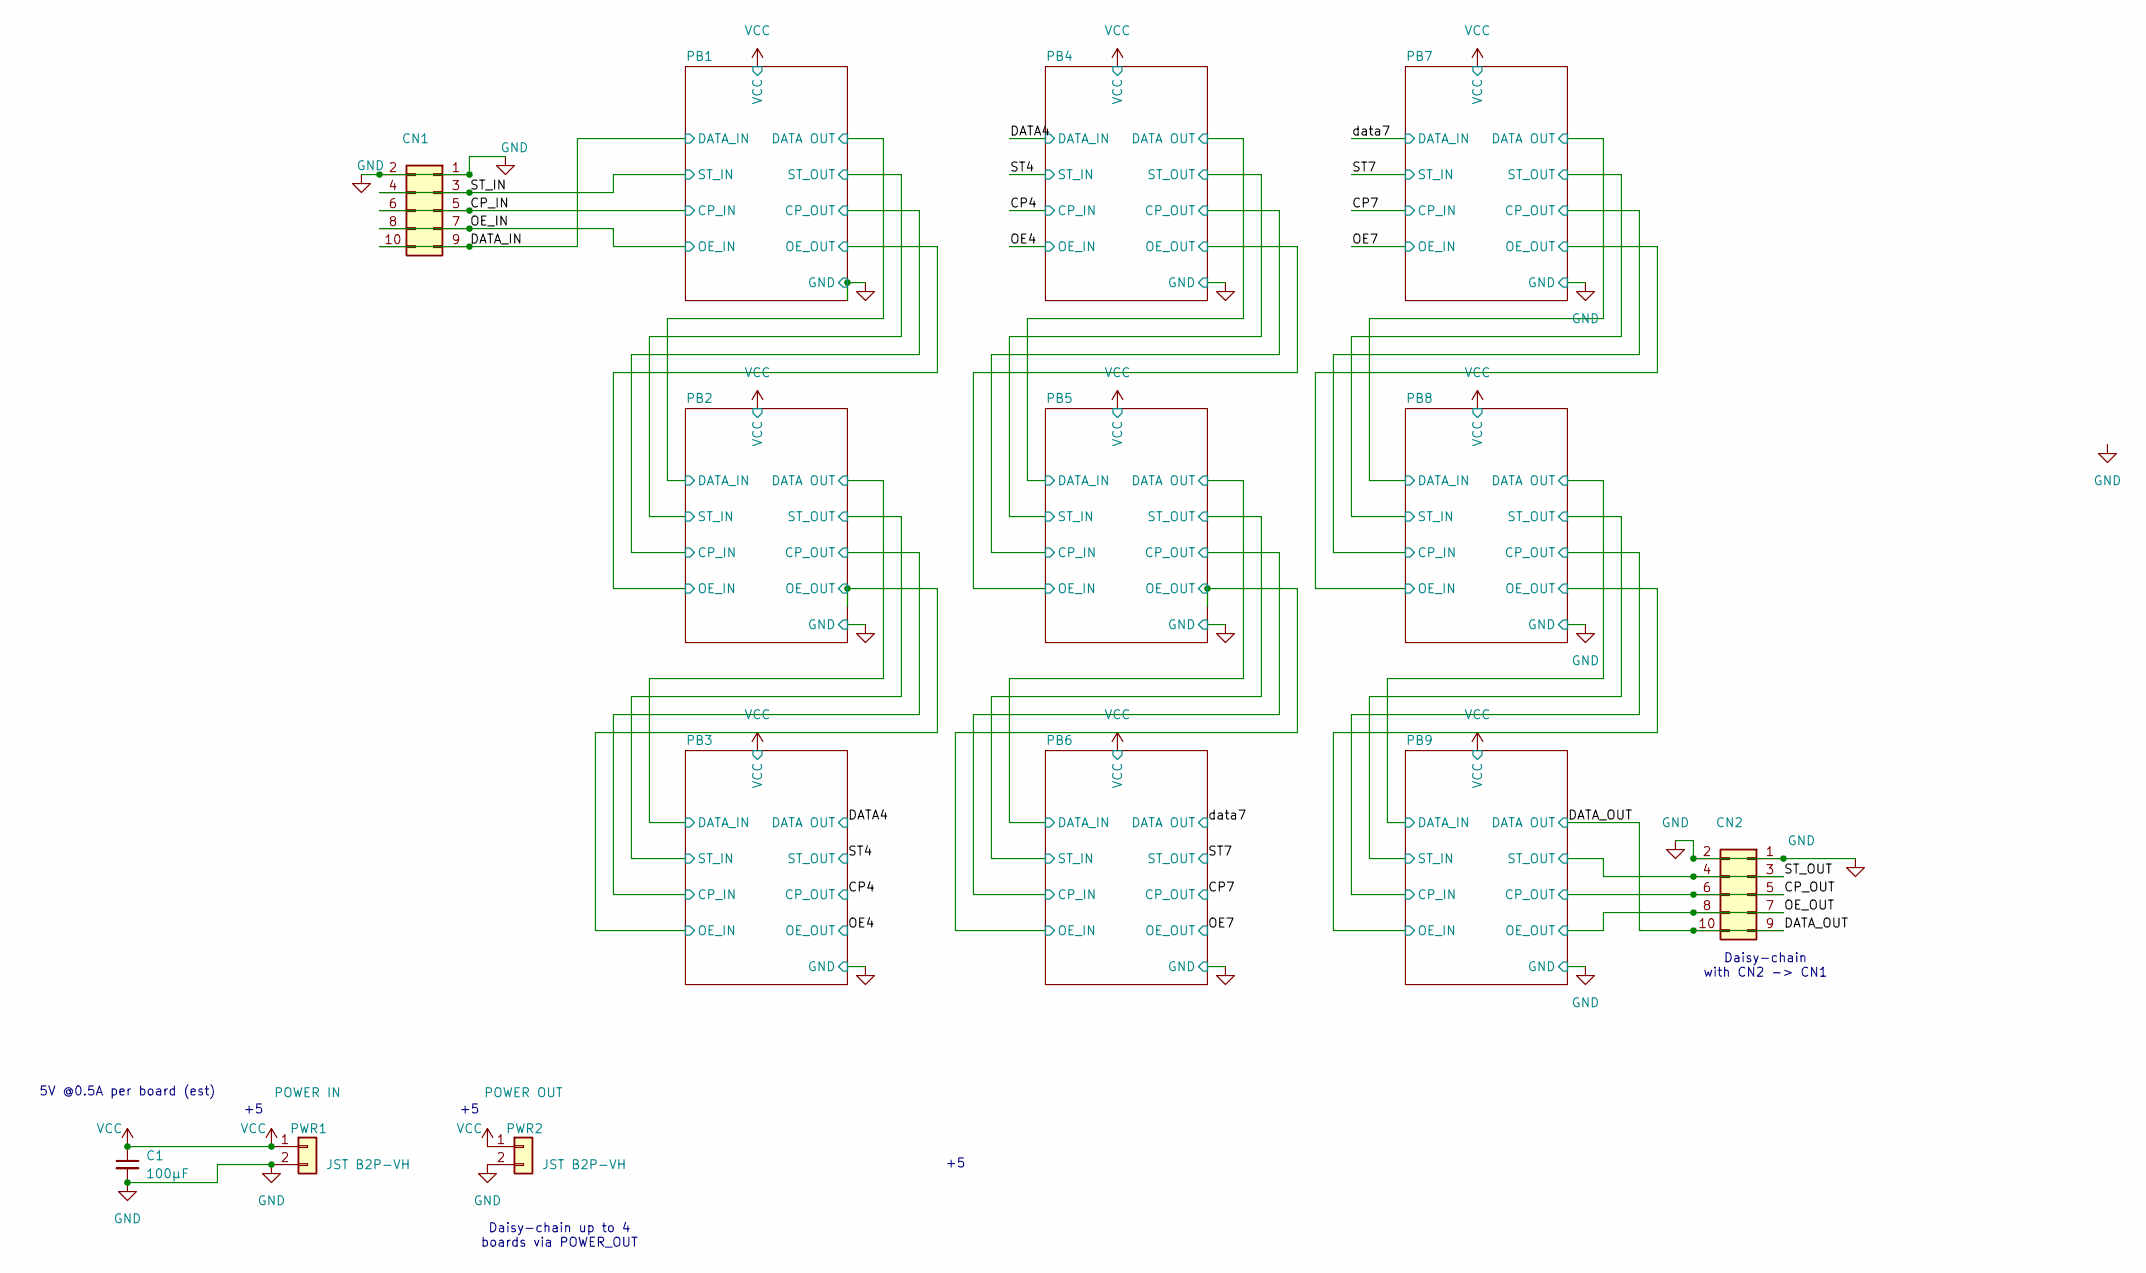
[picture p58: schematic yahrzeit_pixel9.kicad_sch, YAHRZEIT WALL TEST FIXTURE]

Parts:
C1: 100µF; CP_Elec_6.3x7.7
CN1, CN2: Conn_02x05; PinHeader_2x05_P2.54mm_Vertical
PWR1: JST B2P-VH; JST_VH_B2P-VH_1x02_P3.96mm_Vertical; part desc CONN HEADER VERT 2POS 3.96MM
PWR2: JST B2P-VH; JST_VH_B2P-VH_1x02_P3.96mm_Vertical; part desc. CONN HEADER VERT 2POS 3.96MM

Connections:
/CP_IN: CN1.5, CN1.6; also elsewhere on the board
/CP_OUT: CN2.5, CN2.6; also elsewhere on the board
/DATA_IN: CN1.9, CN1.10; also elsewhere on the board
/DATA_OUT: CN2.9, CN2.10; also elsewhere on the board
/OE_IN: CN1.7, CN1.8; also elsewhere on the board
/OE_OUT: CN2.7, CN2.8; also elsewhere on the board
/ST_IN: CN1.3, CN1.4; also elsewhere on the board
/ST_OUT: CN2.3, CN2.4; also elsewhere on the board
GND: C1.2, CN1.1, CN1.2, CN2.1, CN2.2, PWR1.2, PWR2.2; also elsewhere on the board
VCC: C1.1, PWR1.1, PWR2.1; also elsewhere on the board

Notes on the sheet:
5V @0.5A per board (est)
Daisy-chain with CN2 -> CN1
Daisy-chain up to 4 boards via POWER_OUT

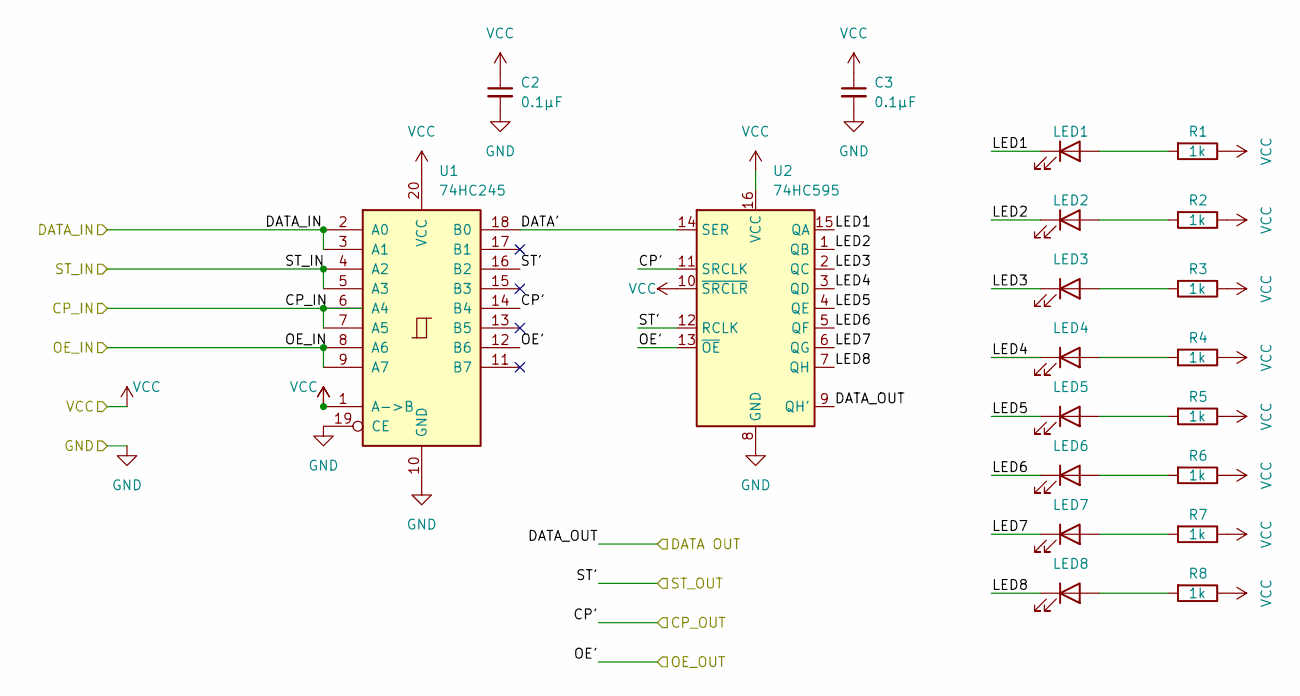
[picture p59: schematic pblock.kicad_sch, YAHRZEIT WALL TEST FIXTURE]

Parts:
C2, C3: 0.1µF; C_0603_1608Metric
LED1, LED2, LED3, LED4, LED5, LED6, LED7, LED8: LED; LED_0805_2012Metric
R1, R2, R3, R4, R5, R6, R7, R8: 1k; R_0603_1608Metric
U1: 74HC245; SO-20_5.3x12.6mm_P1.27mm
U2: 74HC595; JEITA_SOIC-16_3.9x9.9mm_P1.27mm

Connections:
/CP_IN: U1.6 (A4), U1.7 (A5); also elsewhere on the board
/DATA_IN: U1.2 (A0), U1.3 (A1); also elsewhere on the board
/OE_IN: U1.8 (A6), U1.9 (A7); also elsewhere on the board
/PB1/CP': U1.14 (B4), U2.11 (SRCLK); also elsewhere on the board
/PB1/DATA': U1.18 (B0), U2.14 (SER)
/PB1/DATA_OUT: U2.9 (QH'); also elsewhere on the board
/PB1/LED1: LED1.1 (K), U2.15 (QA)
/PB1/LED2: LED2.1 (K), U2.1 (QB)
/PB1/LED3: LED3.1 (K), U2.2 (QC)
/PB1/LED4: LED4.1 (K), U2.3 (QD)
/PB1/LED5: LED5.1 (K), U2.4 (QE)
/PB1/LED6: LED6.1 (K), U2.5 (QF)
/PB1/LED7: LED7.1 (K), U2.6 (QG)
/PB1/LED8: LED8.1 (K), U2.7 (QH)
/PB1/OE': U1.12 (B6), U2.13 (~OE); also elsewhere on the board
/PB1/ST': U1.16 (B2), U2.12 (RCLK); also elsewhere on the board
/ST_IN: U1.4 (A2), U1.5 (A3); also elsewhere on the board
GND: C2.2, C3.2, U1.10 (GND), U1.19 (CE), U2.8 (GND); also elsewhere on the board
unnamed: LED1.2 (A), R1.2
unnamed: LED2.2 (A), R2.2
unnamed: LED3.2 (A), R3.2
unnamed: LED4.2 (A), R4.2
unnamed: LED5.2 (A), R5.2
unnamed: LED6.2 (A), R6.2
unnamed: LED7.2 (A), R7.2
unnamed: LED8.2 (A), R8.2
VCC: C2.1, C3.1, R1.1, R2.1, R3.1, R4.1, R5.1, R6.1, R7.1, R8.1, U1.1 (A->B), U1.20 (VCC), U2.10 (~SRCLR), U2.16 (VCC); also elsewhere on the board

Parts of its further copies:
C4, C5, C6, C7, C8, C9, C10, C11, C12, C13, C14, C15, C16, C17, C18, C19: 0.1µF; C_0603_1608Metric
LED9, LED10, LED11, LED12, LED13, LED14, LED15, LED16, LED17, LED18, LED19, LED20, LED21, LED22, LED23, LED24, LED25, LED26, LED27, LED28, LED29, LED30, LED31, LED32, LED33, LED34, LED35, LED36, LED37, LED38, LED39, LED40, LED41, LED42, LED43, LED44, LED45, LED46, LED47, LED48, LED49, LED50, LED51, LED52, LED53, LED54, LED55, LED56, LED57, LED58, LED59, LED60, LED61, LED62, LED63, LED64, LED65, LED66, LED67, LED68, LED69, LED70, LED71, LED72: LED; LED_0805_2012Metric
R9, R10, R11, R12, R13, R14, R15, R16, R17, R18, R19, R20, R21, R22, R23, R24, R25, R26, R27, R28, R29, R30, R31, R32, R33, R34, R35, R36, R37, R38, R39, R40, R41, R42, R43, R44, R45, R46, R47, R48, R49, R50, R51, R52, R53, R54, R55, R56, R57, R58, R59, R60, R61, R62, R63, R64, R65, R66, R67, R68, R69, R70, R71, R72: 1k; R_0603_1608Metric
U3, U5, U7, U9, U11, U13, U15, U17: 74HC245; SO-20_5.3x12.6mm_P1.27mm
U4, U6, U8, U10, U12, U14, U16, U18: 74HC595; JEITA_SOIC-16_3.9x9.9mm_P1.27mm

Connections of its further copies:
/CP4: U5.14 (B4), U6.11 (SRCLK), U7.6 (A4), U7.7 (A5)
/CP7: U11.14 (B4), U12.11 (SRCLK), U13.6 (A4), U13.7 (A5)
/CP_OUT: U17.14 (B4), U18.11 (SRCLK); also elsewhere on the board
/DATA4: U6.9 (QH'), U7.2 (A0), U7.3 (A1)
/DATA_OUT: U18.9 (QH'); also elsewhere on the board
/OE4: U5.12 (B6), U6.13 (~OE), U7.8 (A6), U7.9 (A7)
/OE7: U11.12 (B6), U12.13 (~OE), U13.8 (A6), U13.9 (A7)
/OE_OUT: U17.12 (B6), U18.13 (~OE); also elsewhere on the board
/PB1/CP': U3.6 (A4), U3.7 (A5); also elsewhere on the board
/PB1/DATA_OUT: U3.2 (A0), U3.3 (A1); also elsewhere on the board
/PB1/OE': U3.8 (A6), U3.9 (A7); also elsewhere on the board
/PB1/ST': U3.4 (A2), U3.5 (A3); also elsewhere on the board
/PB2/CP': U3.14 (B4), U4.11 (SRCLK), U5.6 (A4), U5.7 (A5)
/PB2/DATA': U3.18 (B0), U4.14 (SER)
/PB2/DATA_OUT: U4.9 (QH'), U5.2 (A0), U5.3 (A1)
/PB2/LED1: LED9.1 (K), U4.15 (QA)
/PB2/LED2: LED10.1 (K), U4.1 (QB)
/PB2/LED3: LED11.1 (K), U4.2 (QC)
/PB2/LED4: LED12.1 (K), U4.3 (QD)
/PB2/LED5: LED13.1 (K), U4.4 (QE)
/PB2/LED6: LED14.1 (K), U4.5 (QF)
/PB2/LED7: LED15.1 (K), U4.6 (QG)
/PB2/LED8: LED16.1 (K), U4.7 (QH)
/PB2/OE': U3.12 (B6), U4.13 (~OE), U5.8 (A6), U5.9 (A7)
/PB2/ST': U3.16 (B2), U4.12 (RCLK), U5.4 (A2), U5.5 (A3)
/PB3/DATA': U5.18 (B0), U6.14 (SER)
/PB3/LED1: LED17.1 (K), U6.15 (QA)
/PB3/LED2: LED18.1 (K), U6.1 (QB)
/PB3/LED3: LED19.1 (K), U6.2 (QC)
/PB3/LED4: LED20.1 (K), U6.3 (QD)
/PB3/LED5: LED21.1 (K), U6.4 (QE)
/PB3/LED6: LED22.1 (K), U6.5 (QF)
/PB3/LED7: LED23.1 (K), U6.6 (QG)
/PB3/LED8: LED24.1 (K), U6.7 (QH)
/PB4/CP': U7.14 (B4), U8.11 (SRCLK), U9.6 (A4), U9.7 (A5)
/PB4/DATA': U7.18 (B0), U8.14 (SER)
/PB4/DATA_OUT: U8.9 (QH'), U9.2 (A0), U9.3 (A1)
/PB4/LED1: LED25.1 (K), U8.15 (QA)
/PB4/LED2: LED26.1 (K), U8.1 (QB)
/PB4/LED3: LED27.1 (K), U8.2 (QC)
/PB4/LED4: LED28.1 (K), U8.3 (QD)
/PB4/LED5: LED29.1 (K), U8.4 (QE)
/PB4/LED6: LED30.1 (K), U8.5 (QF)
/PB4/LED7: LED31.1 (K), U8.6 (QG)
/PB4/LED8: LED32.1 (K), U8.7 (QH)
/PB4/OE': U7.12 (B6), U8.13 (~OE), U9.8 (A6), U9.9 (A7)
/PB4/ST': U7.16 (B2), U8.12 (RCLK), U9.4 (A2), U9.5 (A3)
/PB5/CP': U9.14 (B4), U10.11 (SRCLK), U11.6 (A4), U11.7 (A5)
/PB5/DATA': U9.18 (B0), U10.14 (SER)
/PB5/DATA_OUT: U10.9 (QH'), U11.2 (A0), U11.3 (A1)
/PB5/LED1: LED33.1 (K), U10.15 (QA)
/PB5/LED2: LED34.1 (K), U10.1 (QB)
/PB5/LED3: LED35.1 (K), U10.2 (QC)
/PB5/LED4: LED36.1 (K), U10.3 (QD)
/PB5/LED5: LED37.1 (K), U10.4 (QE)
/PB5/LED6: LED38.1 (K), U10.5 (QF)
/PB5/LED7: LED39.1 (K), U10.6 (QG)
/PB5/LED8: LED40.1 (K), U10.7 (QH)
/PB5/OE': U9.12 (B6), U10.13 (~OE), U11.8 (A6), U11.9 (A7)
/PB5/ST': U9.16 (B2), U10.12 (RCLK), U11.4 (A2), U11.5 (A3)
/PB6/DATA': U11.18 (B0), U12.14 (SER)
/PB6/LED1: LED41.1 (K), U12.15 (QA)
/PB6/LED2: LED42.1 (K), U12.1 (QB)
/PB6/LED3: LED43.1 (K), U12.2 (QC)
/PB6/LED4: LED44.1 (K), U12.3 (QD)
/PB6/LED5: LED45.1 (K), U12.4 (QE)
/PB6/LED6: LED46.1 (K), U12.5 (QF)
/PB6/LED7: LED47.1 (K), U12.6 (QG)
/PB6/LED8: LED48.1 (K), U12.7 (QH)
/PB7/CP': U13.14 (B4), U14.11 (SRCLK), U15.6 (A4), U15.7 (A5)
/PB7/DATA': U13.18 (B0), U14.14 (SER)
/PB7/DATA_OUT: U14.9 (QH'), U15.2 (A0), U15.3 (A1)
/PB7/LED1: LED49.1 (K), U14.15 (QA)
/PB7/LED2: LED50.1 (K), U14.1 (QB)
/PB7/LED3: LED51.1 (K), U14.2 (QC)
/PB7/LED4: LED52.1 (K), U14.3 (QD)
/PB7/LED5: LED53.1 (K), U14.4 (QE)
/PB7/LED6: LED54.1 (K), U14.5 (QF)
/PB7/LED7: LED55.1 (K), U14.6 (QG)
/PB7/LED8: LED56.1 (K), U14.7 (QH)
/PB7/OE': U13.12 (B6), U14.13 (~OE), U15.8 (A6), U15.9 (A7)
/PB7/ST': U13.16 (B2), U14.12 (RCLK), U15.4 (A2), U15.5 (A3)
/PB8/CP': U15.14 (B4), U16.11 (SRCLK), U17.6 (A4), U17.7 (A5)
/PB8/DATA': U15.18 (B0), U16.14 (SER)
/PB8/DATA_OUT: U16.9 (QH'), U17.2 (A0), U17.3 (A1)
/PB8/LED1: LED57.1 (K), U16.15 (QA)
/PB8/LED2: LED58.1 (K), U16.1 (QB)
/PB8/LED3: LED59.1 (K), U16.2 (QC)
/PB8/LED4: LED60.1 (K), U16.3 (QD)
/PB8/LED5: LED61.1 (K), U16.4 (QE)
/PB8/LED6: LED62.1 (K), U16.5 (QF)
/PB8/LED7: LED63.1 (K), U16.6 (QG)
/PB8/LED8: LED64.1 (K), U16.7 (QH)
/PB8/OE': U15.12 (B6), U16.13 (~OE), U17.8 (A6), U17.9 (A7)
/PB8/ST': U15.16 (B2), U16.12 (RCLK), U17.4 (A2), U17.5 (A3)
/PB9/DATA': U17.18 (B0), U18.14 (SER)
/PB9/LED1: LED65.1 (K), U18.15 (QA)
/PB9/LED2: LED66.1 (K), U18.1 (QB)
/PB9/LED3: LED67.1 (K), U18.2 (QC)
/PB9/LED4: LED68.1 (K), U18.3 (QD)
/PB9/LED5: LED69.1 (K), U18.4 (QE)
/PB9/LED6: LED70.1 (K), U18.5 (QF)
/PB9/LED7: LED71.1 (K), U18.6 (QG)
/PB9/LED8: LED72.1 (K), U18.7 (QH)
/ST4: U5.16 (B2), U6.12 (RCLK), U7.4 (A2), U7.5 (A3)
/ST7: U11.16 (B2), U12.12 (RCLK), U13.4 (A2), U13.5 (A3)
/ST_OUT: U17.16 (B2), U18.12 (RCLK); also elsewhere on the board
/data7: U12.9 (QH'), U13.2 (A0), U13.3 (A1)
GND: C4.2, C5.2, C6.2, C7.2, C8.2, C9.2, C10.2, C11.2, C12.2, C13.2, C14.2, C15.2, C16.2, C17.2, C18.2, C19.2, U3.10 (GND), U3.19 (CE), U4.8 (GND), U5.10 (GND), U5.19 (CE), U6.8 (GND), U7.10 (GND), U7.19 (CE), U8.8 (GND), U9.10 (GND), U9.19 (CE), U10.8 (GND), U11.10 (GND), U11.19 (CE), U12.8 (GND), U13.10 (GND), U13.19 (CE), U14.8 (GND), U15.10 (GND), U15.19 (CE), U16.8 (GND), U17.10 (GND), U17.19 (CE), U18.8 (GND); also elsewhere on the board
unnamed: LED9.2 (A), R9.2
unnamed: LED10.2 (A), R10.2
unnamed: LED11.2 (A), R11.2
unnamed: LED12.2 (A), R12.2
unnamed: LED13.2 (A), R13.2
unnamed: LED14.2 (A), R14.2
unnamed: LED15.2 (A), R15.2
unnamed: LED16.2 (A), R16.2
unnamed: LED17.2 (A), R17.2
unnamed: LED18.2 (A), R18.2
unnamed: LED19.2 (A), R19.2
unnamed: LED20.2 (A), R20.2
unnamed: LED21.2 (A), R21.2
unnamed: LED22.2 (A), R22.2
unnamed: LED23.2 (A), R23.2
unnamed: LED24.2 (A), R24.2
unnamed: LED25.2 (A), R25.2
unnamed: LED26.2 (A), R26.2
unnamed: LED27.2 (A), R27.2
unnamed: LED28.2 (A), R28.2
unnamed: LED29.2 (A), R29.2
unnamed: LED30.2 (A), R30.2
unnamed: LED31.2 (A), R31.2
unnamed: LED32.2 (A), R32.2
unnamed: LED33.2 (A), R33.2
unnamed: LED34.2 (A), R34.2
unnamed: LED35.2 (A), R35.2
unnamed: LED36.2 (A), R36.2
unnamed: LED37.2 (A), R37.2
unnamed: LED38.2 (A), R38.2
unnamed: LED39.2 (A), R39.2
unnamed: LED40.2 (A), R40.2
unnamed: LED41.2 (A), R41.2
unnamed: LED42.2 (A), R42.2
unnamed: LED43.2 (A), R43.2
unnamed: LED44.2 (A), R44.2
unnamed: LED45.2 (A), R45.2
unnamed: LED46.2 (A), R46.2
unnamed: LED47.2 (A), R47.2
unnamed: LED48.2 (A), R48.2
unnamed: LED49.2 (A), R49.2
unnamed: LED50.2 (A), R50.2
unnamed: LED51.2 (A), R51.2
unnamed: LED52.2 (A), R52.2
unnamed: LED53.2 (A), R53.2
unnamed: LED54.2 (A), R54.2
unnamed: LED55.2 (A), R55.2
unnamed: LED56.2 (A), R56.2
unnamed: LED57.2 (A), R57.2
unnamed: LED58.2 (A), R58.2
unnamed: LED59.2 (A), R59.2
unnamed: LED60.2 (A), R60.2
unnamed: LED61.2 (A), R61.2
unnamed: LED62.2 (A), R62.2
unnamed: LED63.2 (A), R63.2
unnamed: LED64.2 (A), R64.2
unnamed: LED65.2 (A), R65.2
unnamed: LED66.2 (A), R66.2
unnamed: LED67.2 (A), R67.2
unnamed: LED68.2 (A), R68.2
unnamed: LED69.2 (A), R69.2
unnamed: LED70.2 (A), R70.2
unnamed: LED71.2 (A), R71.2
unnamed: LED72.2 (A), R72.2
VCC: C4.1, C5.1, C6.1, C7.1, C8.1, C9.1, C10.1, C11.1, C12.1, C13.1, C14.1, C15.1, C16.1, C17.1, C18.1, C19.1, R9.1, R10.1, R11.1, R12.1, R13.1, R14.1, R15.1, R16.1, R17.1, R18.1, R19.1, R20.1, R21.1, R22.1, R23.1, R24.1, R25.1, R26.1, R27.1, R28.1, R29.1, R30.1, R31.1, R32.1, R33.1, R34.1, R35.1, R36.1, R37.1, R38.1, R39.1, R40.1, R41.1, R42.1, R43.1, R44.1, R45.1, R46.1, R47.1, R48.1, R49.1, R50.1, R51.1, R52.1, R53.1, R54.1, R55.1, R56.1, R57.1, R58.1, R59.1, R60.1, R61.1, R62.1, R63.1, R64.1, R65.1, R66.1, R67.1, R68.1, R69.1, R70.1, R71.1, R72.1, U3.1 (A->B), U3.20 (VCC), U4.10 (~SRCLR), U4.16 (VCC), U5.1 (A->B), U5.20 (VCC), U6.10 (~SRCLR), U6.16 (VCC), U7.1 (A->B), U7.20 (VCC), U8.10 (~SRCLR), U8.16 (VCC), U9.1 (A->B), U9.20 (VCC), U10.10 (~SRCLR), U10.16 (VCC), U11.1 (A->B), U11.20 (VCC), U12.10 (~SRCLR), U12.16 (VCC), U13.1 (A->B), U13.20 (VCC), U14.10 (~SRCLR), U14.16 (VCC), U15.1 (A->B), U15.20 (VCC), U16.10 (~SRCLR), U16.16 (VCC), U17.1 (A->B), U17.20 (VCC), U18.10 (~SRCLR), U18.16 (VCC); also elsewhere on the board

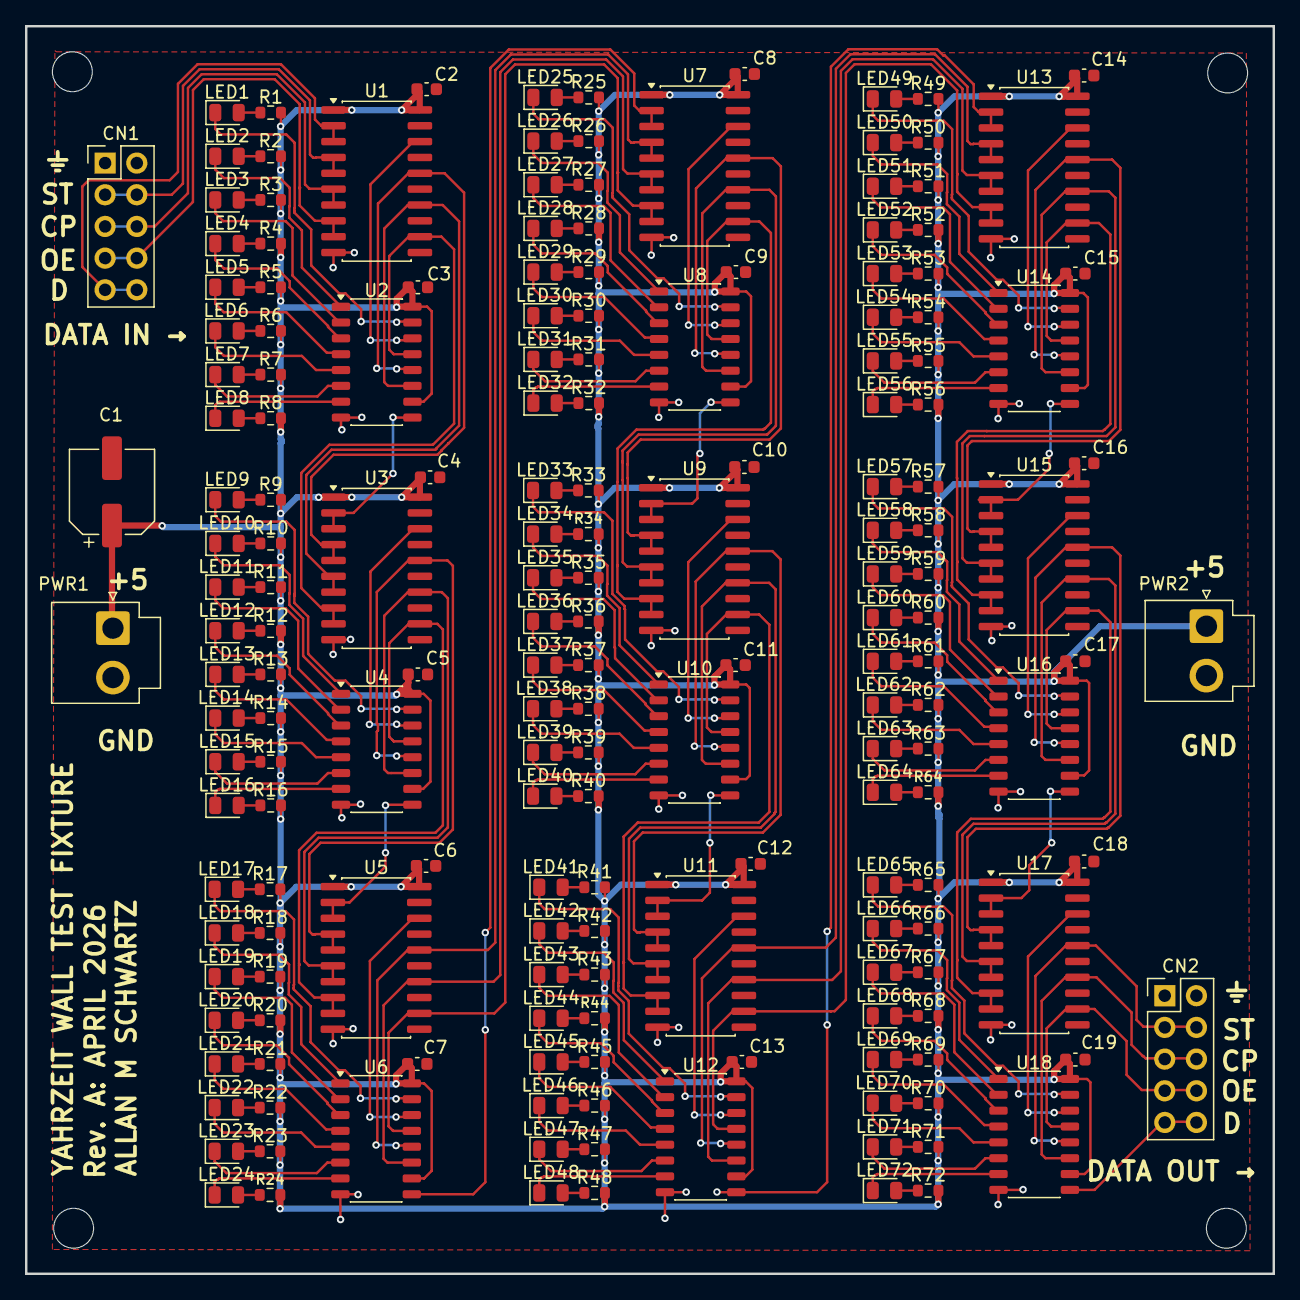
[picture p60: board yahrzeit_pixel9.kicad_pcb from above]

Board: 2 copper layers, 100.0 x 100.0 mm, 185 parts (0 on the bottom side), 195 nets.

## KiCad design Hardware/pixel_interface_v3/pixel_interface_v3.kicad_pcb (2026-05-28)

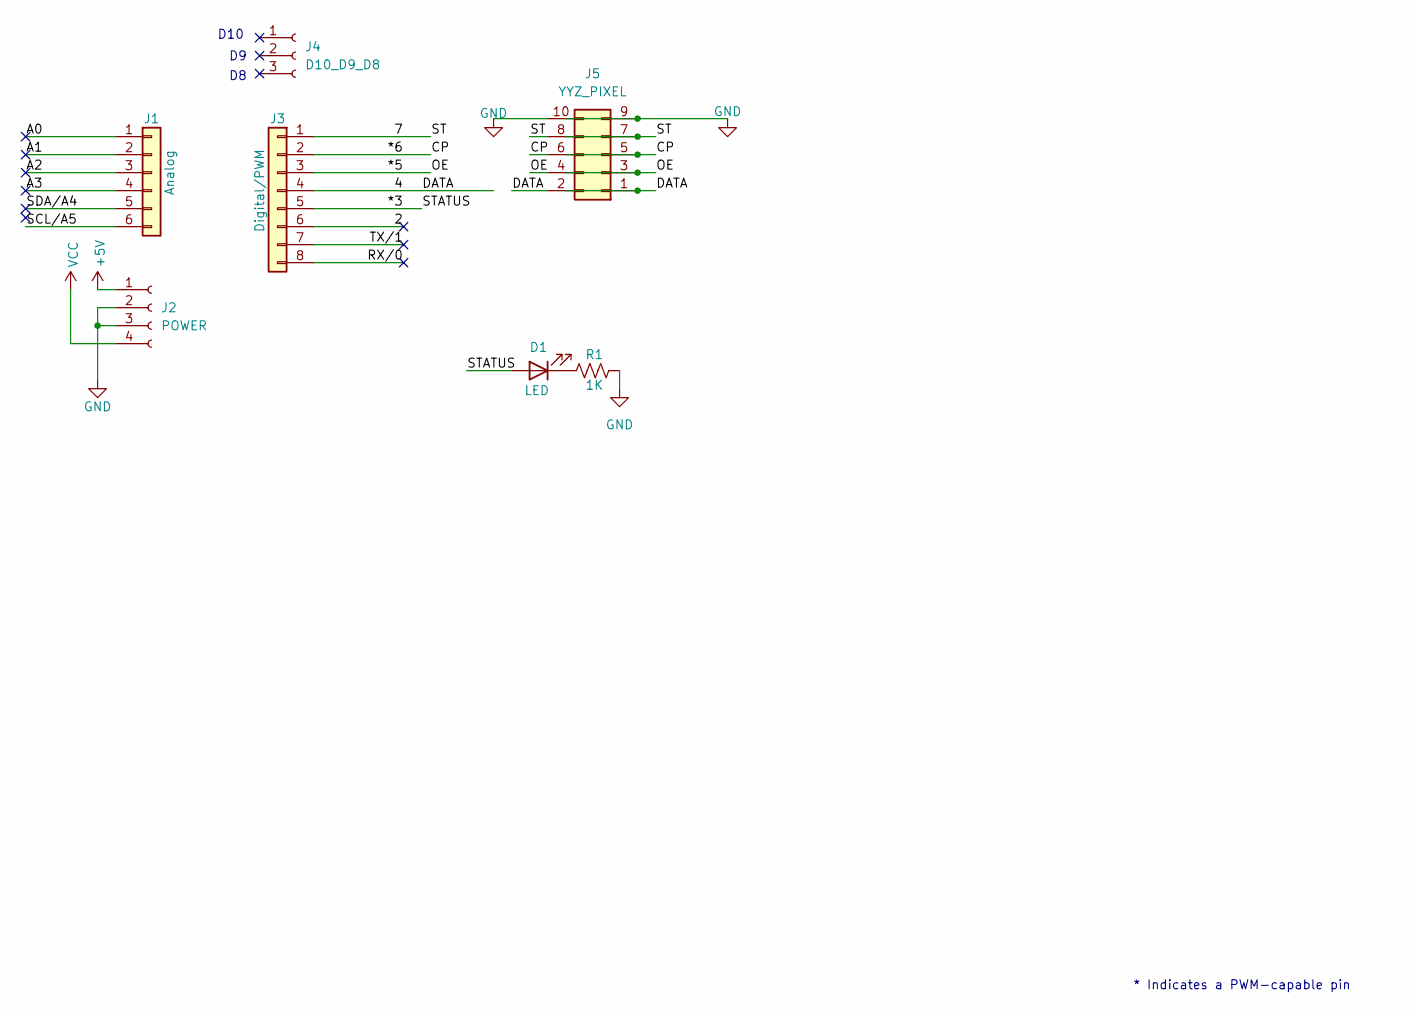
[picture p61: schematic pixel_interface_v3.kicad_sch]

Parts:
D1: LED; LED_D3.0mm
J1: Analog; PinSocket_1x06_P2.54mm_Vertical
J2: POWER; PinSocket_1x04_P2.54mm_Vertical
J3: Digital/PWM; PinSocket_1x08_P2.54mm_Vertical
J4: D10_D9_D8; PinSocket_1x03_P2.54mm_Vertical
J5: YYZ_PIXEL; PinHeader_2x05_P2.54mm_Horizontal
R1: 1K; LED_1206_3216Metric_Pad1.42x1.75mm_HandSolder

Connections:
+5V: J2.1
/2: J3.6
/4: J3.4, J5.1, J5.2
/7: J3.1, J5.7, J5.8
/*3: D1.2 (A), J3.5
/*5: J3.3, J5.3, J5.4
/*6: J3.2, J5.5, J5.6
/A0: J1.1
/A1: J1.2
/A2: J1.3
/A3: J1.4
/RX/0: J3.8
/SCL/A5: J1.6
/SDA/A4: J1.5
/TX/1: J3.7
GND: J2.2, J2.3, J5.9, J5.10, R1.2
unnamed: D1.1 (K), R1.1
VCC: J2.4

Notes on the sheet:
* Indicates a PWM-capable pin
D10

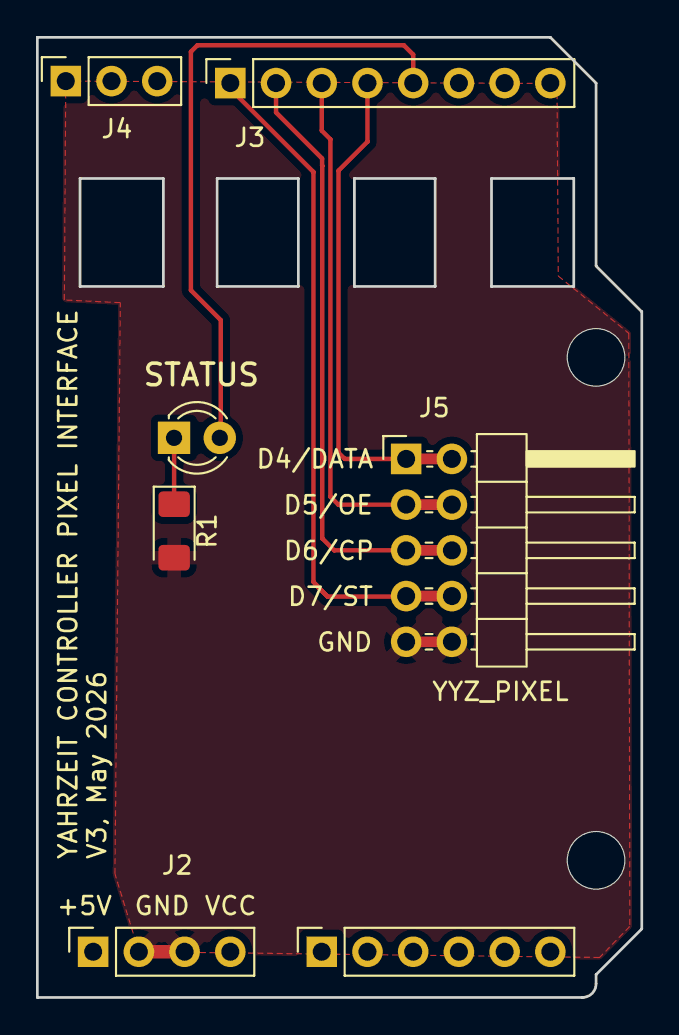
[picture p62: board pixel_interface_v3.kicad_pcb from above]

Board: 2 copper layers, 33.6 x 53.3 mm, 9 parts (0 on the bottom side), 7 nets.

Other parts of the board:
MH3, MH4: MountingHole_3.2mm

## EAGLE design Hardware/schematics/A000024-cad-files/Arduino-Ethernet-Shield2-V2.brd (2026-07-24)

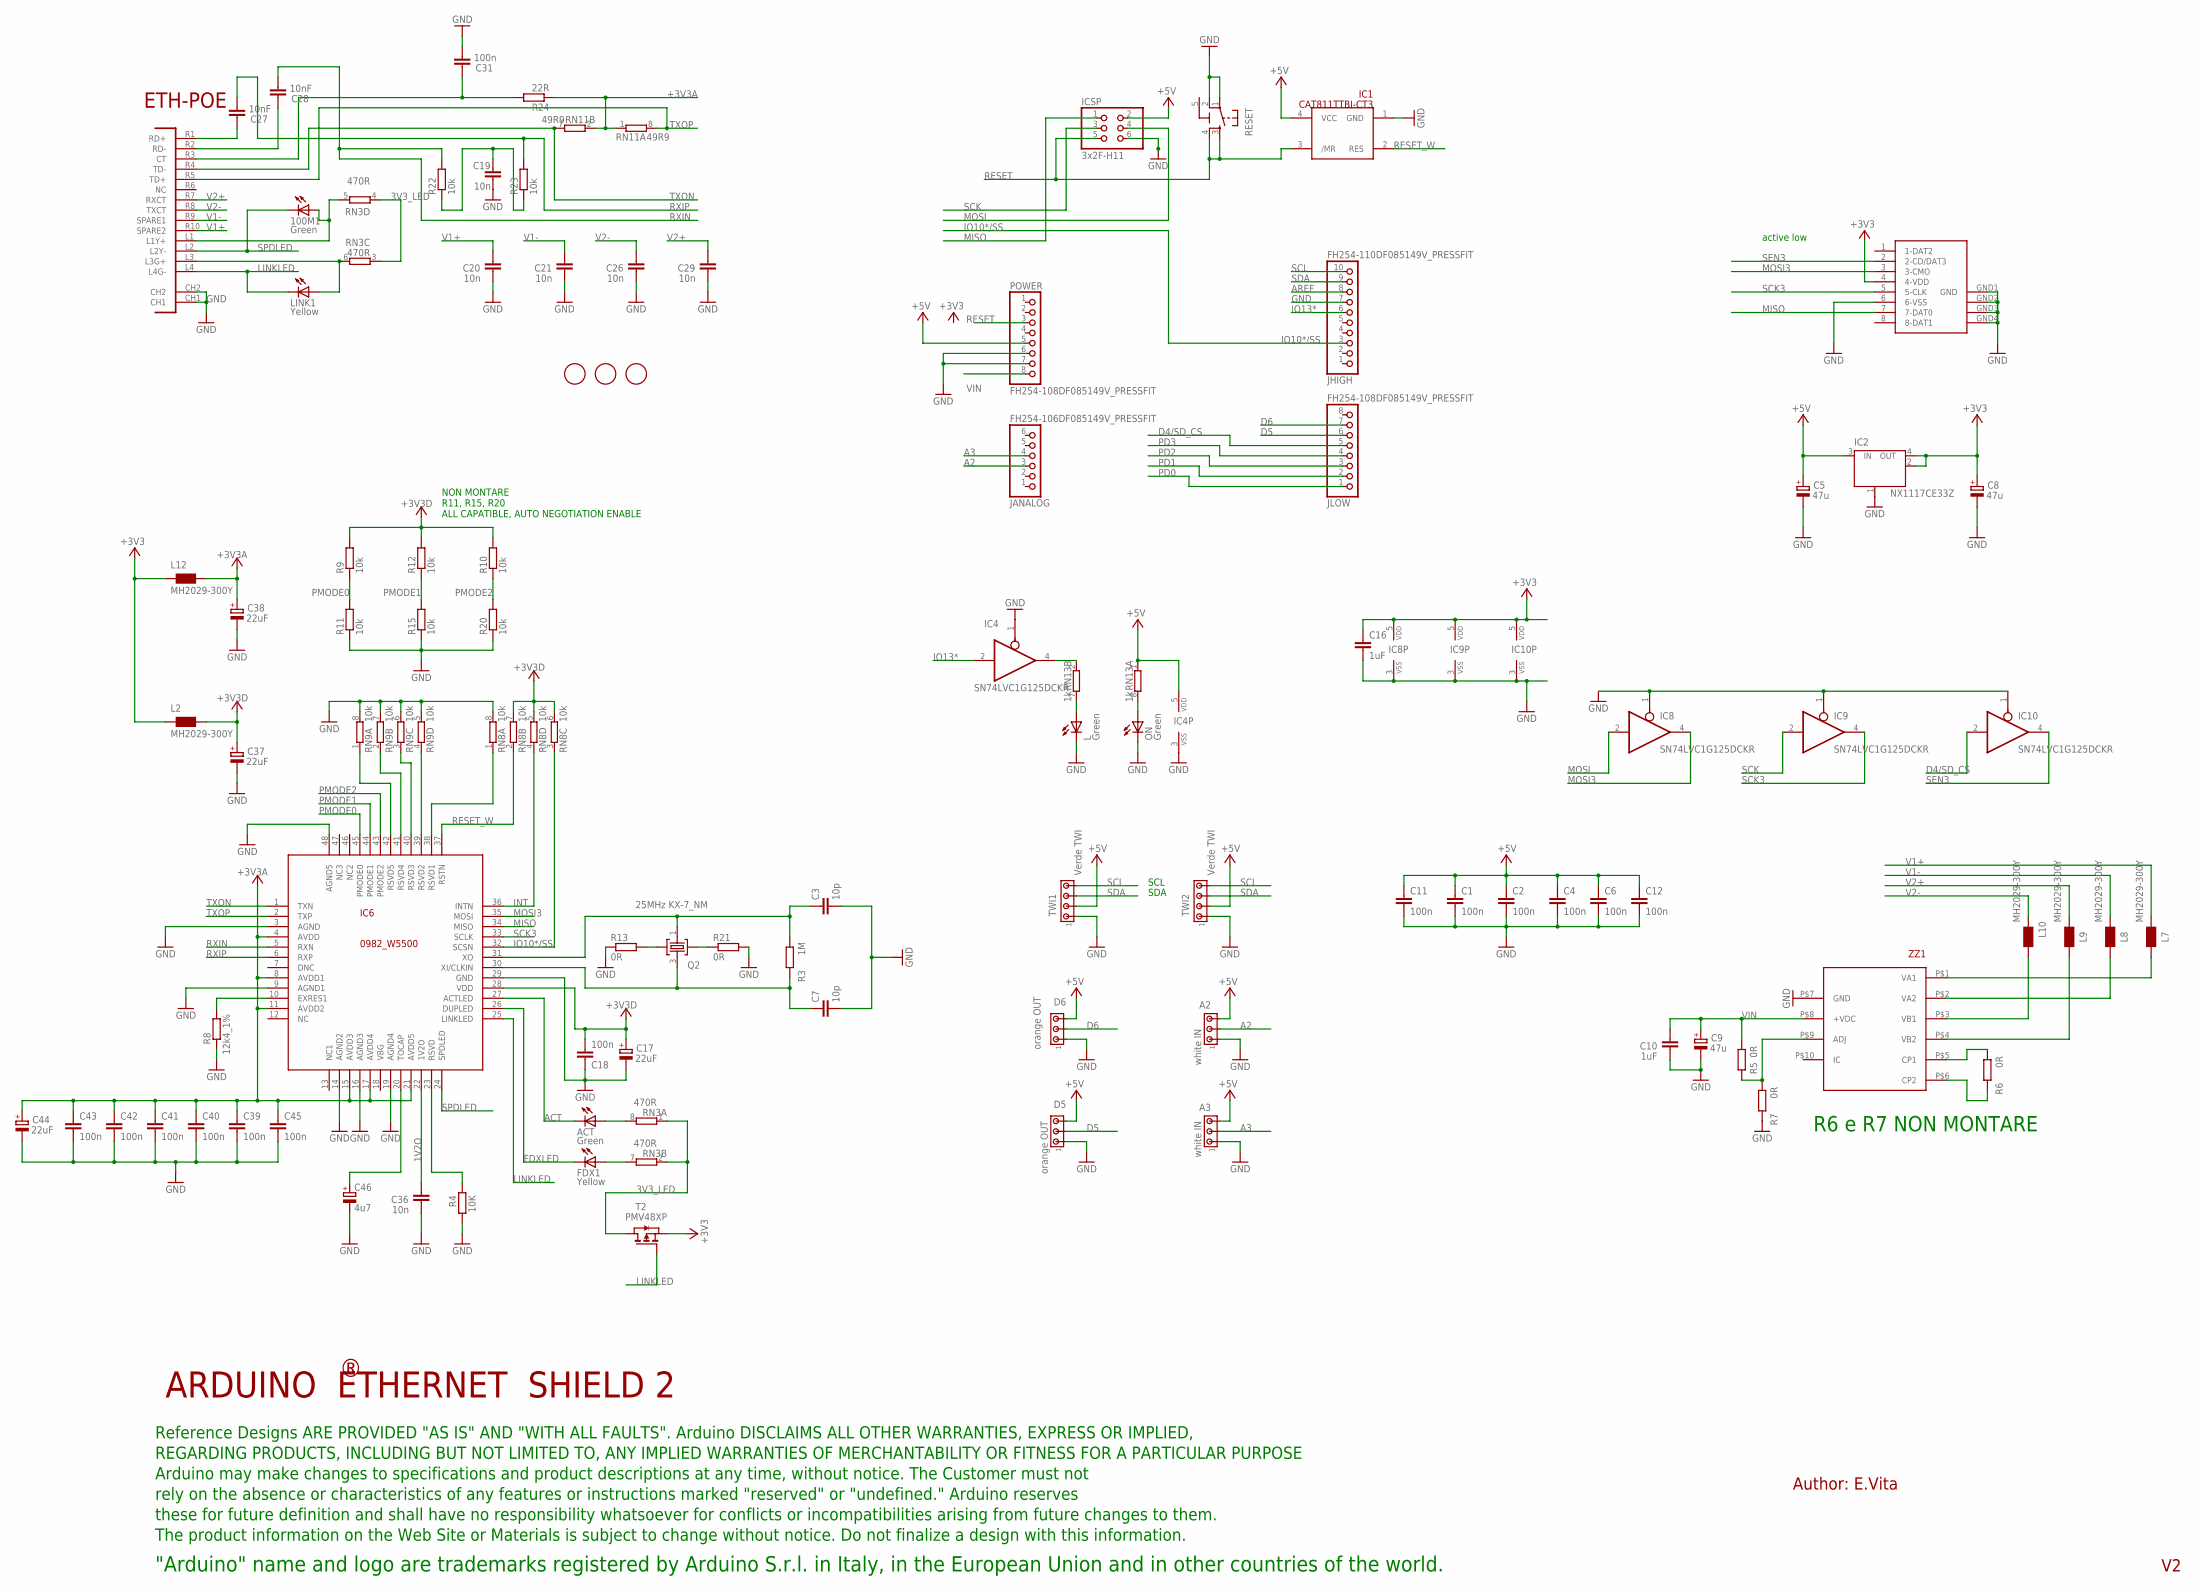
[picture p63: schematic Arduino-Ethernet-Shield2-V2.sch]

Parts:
100M1: Green; CHIPLED_0805
A2, A3: white IN; 10X03MTA
ACT: Green; CHIPLED_0805
C1, C2, C4, C6, C11, C12, C18, C31, C39, C40, C41, C42, C43, C45: 100n; C0603-ROUND
C3, C7: 10p; C0603-ROUND
C5, C8, C9: 47u; PANASONIC_D
C10, C16: 1uF; C0603-ROUND
C17, C37, C38, C44: 22uF; SMC_B
C19, C20, C21, C26, C29, C36: 10n; C0603-ROUND
C27, C28: 10nF; C0603-ROUND
C46: 4u7; SMC_A
D5, D6: orange OUT; 10X03MTA
FDX1: Yellow; CHIPLED_0805
FID2, FID3, FID4: FIDUCIALMOUNT; FIDUCIA-MOUNT
IC1: CAT811TTBI-CT3; SOT143
IC2: NX1117CE33Z; SOT223
IC4, IC8, IC9, IC10: SN74LVC1G125DCKR; SC70-5
IC6: 0982_W5500; TQFP48-7X7
ICSP: 3x2F-H11; 2X03
JANALOG: FH254-106DF085149V_PRESSFIT; 1X06-TH-PRESSFIT
JHIGH: FH254-110DF085149V_PRESSFIT; 1X10-TH-PRESSFIT
JLOW: FH254-108DF085149V_PRESSFIT; 1X08-TH-PRESSFIT
L: Green; CHIPLED_0805
L2, L7, L8, L9, L10, L12: MH2029-300Y; 0805
LINK1: Yellow; CHIPLED_0805
ON: Green; CHIPLED_0805
POWER: FH254-108DF085149V_PRESSFIT; 1X08-TH-PRESSFIT
Q2: 25MHz KX-7_NM; CRYSTAL3.2X2.5
R3: 1M; R0603-ROUND
R4: 10K; R0603-ROUND
R5, R6, R7: 0R; R0603-ROUND
R8: 12k4_1%; R0603-ROUND
R9, R10, R11, R12, R15, R20, R22, R23: 10k; R0603-ROUND
R13, R21: 0R; R0402
R24: 22R; R0603-ROUND
RESET: 0946_TS42031-160W-TR-7260; TS42
RN3: 470R; CAY16
RN8, RN9: 10k; CAY16
RN11: 49R9; CAY16
RN13: 1k; CAY16
T2: PMV48XP; SOT-23; PART_NUMBER PMV48XP
TWI1, TWI2: Verde TWI; 10X04MTA
U$1: DISCLAIMER
UC1: RB1-125BHQ1A; POE-RJ45
X1: 0046_15TW-882; SDCARD-15TW-8821
ZZ1: 0343_AG9612-2BR; AG9000

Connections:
1V2O: C36.2, IC6.22 (1V2O)
3V3_LED: RN3.1, RN3.2 (1), RN3.3 (1), RN3.4 (1), T2.1 (D)
5-GND: RESET.5 (5-GND)
+3V3: C8.+, C16.1, IC2.2 (OUT), IC2.4 (OUT), IC8.5 (VDD), IC9.5 (VDD), IC10.5 (VDD), L2.1, L12.1, T2.2 (S), X1.4 (4-VDD)
+3V3A: C38.+, C39.1, C40.1, C41.1, C42.1, C43.1, C44.+, C45.1, IC6.4 (AVDD), IC6.8 (AVDD1), IC6.11 (AVDD2), IC6.15 (AVDD3), IC6.17 (AVDD4), IC6.21 (AVDD5), L12.2, R24.1, RN11.1, RN11.2 (1)
+3V3D: C17.+, C18.2, C37.+, IC6.28 (VDD), L2.2, R9.2, R10.2, R12.2, RN8.5 (2), RN8.6 (2), RN8.7 (2)
+5V: A2.3, A3.3, C1.1, C2.1, C4.1, C5.+, C6.1, C11.1, C12.1, D5.3, D6.3, IC1.4 (VCC), IC2.3 (IN), IC4.5 (VDD), ICSP.2, POWER.5, RN13.1, TWI1.2, TWI2.2
A2: A2.2, JANALOG.3
A3: A3.2, JANALOG.4
ACT: ACT.C, IC6.27 (ACTLED)
AREF: JHIGH.8
D4/SD_CS: IC10.2 (I), JLOW.5
D5: D5.2, JLOW.6
D6: D6.2, JLOW.7
FDXLED: FDX1.C, IC6.26 (DUPLED)
GND: A2.1, A3.1, C1.2, C2.2, C3.2, C4.2, C5.-, C6.2, C7.2, C8.-, C9.-, C10.1, C11.2, C12.2, C16.2, C17.-, C18.1, C19.1, C20.1, C21.1, C26.1, C29.1, C31.1, C36.1, C37.-, C38.-, C39.2, C40.2, C41.2, C42.2, C43.2, C44.-, C45.2, C46.-, D5.1, D6.1, IC1.1 (GND), IC2.1 (GND/ADJ), IC4.1 (OE), IC4.3 (VSS), IC6.3 (AGND), IC6.9 (AGND1), IC6.14 (AGND2), IC6.16 (AGND3), IC6.19 (AGND4), IC6.29 (GND), IC6.48 (AGND5), IC8.1 (OE), IC8.3 (VSS), IC9.1 (OE), IC9.3 (VSS), IC10.1 (OE), IC10.3 (VSS), ICSP.6, JHIGH.7, L.C, ON.C, POWER.6, POWER.7, R4.1, R7.2, R8.1, R11.1, R13.1, R15.1, R20.1, R21.2, RESET.1, RESET.2, RN8.8 (2), RN9.5 (2), RN9.6 (2), RN9.7 (2), RN9.8 (2), TWI1.1, TWI2.1, UC1.CH1, UC1.CH2, X1.6 (6-VSS), X1.GND1 (GND), X1.GND2 (GND1), X1.GND3 (GND2), X1.GND4 (GND3), ZZ1.P$7 (GND)
INT: IC6.36 (INTN), RN8.4 (1)
IO10*/SS: IC6.32 (SCSN), JHIGH.3, RN8.3 (1)
IO13*: IC4.2 (I), JHIGH.6
LINKLED: IC6.25 (LINKLED), LINK1.C, T2.3 (G), UC1.L4 (L4G-)
MISO: IC6.34 (MISO), ICSP.1, X1.7 (7-DAT0)
MOSI: IC8.2 (I), ICSP.4
MOSI3: IC6.35 (MOSI), IC8.4 (O), X1.3 (3-CMO)
unnamed: L7.2, ZZ1.P$1 (VA1)
unnamed: L8.2, ZZ1.P$2 (VA2)
unnamed: L9.2, ZZ1.P$4 (VB2)
unnamed: L10.2, ZZ1.P$3 (VB1)
unnamed: C3.1, IC6.31 (XO), Q2.1, R3.1
unnamed: IC6.39 (RSVD2), RN9.4 (1)
unnamed: ACT.A, RN3.8 (2)
unnamed: Q2.2, R13.2
unnamed: Q2.4, R21.1
unnamed: LINK1.A, RN3.6 (2), UC1.L3 (L3G+)
unnamed: IC6.23 (RSVD), R4.2
unnamed: 100M1.A, RN3.5 (2), UC1.L1 (L1Y+)
unnamed: C19.2, R22.1, R23.1
unnamed: C27.2, UC1.R1 (RD+)
unnamed: C28.2, UC1.R2 (RD-)
unnamed: FDX1.A, RN3.7 (2)
unnamed: IC6.40 (RSVD3), RN9.3 (1)
unnamed: R6.1, ZZ1.P$5 (CP1)
unnamed: R6.2, ZZ1.P$6 (CP2)
unnamed: R5.2, R7.1, ZZ1.P$9 (ADJ)
unnamed: IC6.41 (RSVD4), RN9.2 (1)
unnamed: C31.2, R24.2, UC1.R3 (CT)
unnamed: IC6.42 (RSVD5), RN9.1
unnamed: C46.+, IC6.20 (TOCAP)
unnamed: IC6.38 (RSVD1), RN8.1
unnamed: IC6.10 (EXRES1), R8.2
unnamed: ON.A, RN13.8 (2)
unnamed: IC4.4 (O), RN13.2 (1)
unnamed: L.A, RN13.7 (2)
NC: IC6.12 (NC)
OSC2E2: C7.1, IC6.30 (XI/CLKIN), Q2.3, R3.2
PD0: JLOW.1
PD1: JLOW.2
PD2: JLOW.3
PD3: JLOW.4
PMODE0: IC6.45 (PMODE0), R9.1, R11.2
PMODE1: IC6.44 (PMODE1), R12.1, R15.2
PMODE2: IC6.43 (PMODE2), R10.1, R20.2
RESET: IC1.3 (/MR), ICSP.5, POWER.3, RESET.3, RESET.4
RESET_W: IC1.2 (RES), IC6.37 (RSTN), RN8.2 (1)
RXIN: C28.1, IC6.5 (RXN), R22.2
RXIP: C27.1, IC6.6 (RXP), R23.2
SCK: IC9.2 (I), ICSP.3
SCK3: IC6.33 (SCLK), IC9.4 (O), X1.5 (5-CLK)
SCL: JHIGH.10, TWI1.4, TWI2.4
SDA: JHIGH.9, TWI1.3, TWI2.3
SEN3: IC10.4 (O), X1.2 (2-CD/DAT3)
SPDLED: 100M1.C, IC6.24 (SPDLED), UC1.L2 (L2Y-)
TXON: IC6.1 (TXN), RN11.7 (2), UC1.R4 (TD-)
TXOP: IC6.2 (TXP), RN11.8 (2), UC1.R5 (TD+)
V1+: C20.2, L7.1, UC1.R10 (SPARE2)
V1-: C21.2, L8.1, UC1.R9 (SPARE1)
V2+: C29.2, L9.1, UC1.R7 (RXCT)
V2-: C26.2, L10.1, UC1.R8 (TXCT)
VIN: C9.+, C10.2, POWER.8, R5.1, ZZ1.P$8 (+VDC)

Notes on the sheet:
active low
NON MONTARE R11, R15, R20 ALL CAPATIBLE, AUTO NEGOTIATION ENABLE
ETH-POE
SCL
SDA
R6 e R7 NON MONTARE
ARDUINO ETHERNET SHIELD 2
Author: E.Vita

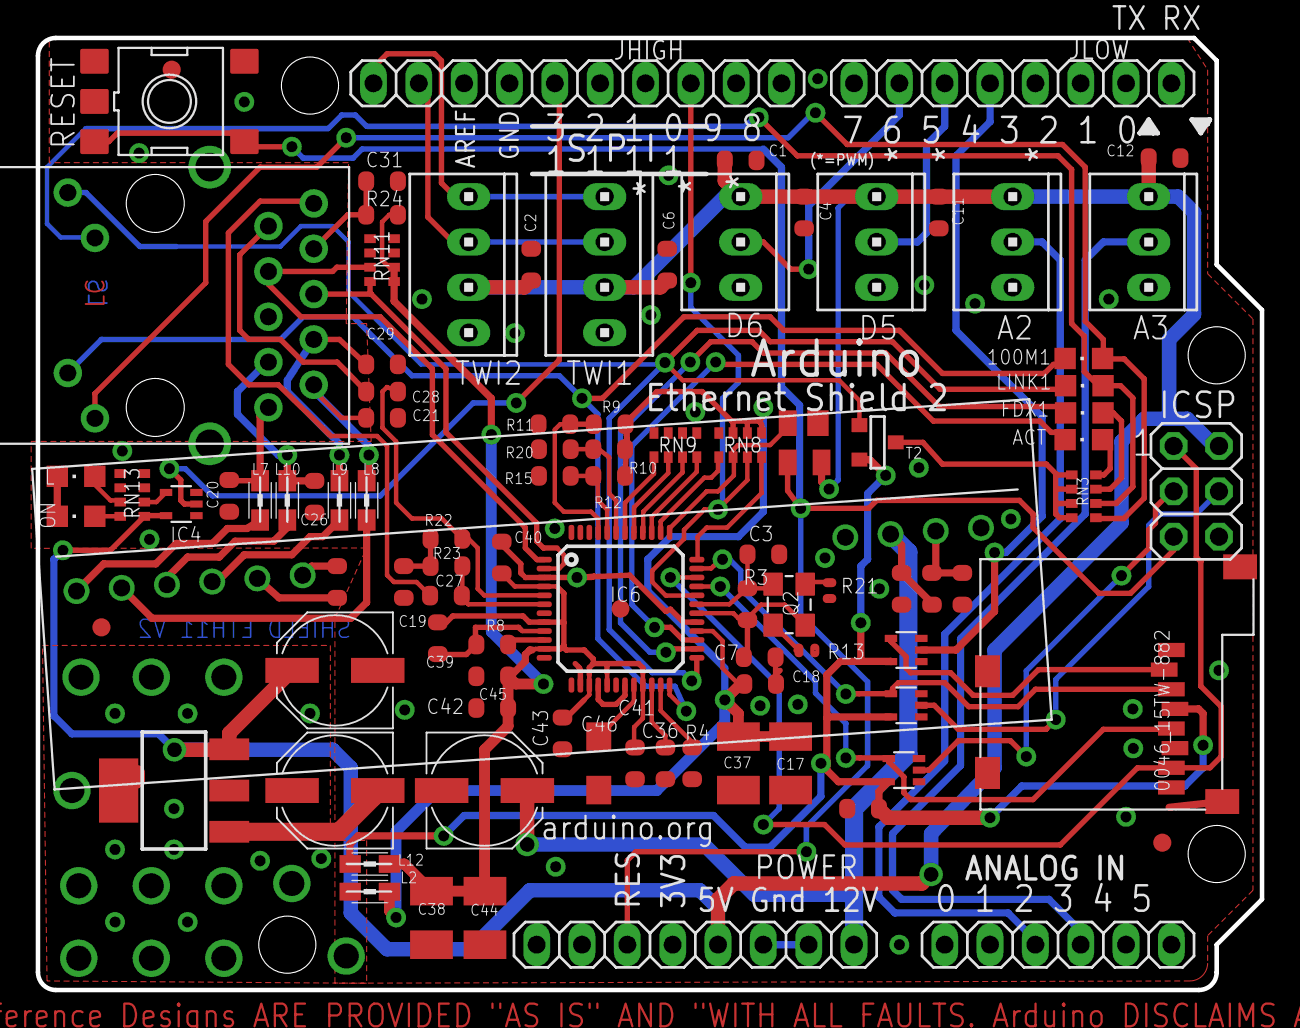
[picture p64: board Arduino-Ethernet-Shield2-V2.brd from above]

Board: 2 copper layers, 68.6 x 53.3 mm, 96 parts (0 on the bottom side), 71 nets.

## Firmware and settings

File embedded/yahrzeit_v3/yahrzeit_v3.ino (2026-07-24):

/**
 * @file        yahrzeit_v3.ino
 *
 * @brief       Top-level configuration, startup, and cooperative main loop
 *              for the Yahrzeit Embedded Controller.
 *
 * @history     version 1.0 created for Congregation Beth Sholom, 2007-2008
 *              version 2.0 revised in July 2015
 *              version 3.0 revised in April 2026
 *
 * @author      Allan M. Schwartz, allanschwartz@sbcglobal.net
 *
 * @copyright   copyright (c) 2008,2015,2026, by Allan M. Schwartz
 *              All rights reserved.
 *
 * @notes       see project notes in file yahrzeit_v3.h
 */

/**
 * ASSEMBLY
 * 
 *       The Yahrzeit Controller stack is built on an Arduino Uno R4
 *       Minima as the base, then the Ethernet Shield 2, and finally
 *       the Yahrzeit Controller Pixel Interface board on top.   The
 *       Yahrzeit Controller Pixel Interface board connects with a
 *       ribbon cable to the YYZ Pixel board(s) which drive the LED
 *       wall.
 *
 *      Using the TEST_FIXTURE board(s)
 *          Each fixture board contains 24 rows x 3 columns of pixels.
 *
 *              TEST FIXTURE SIGNAL: DI  OE  CP  ST
 *              Arduino Uno pin:     4   5   6   7
 *
 *
 *      Using the YYZ Pixel boards
 *          The CBS Yahrzeit Wall is represented as a 56-row x 40-column
 *          logical display. LedWall.cpp defines how its 21 physical memorial
 *          panels map into that coordinate space.
 *
 *          V3 system (Arduino Uno R4 Minima)
 *
 *              YYZ PIXEL SIGNAL:    DI  OE  CP  ST
 *              Arduino Uno pin:     4   5   6   7
 *
 *      The Ethernet Shield 2 uses the Arduino Uno SPI interface:
 *              D10 CS, D11 COPI, D12 CIPO, D13 SCK
 * 
 *      The Yahrzeit Controller Pixel Interface board has an ALIVE status LED
 *      connected to pin 3.
 */

#include <Arduino.h>
#include <math.h>
#include "yahrzeit_v3.h"


// ----------------------------------------------------------------------------
//            L E D   A R R A Y S
// ----------------------------------------------------------------------------

// support the physical interfaces to LED ARRAY

DisplayConfig displayConfig = {
    .nRows = 0,
    .nCols = 0,
    .brightness = 128,
    .nPanels = 0
};

// The ALIVE status LED is on the Yahrzeit Controller Pixel Interface board and
// is connected to Arduino Uno R4 Minima pin D3.
static constexpr byte STATUS_LED_PIN = 3;
static constexpr byte STATUS_LED_BRIGHTNESS = 128; // 50% PWM duty cycle
static constexpr unsigned long ALIVE_PERIOD_MS = 2560;

// Controller V3 pin definitions: Arduino Uno R4 Minima.
// Names match the YYZ Pixel Interface board silkscreen: DI, OE, CP, ST.
static constexpr byte
     DI_PIN = 4,       // Data input
     OE_PIN = 5,       // Output enable, active LOW
     CP_PIN = 6,       // Clock pulse
     ST_PIN = 7;       // Store/latch pulse


// create an instance of the YyzPixels class, giving us the YyzPixels primitives
YyzPixel yyzPixels( DI_PIN, OE_PIN, CP_PIN, ST_PIN );

// create an instance of the LedWall class, giving us the LedWall primitives
LedWall ledWall(yyzPixels);

// create an instance of the CmdProc class, giving us the CmdProc primitives
CmdProc cmdProc(ledWall);

// ----------------------------------------------------------------------------
//            E T H E R N E T
// ----------------------------------------------------------------------------

// Locally administered MAC address and static IPv4 settings. Confirm the
// selected production or lab values before uploading firmware.

NetworkConfig networkConfig = {
    .mac = { 0x02, 0x19, 0x55, 0x11, 0x00, 0x09 },          // 1955-11-09
    #if CBS_56x40_WALL
        // Values used at Congregation Beth Sholom
        .ipAddr = IPAddress(192, 168, 13, 9),
        .dnsAddr = IPAddress(8, 8, 8, 8),
        .gateway = IPAddress(192, 168, 13, 8),
        .subnet = IPAddress(255, 255, 255, 0),
    #else 
        // Values used at Allan's home lab
        .ipAddr = IPAddress(192, 168, 86, 240),
        .dnsAddr = IPAddress(8, 8, 8, 8),
        .gateway = IPAddress(192, 168, 86, 1),
        .subnet = IPAddress(255, 255, 255, 0),
    #endif
    .wifiSsid = {},
    .wifiPassword = {}
};

// TCP command port used by the PHP appliance's bin/yahrzeit wrapper through nc.
EthernetServer socket(SOCKET_LISTEN_PORT);
EthernetClient socketClient;

// ----------------------------------------------------------------------------
//            G L O B A L   S T O R A G E
// ----------------------------------------------------------------------------

char outputBuf[512] {};

bool timingOutputEnabled = false;

bool debugPixel = false;

static void breathingLed();
[[noreturn]] static void blinkPanicLedThenRestart();

/**
 * @brief   Format the firmware release identifier and compilation date/time.
 *
 * @returns pointer to shared outputBuf, overwritten by later formatting
 */
const char *versionText()
{
    snprintf(outputBuf, sizeof outputBuf,
             "\tYahrzeit Embedded Controller, release %s\n"
             "\tbuilt %s %s\n"
             "\tcopyright (c) 2008,2015,2026 AMS Consulting\n",
             FIRMWARE_RELEASE,
             __DATE__,
             __TIME__);

    return outputBuf;
}


// ----------------------------------------------------------------------------
//           M A I N
// ----------------------------------------------------------------------------

/**
 * @brief   Initialize the wall, run the visible startup tests, then restore
 *          and display the framebuffer saved in EEPROM.
 *
 * This is called after the serial, Ethernet, and command socket interfaces
 * have been initialized by setup().
 */
static void controllerBegin()
{
    yyzPixels.begin();
    ledWall.begin();
    serialLog( "LED wall up\n" );

    // splash
    writeOutput( CONSOLE, versionText() );

    // some initial pattern, on power-up (as a self-test)
    serialLog( "light test" );
    (void)ledWall.allOn( 1, PANEL0 );
    sleepMs(true, 1500);
    (void)ledWall.allOn( 0, PANEL0 );
    sleepMs(true, 1500);
    selftestMarchingRow( PANEL0 );
    sleepMs(true, 1500);

    // Restore the last explicitly saved display pattern.
    ledWall.loadPixels();
    
    // and refresh
    ledWall.refresh();

    serialLog( "ready >" );
}

/**
 * @brief   Initialize the ALIVE LED, serial console, Ethernet interface,
 *          command socket, and LED wall once at startup.
 */
void setup()
{
    pinMode(STATUS_LED_PIN, OUTPUT);
    analogWrite(STATUS_LED_PIN, STATUS_LED_BRIGHTNESS);

    // initialize the serial console logic thread
    serialInit();
    serialLog( "Serial up" );
    
    // initialize the Ethernet
    ethernetInit();
    serialLog( "Ethernet up" );

    // start listening for socket clients to connect
    socketInit();
    controllerBegin();
}

/**
 * @brief   Cooperatively service serial input, socket input, and the ALIVE
 *          LED animation.
 */
void loop()
{
    serialThread();
    socketThread();
    breathingLed();

    delay(10);          // pause 10ms, to avoid pounding the SPI bus with continuous Ethernet polling
}

/**
 * @brief   Drive the ALIVE status LED through one smooth breathing cycle.
 *
 * The animation confirms that the cooperative main loop is running. It does
 * not indicate Ethernet or command-socket health.
 */
static void breathingLed()
{
    constexpr float TWO_pi = 6.28318530718f;                    /* keep phase math in float */
    unsigned long elapsedMs = millis() % ALIVE_PERIOD_MS;       /* time:    [0..Period)  */
    float phase = TWO_pi * (float)elapsedMs / ALIVE_PERIOD_MS;  /* radians: [0.0 .. 2π) */
    float sinePhase = sinf(phase);                              /* plotted as a sine wave */
    float intensity = (sinePhase + 1.0f) / 2.0f;                /* scaled to [0.0 .. 1.0] */
    int pwmValue = intensity * STATUS_LED_BRIGHTNESS;           /* int: [0..STATUS_LED_BRIGHTNESS] */

    analogWrite(STATUS_LED_PIN, pwmValue);
}

/**
 * @brief   Write one string, unchanged, to the selected output stream.
 *
 * @param streamID    display output on the SOCKET or CONSOLE
 * @param msg         null-terminated string; no newline is added
 */
void writeOutput( byte streamID, const char *msg )
{
    switch ( streamID ) {
        case SOCKET:
            if (socketClient && socketClient.connected()) { 
                socketClient.write( msg );
            }
            break;
            
        case CONSOLE:
            if (Serial) {
                Serial.write( msg );
            }
            break;
    }
}

/** 
 * @brief   Optionally refresh the display, then block for a fixed interval.
 *
 * @param doRefresh   should we do a refresh, before we start the sleep?
 * @param ms          number of milliseconds to delay
 */
void sleepMs( bool doRefresh, const unsigned int ms )
{
    if ( doRefresh) {
        ledWall.refresh();
    }
        
    delay(ms);
}   

/** 
 * @brief   Report a failed assertion, signal panic, and restart.
 *
 * @param expr   a text description of the expression which failed
 * @param file   where the panic originated from
 * @param line   and on which line number
 *
 * @note This function does not return. It uses the ALIVE LED as a panic
 *       indicator for five minutes before resetting the controller.
 */
[[noreturn]] void panic(const char *expr, const char *file, int line)
{
    if (Serial) {
        Serial.print("\n***PANIC***\nASSERT: ");
        Serial.println(expr);
        Serial.print("FILE: ");
        Serial.println(file);
        Serial.print("LINE: ");
        Serial.println(line);
        Serial.flush();
    }

    blinkPanicLedThenRestart();
}

/**
 * @brief   Report a failed assertion with formatted diagnostic context,
 *          signal panic, and restart.
 *
 * @param expr   text of the expression that failed
 * @param file   source file containing the assertion
 * @param line   source line containing the assertion
 * @param fmt    printf-style format for additional context
 *
 * @note This function does not return.
 */
[[noreturn]] void panicContext(const char *expr, const char *file, int line,
                               const char *fmt, ...)
{
    if (Serial) {
        Serial.print("\n***PANIC***\nASSERT: ");
        Serial.println(expr);
        Serial.print("FILE: ");
        Serial.println(file);
        Serial.print("LINE: ");
        Serial.println(line);
        Serial.print("DETAIL: ");

        va_list args;
        va_start(args, fmt);
        char buffer[128];
        vsnprintf(buffer, sizeof buffer, fmt, args);
        va_end(args);

        Serial.println(buffer);
        Serial.flush();
    }

    blinkPanicLedThenRestart();
}


constexpr byte PANIC_MINUTES = 5;

/**
 * @brief   Blink the ALIVE LED for five minutes, then reset the controller.
 */
[[noreturn]] static void blinkPanicLedThenRestart()
{
    constexpr unsigned long BLINK_MS = 100;
    constexpr unsigned long PANIC_MS = PANIC_MINUTES * 60UL * 1000UL;
    const unsigned long startedAt = millis();

    pinMode(STATUS_LED_PIN, OUTPUT);

    while (millis() - startedAt < PANIC_MS) {
        analogWrite(STATUS_LED_PIN, STATUS_LED_BRIGHTNESS);
        delay(BLINK_MS);
        analogWrite(STATUS_LED_PIN, 0);
        delay(BLINK_MS);
    }

    // not a standard Arduino function, but works on the Uno R4 Minima
    NVIC_SystemReset();

    while (true) {
    }
}

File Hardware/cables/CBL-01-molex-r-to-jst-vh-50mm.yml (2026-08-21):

# -----------------------------------------------------------------------------
# @file        CBL-01-molex-r-to-jst-vh-50mm.yml
#
# @brief       Legacy YYZ-PIXEL to YYZ Pixel V2 power adapter 01 cable.
#
#              Adapts a legacy YYZ-PIXEL POWER-OUT connector to the
#              JST VH 2-position power connector used on YYZ_PIXEL_V2.
#
#              The legacy connector uses only circuits 1 and 3.
#              Circuit 2 is intentionally unused.
#
# @history     version 1.0 created August 2026
#              version 1.1 corrected legacy connector identification
#              to Molex Mini-Fit Jr., August 2026
#
# @author      Allan M. Schwartz
#
# @copyright   copyright (c) 2026, by Allan M. Schwartz
#              All rights reserved.
#
# @notes       WireViz source file.
#
#              Legacy YYZ-PIXEL wiring:
#                Molex circuit 1 = +5V, red
#                Molex circuit 2 = not connected
#                Molex circuit 3 = GND, black
#
#              JST VH wiring:
#                pin 1 = +5V
#                pin 2 = GND
#
#              The Molex receptacle on this adapter mates with the
#              legacy 5559-series plug used for YYZ-PIXEL POWER-OUT.
#
#              Finished cable assembly is intended for manufacture by
#              PCBWay or equivalent cable-assembly vendor.
# -----------------------------------------------------------------------------


metadata:
  title: YYZ Pixel V2 Legacy Power Adapter 01
  revision: A
  description: >
    50 mm adapter cable from legacy YYZ-PIXEL POWER-OUT to JST VH.
    Molex Mini-Fit Jr. 3-circuit receptacle to JST VH 2-position receptacle.
    Connects +5V and GND only.


connectors:

  # Adapter connector which mates with the legacy YYZ-PIXEL POWER-OUT plug.
  #
  # Molex Mini-Fit Jr., 4.20 mm pitch, 3 circuits, single row.
  #
  # Only circuits 1 and 3 are populated.
  # Circuit 2 is intentionally unused.
  #
  # Housing:
  #   Molex 39-01-4030
  #   Engineering number 5557-03R2
  #
  # Contact:
  #   Molex 39-00-0039
  #   Mini-Fit female crimp terminal, 24-18 AWG, bag.

  J1:
    image:
        src: molex_5557-03R.JPG
        width: 200
        caption: Molex Mini-Fit Jr. 03R
    type: Molex Mini-Fit Jr.
    subtype: receptacle
    pincount: 3
    pinlabels: [+5V, NC, GND]
    manufacturer: Molex
    mpn: 39-01-4030
    notes: |
      for: <i>legacy <b>YYZ-PIXEL POWER-OUT</b></i>

    additional_components:
      - type: Female crimp contact
        qty: 2
        manufacturer: Molex
        mpn: 39-00-0039


  # New YYZ_PIXEL_V2 power connector.
  #
  # VHR-2N is the JST VH 2-position cable receptacle housing.
  # SVH-21T-P1.1 is the female crimp contact selected for 18 AWG wire.

  J2:
    image:
        src: JST_VHR-2N.png
        width: 200
    type: JST VH
    subtype: F cable receptacle
    pincount: 2
    pinlabels: [+5V, GND]
    manufacturer: JST
    mpn: VHR-2N
    notes: |
      for: <i><b>YYZ-PIXEL_V2 </b> end</i>

    additional_components:
      - type: Crimp contact
        qty_multiplier: populated
        manufacturer: JST
        mpn: SVH-21T-P1.1


cables:

  W1:
    category: bundle
    wirecount: 2
    gauge: 18 AWG
    length: 50 mm
    colors: [RD, BK]
    wirelabels: [+5V, GND]
    notes: |
      Finished Cable Length: 50 mm +/- 5 mm.

      • Measure length between the rear wire-exit
        faces of the two connector housings.

      • Use manufacturer-approved crimp tooling,
        or equivalent production crimp tooling.

      • Test assembly for continuity and polarity.


connections:

  # Legacy circuit 2 is intentionally unpopulated.
  #
  # J1 circuit 1 -> red wire   -> J2 pin 1
  # J1 circuit 3 -> black wire -> J2 pin 2

  -
    - J1: [1, 3]
    - W1: [1, 2]
    - J2: [1, 2]

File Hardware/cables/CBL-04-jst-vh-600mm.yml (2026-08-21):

# -----------------------------------------------------------------------------
# @file        CBL-04-jst-vh-600mm.yml
#
# @brief       YYZ Pixel V2 600 mm power feed cable.
#
#              Connects the Yahrzeit Wall power-distribution board to the
#              top YYZ_PIXEL_V2 board in a column.
#
#              Both ends use JST VH 2-position cable receptacles with
#              18 AWG stranded conductors.
#
# @history     version 1.0 created August 2026
#
# @author      Allan M. Schwartz
#
# @copyright   copyright (c) 2026, by Allan M. Schwartz
#              All rights reserved.
#
# @notes       WireViz source file.
#
#              Nominal length is based on the intended mechanical routing:
#              from the power-distribution board upward toward the hinge/
#              pivot area, through the cable-relief point, and then downward
#              to the power connector near the top of the YYZ_PIXEL_V2 board.
#
#              Red = +5V, Black = GND.
#              Finished cable assembly is intended for manufacture by
#              PCBWay or equivalent cable-assembly vendor.
# -----------------------------------------------------------------------------

metadata:
  title: YYZ Pixel V2 Power Feed
  revision: A
  description: >
    600 mm power feed cable from the Yahrzeit Wall power-distribution board
    to the top YYZ_PIXEL_V2 board in a column.
    JST VH receptacle housing on both ends.
    Straight-through +5V and GND wiring.


connectors:

  # Both ends mate with B2P-VH headers.
  #
  # One end connects to a +5V output on the power-distribution board.
  # The other end connects to the power input on the top YYZ_PIXEL_V2 board.
  #
  # VHR-2N is the 2-position JST VH cable receptacle housing.
  # SVH-21T-P1.1 is the female crimp contact selected for 18 AWG wire.

  J1:
    image:
        src: JST_VHR-2N.png
        caption: JST VHR-2N
        width: 200
    type: JST VH
    subtype: F cable receptacle
    pincount: 2
    pinlabels: [+5V, GND]
    manufacturer: JST
    mpn: VHR-2N
    notes: |
      PWR-DIST.-BOARD end

    additional_components:
      - type: Crimp contact
        qty_multiplier: populated
        manufacturer: JST
        mpn: SVH-21T-P1.1

  J2:
    type: JST VH
    subtype: F cable receptacle
    pincount: 2
    pinlabels: [+5V, GND]
    manufacturer: JST
    mpn: VHR-2N
    notes: |
      for: <i><b>YYZ-PIXEL_V2 </b> end</i>

    additional_components:
      - type: Crimp contact
        qty_multiplier: populated
        manufacturer: JST
        mpn: SVH-21T-P1.1


cables:

  # 18 AWG stranded copper wire was selected for low voltage drop,
  # mechanical robustness, and compatibility with the selected JST VH
  # crimp contact.
  #
  # This is a pair of discrete conductors, not a jacketed cable.
  #
  # The 600 mm finished length includes routing/service allowance for
  # the hinged aluminum panel installation.

  W1:
    category: bundle
    wirecount: 2
    gauge: 18 AWG
    length: 600 mm
    colors: [RD, BK]
    wirelabels: [+5V, GND]
    notes: |
      Finished Cable Length: 600 mm +/- 10 mm.

      • Measure length between the rear wire-exit 
        faces of the two connector housings.

      • Use JST-approved crimp tooling, or 
        equivalent production crimp tooling.

      • Test assembly for continuity and polarity.


connections:

  # Straight-through connection.
  #
  # J1 pin 1 -> red wire   -> J2 pin 1
  # J1 pin 2 -> black wire -> J2 pin 2

  -
    - J1: [1, 2]
    - W1: [1, 2]
    - J2: [1, 2]

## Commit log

2015-07-16 Yahrzeit Wall Server
    The Congregation Beth Shalom Yahrzeit wall system, consisting of server
    code, and embedded controller code.
    [controller BOM.xlsx, names-length.csv, newxxx.csv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]
2015-07-27 changes with Zach watching
    [yahrzeits -col_row.xls, yahrzeits all for a schwartz 011607.xls, yahrzeits-fixed.csv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]
2015-09-18 misc changes
    [controller BOM.xlsx]
2026-04-30 Refactor: introduce YyzPixel, LedWall, and CmdProc classes; fix layering; add panic handler; working console command processor; all self-tests passing
    [LedWall.cpp, YyzPixel.cpp, led_console.ino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]
2026-05-22 Archive current yahrzeit hardware and controller work
    [names-length.csv, newxxx.csv, panels.csv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]
2026-05-22 Separate live yahrzeit data from historical CSV files
    [names-length.csv, newxxx.csv, testing.csv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]
2026-05-24 nightly checkin
    [panels.csv]
2026-05-25 Add Yahrzeit reports and reorganize site support files
    [fixture_plate.scad]
2026-05-25 Wire reports screen to Yahrzeit backend
2026-05-26 Document Yahrzeit include modules
    [fixture_plate.scad]
2026-05-28 - scheduler moved to phase-based cron model - help/user-guide language updated for cron phases - Minhag help clarified: web app suggests crontab, does not install it - help pages/footer rendering cle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
    [minhag.ini]
2026-05-28 final version of the pixel_interface board
    [pixel_interface_v3-B_Cu.gbr, pixel_interface_v3-B_Mask.gbr, pixel_interface_v3-B_Silkscreen.gbr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]
2026-05-29 Refactor of several php files, creating include date_support.in.php Also refactored include/paniels.inc making that clearer
    [pixel_interface_v3.3mf]
2026-06-03 fixed issues in embedded .. debugged row/col in setPixel
    [LedWall.cpp, selftest.ino, yahrzeit_v3.ino]
2026-06-03 checked in the yahrzeit_pixel9 and yahrzeit_pixel12 boards into GIT
    [pblock.kicad_sch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]
2026-06-20 improved the PHP code for better readability and maintainability, added new images for LED indicators, and included a new policy file for yahrzeit settings. Also updated the documentation and TODO no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
2026-06-20 add count of yahrzeits in the current week, and use that to decide whether to run the
2026-06-21 major cleanup: add project README for GitHub landing page move scheduler/install notes into docs add appliance installer script remove obsolete attic/archive artifacts and deadwood rename add-to-priv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
    [names-length.csv, newxxx.csv, testing.csv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]
2026-06-21 moving everything to be more compact directories
    [controller BOM.xlsx, fixture_plate.scad, pblock.kicad_sch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]
2026-06-21 fixed geometry problems, separate out the display buffer layout, and add a README.md for the embedded code.
    [LedWall.cpp, YyzPixel.cpp, selftest.ino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]
2026-06-24 implemented the STATUS LED breathing effect on the Yahrzeit Controller Pixel Interface board, connected to pin D3 of the Arduino Uno R4 Minima. The LED now smoothly transitions in brightness over a p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
2026-06-29 Align firmware naming with Arduino style. new "breathingLed()" function to support breathing LED effect.
2026-07-02 add the D1 (LED) polarity note, for PCBway to solder this component
2026-07-07 a cleanup of the Hardware and embedded directories
    [controller BOM.xlsx, fixture_plate.scad, pixel_interface_v3.3mf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]
2026-07-09 a little cleanup
    [mount_flange.3mf, mount_flange.scad, mount_flange.stl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]
2026-07-13 - replace overlapping lighting policy flags with day/week observance - use the shared Shabbat-to-Shabbat policy across engine and views - remove some dead code, and improve comments in include/*.php 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
    [minhag.ini]
2026-07-18 Finalize documentation and organize project artifacts
    [mount_flange.3mf, uno_Ethernet_yahrzeit_case-cover.stl, uno_Ethernet_yahrzeit_case.3mf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]
2026-07-21 Audit release documentation and source comments
    Update the internal PHP map, README, and installer notes to match the
    current source tree. Correct file headers and document non-obvious
    function contracts, persistence paths, scheduling, and controller
    boundaries.
    Document the policy-equivalence test, add it to the required validation
    workflow, and record the known English-date year-boundary issue.
2026-07-22 Polish responsive layout and button feedback
    Add click acknowledgement to action buttons, compact the Yizkor
    controls, improve browser titles, and use a phone-sized CBS logo.
2026-07-22 Finalize controller installation and brightness
    Add the firmware installation guide and controller assembly photo.
    Send configurable normal and full-wall brightness values with controller
    command streams, and preserve them across appliance reinstalls.
    Remove the redundant clear command and update the controller, installer,
    and internal documentation.
2026-07-22 missing files in 3D Printing folder.
    [fixture_plate.stl]
2026-07-22 small rename of artifacts
    [yahrzeit_controller_case-cover.stl, yahrzeit_controller_case.scad, yahrzeit_controller_case.stl]
2026-07-23 corrected documentation in the the Hardware directory
    [controller BOM.xlsx, pixel_interface_v3.step, test_shield.step]
2026-07-24 Expand Yahrzeit hardware documentation
    Document the controller enclosure, reusable YYZ Pixel schematic, and current hardware hierarchy. Add the relevant Arduino, Ethernet, NUC, and schematic reference artifacts.
    [Arduino-Ethernet-Shield2-V2.brd, Arduino-Ethernet-Shield2-V2.sch]
2026-07-24 Identify and document controller release builds
    Report the firmware release, board model, display configuration, port, and build time through the controller diagnostics. Expand the controller installation and maintenance documentation with compone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
2026-07-30 updated configuration after installation (#1)
    [yahrzeits-rev4.csv]
2026-08-03 Added runtime single-board geometry and deterministic self-tests for YYZ Pixel board bench testing.
    - add temporary single-panel geometry for 6-, 8-, and 10-pixel boards
    - make LedWall consistently honor runtime geometry
    - alternate the checkerboard pattern between test runs
2026-08-04 Documentation revision, for fixing PIXEL boards
2026-08-06 small corrections, "cut ribbon cable pin 10"
2026-08-21 Add WireViz cable specifications
2026-08-21 improvements to cable specs
2026-09-10 Add Yahrzeit wall power and Pixel V2 designs
    [yahrzeit_power_dist.kicad_pcb, yahrzeit_power_dist.kicad_sch, yahrzeit_yyz_pixel-v2.kicad_pcb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]
2026-09-10 Document power board design follow-ups
2026-09-10 Keep power schematic PDF with KiCad project
2026-09-29 completed the power distribuiion board design
2026-10-08 new approach to cables
2026-10-12 Track printable hardware models and refresh hardware overview
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
